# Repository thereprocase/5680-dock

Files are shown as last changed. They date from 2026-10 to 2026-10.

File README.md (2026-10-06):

# Precision 5680 desk dock

A compact, hinge-down stand built around its cooling plenum. Two recessed fans draw from the laptop's hinge exhaust, and a captured USB-C plug makes the final sideways docking connection.

> **Current prototype:** D9 P5 is the active print build. It uses an 8° lean,
> modular contact cassettes, split plenums and printed connections. The plug
> positioner now rides a large-shaft face clamp: a hollow Ø50 shaft offset 25 mm
> from the accessory socket so the arm actually reaches the USB-C ports, a
> knurled Ø72 nut on a printed 47 × 3 thread, a leaf-lobe cam spatula that takes
> the docking push, and a carrier that clamps the plug on its overmold flats
> (`desk-dock/D9-P5/CLAMP-PIVOT-VALIDATION.md`). Physical fit, clamp torque,
> loading, cooling and acoustics are still being qualified. See the
> [project page](https://thereprocase.github.io/5680-dock/),
> [P5 notes](docs/printables/d9-p5/README.md) and
> [print log](https://thereprocase.github.io/5680-dock/prints/).

**17 September checkpoint:** the V4 full-height A/B/C fit kit (filed locally) is toolpath-verified and ready for a supported contact test. The reported seating failure remains unresolved. **D9 is unfinished**: its diagnostic duct failed enclosure/print geometry, and the next panel construction exists only as a plan. No D9 airflow or acoustic improvement has been demonstrated.

**[Handoff, evidence and ordered next steps](https://thereprocase.github.io/5680-dock/handoff-2026-09-17.html)** · [Detailed next-step list](docs/handoff/2026-09-17/NEXT-STEPS.md)

D8 remains the last complete CAD reference with the connector mechanism. The earlier nominal CAD/manufacturing checks below do not establish physical seating, strength or cooling.

**[Explore D8](https://thereprocase.github.io/5680-dock/)** · **[Download D8 STEP](docs/downloads/Precision_5680_D8_STEP.zip)** · **[Print + source package](docs/downloads/Precision_5680_D8_Review.zip)** · **[Assembly and adjustment](desk-dock/D8/README.md)** · **[P1S print guide](desk-dock/D8/PRINT_DESIGN.md)**

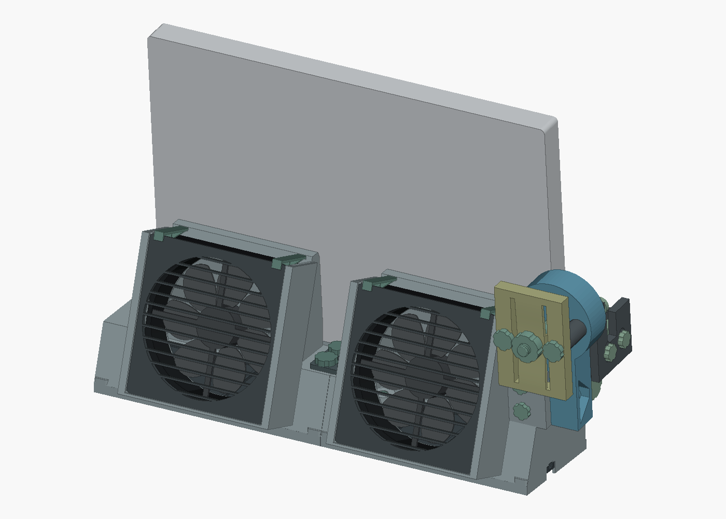
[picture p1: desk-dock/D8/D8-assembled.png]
D8 assembled dock with laptop envelope, recessed fans and removable connector module


## Form follows the load and the print

- **Removable connector module.** A keyed shoe and two accessible hand screws secure the complete mechanism. The cable cradle slides ±3 mm in Y, the saddle slides −4/+5 mm in Z, and an independent stop sets the laptop's X position. Adjust the existing parts directly.
- **Gravity through the shell feet.** Perimeter walls and dedicated feet carry the laptop. Bottom covers provide service access and clear the structural feet.
- **Lighter covers.** A 2 mm skin, perimeter ribs and compact fastening bosses reduce the two covers from about 180 g to 94 g of PETG—approximately 48% less plastic.
- **Serviceable fans.** Two nominal 120 × 120 × 25 mm fans sit behind flat slide-in grilles and replaceable clips. Documented clearances accommodate the researched frame sizes; a perimeter gasket is optional.
- **Deliberate print orientations.** All 43 manufacturing meshes specify a bed face and explain the layer-strength tradeoffs. Flat grilles and in-plane flexures print separately; shell ribs and underside ramps provide bridge landings and reduce overhangs.

The laptop retains its 5° lean, and the fans discharge 18° above the desk. The resettable face-cam hinge and printed preload spring remain. Their measured release force and warm creep still need testing.

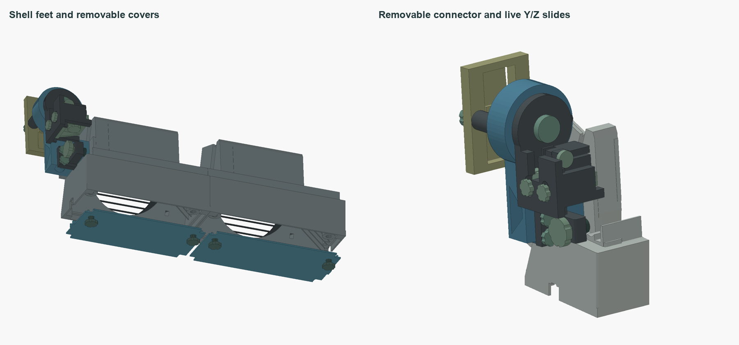
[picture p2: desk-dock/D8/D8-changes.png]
D8 shell feet and removable covers beside the connector module and live Y/Z slides


## Plastic and print preparation

The starting process is **P1S, PETG, 0.4 mm nozzle, 0.20 mm layers, five walls and six top/bottom layers**, with dense loaded mechanism parts. Use OrcaSlicer for the actual printer setup.

| Material estimate | PETG |
|---|---:|
| Finished CAD solid volume | 1.243 kg |
| Generic slice, including normal supports and individual brims | **1.659 kg** |
| First-build allowance, including some samples and reprints | **1.8–2.0 kg** |

The generic offline Cura screen estimates about 380 g of support and 25 g of brims at 1.27 g/cm³ PETG. Flexible contacts and startup waste are additional. These are planning figures; the final P1S profile controls actual use. Shell supports remain the largest print optimization opportunity. A reduced-support trial produced long roads in the wrong bridge direction, so its smaller material estimate was rejected.

## What the checks establish

All **83 assembly solids** pass CAD validity checks, with no unintended nominal rigid collisions. All **43 print meshes** are watertight and fit the recorded P1S envelope with an 8 mm brim. The 12 sampled laptop docking/withdrawal positions and listed module/cover service positions pass their clearance checks.

These checks do not establish physical strength or an approved P1S print job. Print fit samples first, inspect bridge direction and support removal, then test the complete holder. The ≤0.20 mm deflection at 20 N and nominal 50 N release remain test targets. See the [current results and remaining work](desk-dock/D8/CURRENT_STATUS.md).

## Build, inspect, continue

| Start here | What it contains |
|---|---|
| [D8 source and assembly](desk-dock/D8/README.md) | Editable CAD, adjustment and service instructions, regeneration commands |
| [Print design](desk-dock/D8/PRINT_DESIGN.md) | P1S process assumptions, every orientation and remaining support checks |
| [Print manifest](desk-dock/D8/print-manifest.json) | Per-part geometry, material, pose and mesh records |
| [Fan fit](desk-dock/D8/FAN_FIT.md) | Manufacturer dimensions, tolerances and clip allowance |
| [Generation provenance](desk-dock/D8/generation-provenance.json) | Source and export hashes tying the files to the checks |
| [Project context](PROJECT_CONTEXT.md) | Design decisions, coordinates, history and continuing work |

The STEP download is a lossless ZIP containing the complete CAD file. Individual STLs already use their manufacturing orientations. The source remains editable in CadQuery.

## Earlier revisions

The [archived D7 viewer](https://thereprocase.github.io/5680-dock/desk-dock-d7.html) and its [review archive](docs/downloads/Precision_5680_D7_Review.zip), earlier desk-dock studies and [original 5560 wall-mount overview](docs/history/5560-README.md) remain available as history. Use the D8 files above for current work. See [LICENSE](LICENSE).

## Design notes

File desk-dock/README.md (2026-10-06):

# Precision 5680 desk dock

Current local design: [D7 - recessed fans and hand assembly](D7/README.md).

5 degree laptop lean, 18 degree fan discharge, source-handed Thunderbolt ports, direct plenum support, recessed fan pockets, removable duct floors and hand controls. PETG on the P1S; print-oriented parts and fit samples are supplied. Slicing remains unverified after application startup failures.

[Port study](D6/PORT_STUDY.md) · [Compact-depth airflow screen](D6/AIRFLOW_STUDY.md) · [Viewer](../docs/desk-dock.html)

D1-D6 are retained as history. D5 has a known mirrored port layout. Use the repository root Open-Desk-Dock.ps1 launcher for the local viewer.

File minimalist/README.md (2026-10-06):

# Minimalist M1.1 native fork

M1 is an independent open-frame prototype derived through a FreeCAD Save As of
the preserved Rev H document. Its arms, fan cradles, caps, dam and hardware are
new. No prototype arm freeze applies to this fork or to future ducted designs.

[Illustrated print and assembly guide](https://thereprocase.github.io/dell-5560-wall-mount/minimalist-guide.html) ·
[Interactive dimensioned examples](https://thereprocase.github.io/dell-5560-wall-mount/#m1-model) ·
[Nominal package](../docs/downloads/Minimalist_M1_5560.zip) ·
[Fit coupon package](../docs/downloads/Minimalist_M1_Fit_Coupons.zip)

## Reinforced wall transition (M1.1)

Each wall pad is now 32 mm tall with two 6 mm webs tapering 16 mm forward.
The webs reach the flat print face through the arm’s full thickness, filling
the adjacent window roots. Existing arm material, bolt centers, bores and
print orientation are preserved. The dam has a matching tapered clearance
notch; all six sizes pass all nine indexed positions.

When upgrading, replace arms 01/02 and optional dams 07/08 together. The other
sixteen parts are geometrically unchanged. The nominal full set is 400.55 g /
15 h 42 m 30 s in Orca, adding 12.50 g / 17 m 36 s compared with M1.0.
See the [illustrated comparison](../README.md#m11-carry-the-wall-pad-into-the-arm)
and `reports/wall-transition-review.json` for native layer sections and limits.
The 192 to 416 mm² section increase is not a tested strength multiplier.
To reproduce that comparison, extract `minimalist/presets/` from commit
`64fc1aa` to a separate directory, then run `wall_transition_review.py` with
`--baseline-dir` pointing to its six original preset directories. The current
native files stay untouched. `plot_wall_transition.py` renders the report.

## Open and edit

Open `Laptop_Wall_Mount_Minimalist.FCStd` in FreeCAD 1.1. The model contains
55 fully constrained sketches, stock Part construction features, a shared
Spreadsheet and 20 installed App::Links. It has no custom feature proxy that
must be installed to reopen or recompute it. Construction history is grouped by
part family; the installed assembly is separate from the hidden source features.

Open **M1 / Design parameters**, edit the blue measured case inputs, recompute,
and Save As a new file. Gray cells are derived. The parameter sheet documents
the 0.30 mm printed fit clearance and intentional split-crown interference.
The reference uses a 344.4 × 230.3 × 20 mm closed case, a 40 mm wall gap and
separate 2 mm compliant pads. The two cradles accept the modeled 120 × 120 ×
27 mm fan envelope and point it 45° up the rear gap.

The six checked examples in `presets/` span 304–400 mm case width, 210–275 mm
depth and 16–28 mm thickness. They are specific dimensioned examples, not a
continuous certified compatibility range. Screen diagonals are labels only.
Each preset has nine checked dam positions, indexed 0–8 on a 12 mm ladder.
All six delivered files also passed a live GUI open check with the installed
assembly visible and the source construction hidden.
The key engages two rungs 24 mm apart; both sides must use the same index.

## Files and plates

- `presets/<name>/M1.FCStd`: saved/reopened native preset.
- `presets/<name>/print/01–20`: individual oriented STEP, STL and standard 3MF.
- `21_all_hardware`: one plate containing all twelve parts numbered 09–20.
- `22_hardware_without_dam`: eight hardware parts; use with 01–06 for seven
  plates when omitting the optional dam.
- `M1_assembled.step`: installed assembly for inspection, not a print plate.
- `coupons/00_fit_coupon_plate`: compact samples of the actual key, keeper,
  arm/carriage, fan-hanger and cap-pin interfaces in their full-part build directions.
- `reports/release.json`: settings, slice estimates, source hashes and checks.
- `reports/toolpaths/`: deposited-path measurements and source G-code hashes.
- `section-review.json`: explicit load assumptions and nominal stress demand.

Print one each of 01–08 plus 21, for nine plates. Files 09–20 are replacement
alternatives; do not also print them. STEP, STL and geometry-only 3MF represent
the same part. The standard 3MFs have no slicer settings or G-code.

Each delivery ZIP includes an offline illustrated guide, native model, print
files, separately labeled Orca previews, settings and verified SHA256SUMS.
Nothing has been sent to a printer. Start with the coupon and your actual
ASA spool profile in OrcaSlicer; see the guide for orientation and assembly.

## Reproduce the checks

FreeCAD-side scripts use the application's bundled Python/modules. On Windows,
for example, use `"C:\Program Files\FreeCAD 1.1\bin\python.exe"` in place of
`FREECAD_PYTHON` below. Run from the repository root. Python paths are examples;
use the installation path on your machine.

```text
FREECAD_PYTHON minimalist/validate.py
FREECAD_PYTHON minimalist/presets.py
FREECAD_PYTHON minimalist/coupons.py
FREECAD_PYTHON minimalist/section_review.py
FREECAD_PYTHON minimalist/export_scene.py
```

Headless preset saves preserve the original GUI payload order through
`preserve_gui.py`, leaving geometry and parameter streams intact. Run
`gui_presets.py` from FreeCAD’s GUI Python environment to repeat the display
check before packaging regenerated files.

The construction builder is incremental and preserves existing part families.
For a clean reconstruction that leaves the delivered model untouched:

```text
FREECAD_PYTHON minimalist/build.py all --target minimalist/scratch/Rebuilt_M1.FCStd
FREECAD_PYTHON minimalist/validate.py --source minimalist/scratch/Rebuilt_M1.FCStd --output minimalist/rebuild-validation.json
FREECAD_PYTHON minimalist/compare_rebuild.py
```

`slice_models.py` uses the official Orca CLI and flattens its bundled P1S,
0.20 mm and ASA profiles. It preserves orientation/placement and never sends
a print. Example for the nominal set, with paths to your Orca installation:

```sh
python3 minimalist/slice_models.py --orca /path/to/OrcaSlicer \
  --profiles /path/to/resources/profiles/BBL \
  --output minimalist/slices/5560 \
  minimalist/presets/5560/print/0[1-8]*.stl \
  minimalist/presets/5560/print/21_all_hardware.stl
```

Repeat for each preset and the coupon. `audit_plates.py` requires Shapely and
Matplotlib. It analyzes all deposited path types, and reuses a result only when
the parsed path geometry, feature types, layer heights and widths are identical.
The package builder requires all six sets and the Rev H comparison slices:

```text
python3 minimalist/audit_plates.py
python3 minimalist/package_release.py --revh-slices /path/to/revh/comparison/slices
```

`browser_review.cjs` uses Playwright from `freecad/showcase/tooling` and Windows
Edge to check both interactive models, all presets, dam movement, mobile layout
and downloads. Install that folder's lockfile dependencies if needed, serve
`docs/` locally, then run it with the preview URL and `--full`.

## Evidence limits

Native validation checks valid one-solid parts, constrained sketches, unintended
part overlap, minimum intended interface gaps, rectangular case/fan envelopes,
wall intrusion and sampled removal motions. All nine dam indices are checked;
case and fan removal samples are run at the two end indices. A clean CAD result
does not prove a continuous insertion path with cables or real protrusions.

Orca's Bridge label excludes some slot roofs generated as Overhang wall. The
expanded toolpath report therefore includes every deposited feature type and
retains bridge-tagged and all-feature maxima separately. Prior-layer support is
estimated from reported line width with at least 0.05 mm overlap. Same-layer
anchoring order, adhesion and physical sag are not proven. Use the fit coupon
to check the key-slot roofs and the fan hanger before the full print.

The section review assumes a 3 kg case, twice gravity and equal arm loading.
It calculates net upright areas and section moments from native solid slices.
The peak nominal axial-plus-bending demand is about 1.11–1.24 MPa across the
examples. This excludes local stress concentration, shelf/fastener FEA, ASA
allowables, creep, temperature and layer adhesion; it is not a load rating.

Physical fit, printed retention, wall anchors, long-term deformation and cooling
performance remain unqualified. M1 has no CFD or cooling benchmark. Rev F's
exploratory CFD must not be presented as a result for M1 or Rev H.

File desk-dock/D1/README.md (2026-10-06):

# Precision 5680 / hinge-down extraction dock

**Superseded orientation:** [D3](../D3/README.md) corrects the reversed port end. Use [D4](../D4/README.md) for the current CAD and docking animation.
[STEP review package](Precision_5680_D1_Review.zip) · [Connector adjustment](adjustment.png) · [Air-path section](air-path.png) · [Source geometry](reference-evidence.png)

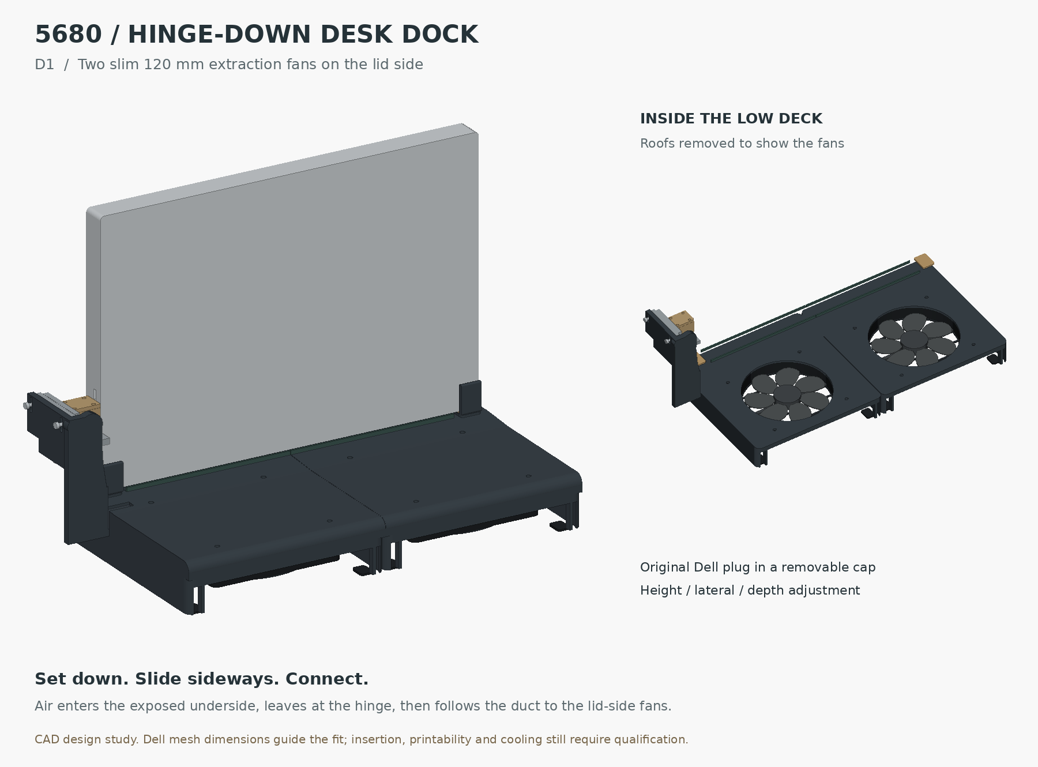
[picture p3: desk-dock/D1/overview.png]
D1 installed and with fan-chamber roofs removed


Set the closed laptop into the corner bearings, **hinge down**, then slide it
sideways into the captured SD25TB5 plug. Two slim 120 mm fans lie flat on the
**lid side**, pulling from a duct that curves underneath the hinge. The broad
underside intake remains exposed. A skirt directs the fan discharge toward the
lid side along the desk.

The main deck reaches **50 mm above the desk**. The rear-case bearing datum
sits at 54 mm; the selected port center sits at about 120 mm. The small plug
support tops out at 135 mm, only 81 mm above the rear-case datum. The modeled
overall footprint is approximately 406 × 188 mm, including the plug support.
The fan housings add useful desk bearing width on the lid side.

**D1 is a developed CAD study, not a print release.** The actual duct passage,
mounting bores, adjustment clearances and separate load stop are modeled.
Fastener/nut retention, all attachment details, strain relief, liner compression,
automatic lift protection and physical thermal/fit qualification remain open.

## Fine adjustment after assembly

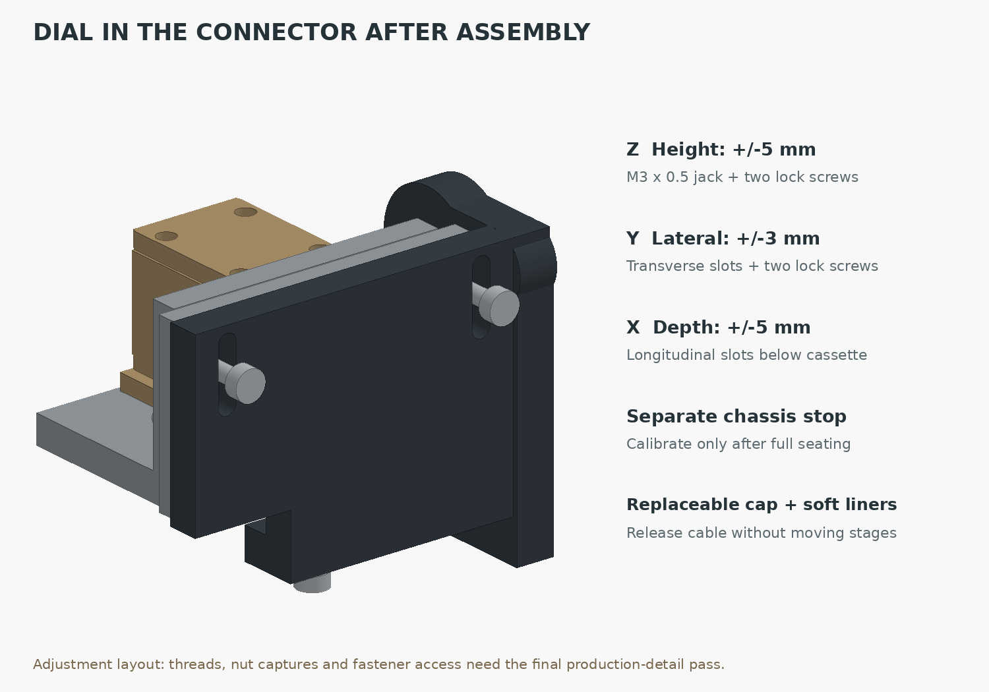
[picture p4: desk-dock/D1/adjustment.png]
Connector cassette and its adjustment stages


| Axis | Adjustment | How it stays put |
|---|---|---|
| Z: port height | M3 × 0.5 jack, ±5 mm; 1 turn = 0.5 mm | Two independent face clamp screws |
| Y: position across laptop thickness | Transverse slots, ±3 mm | Two independent clamp screws |
| X: engagement depth | Longitudinal cassette slots, ±5 mm | Two screws through the bottom shelf |
| Laptop travel limit | Independent M4 chassis stop | Locknut; soft contact tip |
| Plug replacement | Removable cap | Carrier settings remain fixed |

The adjustment range is for setup; the stages lock before everyday docking.
The cap holds replaceable compliant liners around the overmold. The modeled
rear shoulder bears on the transition to the strain-relief neck. A proposed
0.8 mm metal face clip captures the front shoulder without requiring a thick
printed wall between the plug and laptop. Its fabrication and attachment need
detailing; its thickness must be included when setting full engagement.

An initial setup uses the actual laptop as the alignment jig: retract the
chassis stop, seat the laptop on its bearings, leave the stages just loose
enough to move, and engage the plug by hand. Set Z and Y without side load,
set X for normal full engagement, lock the stages, then bring the independent
stop to the chassis. Slide out and repeat before normal use. The USB-C shell
must never function as the bearing, alignment funnel or end stop.

The ±5 mm Z range targets the **nearer** Thunderbolt port. Using the second
port requires changing the nominal height by about 16.2 mm in the CAD; the
fine-adjustment range does not span both ports. Angular setup error is handled
by the compliant cassette liners and guide fit, not by claiming a rotary stage.

## What the online geometry established

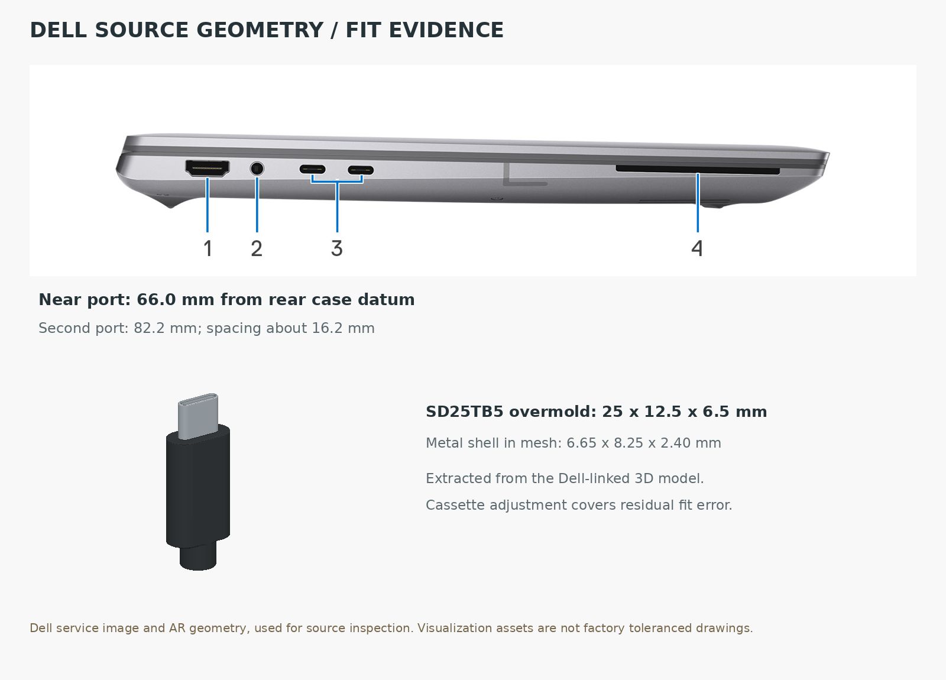
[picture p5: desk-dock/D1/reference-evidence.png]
Dell service side image and extracted plug mesh


Dell's product pages link actual glTF assets for their 3D/AR viewers. We
downloaded those, applied the laptop scene transforms, and extracted the
connector meshes. The laptop body width in the model is 353.680 mm, matching
the published width. These are visualization assets, not toleranced factory
drawings; the mechanical adjustments deliberately cover residual error.

| Feature | Extracted result | Basis |
|---|---:|---|
| Near left Thunderbolt center | 65.98 mm from rear **base-cover** datum | `Dell4768` transformed bounds |
| Other left Thunderbolt center | 82.19 mm from same datum | `Dell4694` transformed bounds |
| Port spacing | 16.21 mm | Difference between centers |
| SD25TB5 main overmold | Approximately 20 × 12.5 × 6.5 mm | `Cube_8`; excludes 5 mm neck |
| Overmold plus neck length | 25 mm | Full `Cube_8` bounds |
| Exposed metal shell | 6.65 × 8.25 × 2.40 mm | `Cube_9` bounds |

Scaling Dell's service side image against 240.33 mm depth independently gives
approximately 66.03 and 82.18 mm. That agreement supports the layout, but does
not turn the images into a production tolerance. The outer hinge lip projects
past the rear base-cover datum; bearing pads support the case corners and
leave the hinge/exhaust region relieved. The reference laptop remains a
simplified closed envelope rather than an exact manufacturer solid.

[Raw extraction record, source URLs and SHA-256 hashes](reference-extraction.json).
The extraction script records the vertex bounds and source image pixel picks.

## Suction below the hinge

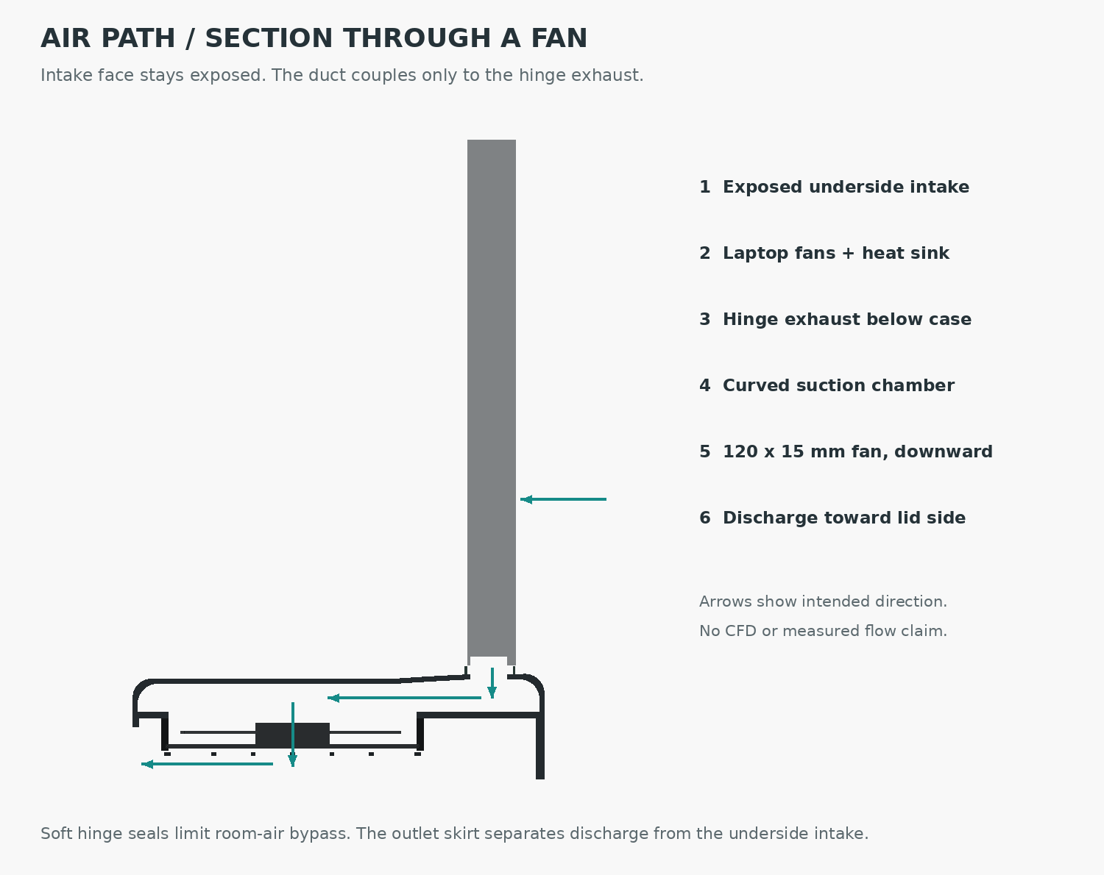
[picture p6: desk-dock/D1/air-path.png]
Section through the first fan


The intended flow follows the laptop's existing forced ventilation direction:
room air enters the exposed underside grille, the internal blowers drive it
through the heat sink, and the external fans lower the pressure in the chamber
at the hinge exhaust. Hinge-down operation does not create a passive chimney;
this concept relies on the laptop's blowers and the powered extraction fans.
The service illustrations support this flow-path interpretation, but they do
not supply internal fan curves or quantify the chassis resistance.

The curved chamber covers the exhaust region only. Thin replaceable sealing
lips limit room-air bypass around the hinge. They carry no laptop bearing
load. The two chambers use one fan each, with the fan faces entirely on the
lid side. Their outlet skirts block direct discharge toward the intake face.

The dimensional baseline is two **Noctua NF-A12x15 PWM** fans: 120 × 120 × 15 mm,
105 mm hole spacing, 12 V. Noctua lists 55.44 CFM free-air flow and 1.53 mm H₂O
(about **15 Pa**) maximum static pressure per fan. Those are opposite endpoints,
not simultaneous performance. Two fans in parallel add available flow; they do
not double maximum pressure. The model uses generic rotor geometry and colors.
If retaining the manufacturer's vibration pads, allow the additional pad
thickness and set the fan-deck gasket accordingly.

At an **assumed** total 20 CFM, the roughly 5,000 mm² under-hinge opening would
carry about 1.9 m/s, with about 2.1 Pa velocity pressure. Losses through the
turn, grille, desk outlet and seal leakage consume part of the fan's small
pressure budget. This is a dimensional estimate, not a solved operating point.
For scale, a 0.5 mm equivalent gap around a 634 mm seal perimeter would bypass
about 1.8 CFM at an assumed 10 Pa suction (Cd 0.65; air density 1.2 kg/m³).
A 3 mm gap would bypass about 10.7 CFM under the same assumptions. A good hinge
interface matters more than adding unrestricted fan capacity.

Use a regulated 12 V supply and a PWM controller/splitter for the fan pair;
final harness routing and retention remain to be designed. Test one and both
fans off as well as normal operation: the duct must not worsen the baseline
when the external fans stop. No new CFD or measured cooling result is claimed.

## Checks completed and remaining work

- Each exported component is a valid solid, and the STEP reimports successfully.
- The rigid custom parts have no unintended intersections in the nominal CAD.
- The five principal adjustment parts clear one another at 27 sampled
  combinations of the specified X/Y/Z limits. The screen excludes the laptop,
  fastener head access and nut engagement; it does not prove precise insertion.
- The source images, plug mesh and rendered CAD views were inspected.

[Machine-readable validation](validation.json) · [Part geometry](geometry.json).
The two fan modules suit a segmented P1S build, but the left deck with its
integrated connector support still needs a build-orientation and bed review.
Use OrcaSlicer, the repository default, for the production detailing pass.

Next physical checks: align and lock the connector; verify engagement and
withdrawal without shell loads; test retention and accidental lift; qualify
the desk restraint and warm printed structure; measure chamber pressure and
laptop CPU/GPU temperatures/power at the same workload with the external fans
off, low and high. Until an interlock is detailed, disconnect sideways before
lifting. A fit coupon should precede the complete print.

## Sources

- [Dell Precision 5680 product page](https://www.dell.com/en-us/shop/dell-laptops/precision-5680-workstation/spd/precision-16-5680-laptop): published envelope and discovery of the [Dell-linked laptop mesh](https://content.hmxmedia.com/precision-16-5680-laptop-AR/gltf/precision-16-5680-laptop-AR.glb).
- [Dell 5680 left view](https://www.dell.com/support/manuals/de-ch/precision-16-5680-laptop/precision-5680-owners-manual/left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): identifies the two Thunderbolt ports and supplies the side image.
- [Dell 5680 Owner's Manual](https://dl.dell.com/content/manual19946365-dell-precision-5680-owner-s-manual.pdf?language=en-us), pages 55 and 59: internal fan and heat-sink geometry; base-cover illustrations show the exposed intake grille and hinge region.
- [Dell SD25TB5 product page](https://www.dell.com/en-us/shop/dell-pro-thunderbolt-5-smart-dock-sd25tb5/apd/210-brqs/docks): discovery of the [Dell-linked dock/plug mesh](https://content.hmxmedia.com/dell-pro-sd25tb5-dock-AR/gltf/dell-pro-sd25tb5-dock-AR.glb).
- [Noctua NF-A12x15 PWM specifications](https://www.noctua.at/en/products/nf-a12x15-pwm/specifications): fan envelope, voltage and pressure/flow endpoints.

## Rebuild

Python 3.12, CadQuery 2.8, NumPy, Pillow and trimesh:

```bash
python desk-dock/D1/extract_references.py /tmp/dell5680-references
python desk-dock/D1/build.py
python desk-dock/D1/validate.py
```

`parameters.json` holds the design values. The source downloads stay outside
the deliverable; the repository retains the attributed inspection image and
dimension/hash record. D0 remains available through Git history.

## Revision brief

The user rejected D0's appearance and specified hinge down, a low profile,
two 120 mm fans that create suction below the hinge, and online reconstruction
of the required hardware geometry. They then placed the fans on the lid side
with a duct that curves below the machine and requested port fine adjustment
after fabrication. D1 implements that architecture and replaces D0 as the
current design study.

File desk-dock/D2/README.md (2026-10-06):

# Precision 5680 desk dock — D2

**Superseded orientation:** [D3](../D3/README.md) corrects the reversed port end. Use [D4](../D4/README.md) for the current CAD and docking animation.
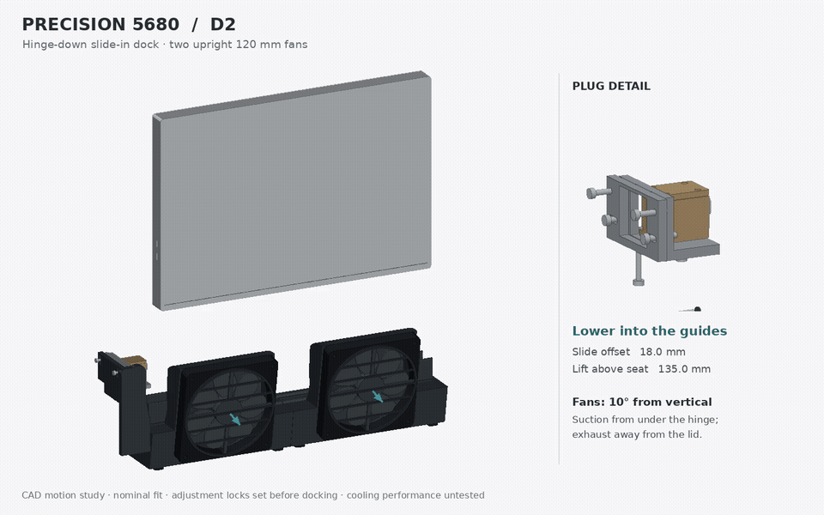
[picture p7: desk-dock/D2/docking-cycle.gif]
Docking cycle


[Full-resolution MP4](docking-cycle.mp4) · [STEP and editable source package](Precision_5680_D2_Review.zip) · [Poster](overview.png)

Two 120 × 120 × 15 mm fans now stand **10° from vertical** on the lid side. Their suction faces connect to two curved pods fed by the low manifold beneath the hinge. Their discharge points away from the laptop, 10° down. The broad underside intake face stays exposed. The fan tops reach approximately 131 mm; the connector support reaches 135 mm. The laptop's rear-case bearing datum remains 54 mm above the desk, with the selected port center approximately 120 mm above the desk.

The animation uses the actual D2 CAD solids and fixed cameras. It shows lowering at an 18 mm lateral offset, sliding toward the original SD25TB5 plug, pausing docked, withdrawing 18 mm, then lifting. A synchronized close-up shows the connector approach. The 135 mm lift is a presentation distance, not a required docking stroke. Arrows indicate intended discharge direction, not measured airflow.

The hinge corner bearings are longer so both ends stay supported throughout the 18 mm slide. The inherited connector shelf was shortened to remove an interference found during the docking-path check. The original cable overmold remains captured by a removable cap and front clip. Independent depth, transverse and height adjustments retain the D1 nominal ranges: ±5, ±3 and ±5 mm. Set and lock these before docking; the separate chassis stop controls final travel. Only the nominal adjustment setting is animated.

## Evidence and limits

Dimensions and selected port location retain the [D1 Dell reference extraction](../D1/README.md) and [reference evidence](../D1/reference-evidence.png). These come from Dell-linked visualization assets and service images, not toleranced manufacturing CAD. Laptop and cable bodies are simplified envelopes. The dock electronics remain external; this design captures its host cable plug.

`validation.json` records a changed-geometry screen: individual solid validity, STEP round-trip validity, stationary custom-part and fan-envelope intersections, and 12 laptop positions through the nominal lower/slide path. Intentional internal overlaps among the schematic fan components are excluded. This is sampled envelope screening, not a continuous swept-volume or physical mating qualification.

**CAD motion study, not a print release.** Fan mounting fasteners, guard attachment, split-manifold joinery, seals, cable strain relief, anti-tip behavior, printed fits and load testing still need production detailing. Actual full USB-C engagement must be calibrated on the hardware without using the connector as a structural stop. Air leakage, fan/system operating point and temperature benefit have not been tested. D1 adjustment-range screening is historical evidence; the complete D2 adjustment sweep has not been requalified.

## Reproduce

With Python, CadQuery 2.8, NumPy, Pillow and ffmpeg installed:

```sh
python build.py
python validate.py
python animate.py
```

`animate.py` writes 114 frames at 12 fps (9.5 seconds), a full-resolution 1440 × 900 MP4 and a looping 960 × 600 GIF. The review archive contains the STEP, parameters, CAD and rendering sources, validation results and poster. Animation files are linked separately. Use OrcaSlicer for subsequent print preparation, per repository guidance.

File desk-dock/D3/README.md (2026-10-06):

# Precision 5680 desk dock — D3

**Superseded by [D4](../D4/README.md):** retains this orientation, reverses the fan lean to 15° upward exhaust, and enlarges the rounded air passages.

D3 corrects the laptop handedness to match the supplied desk photograph. The laptop sits to the user's left, hinge down, with its lid facing the user. Its **keyboard-left ports sit at the far end: the right edge in the lid-facing photograph.** D1 and D2 placed that edge on the wrong end.

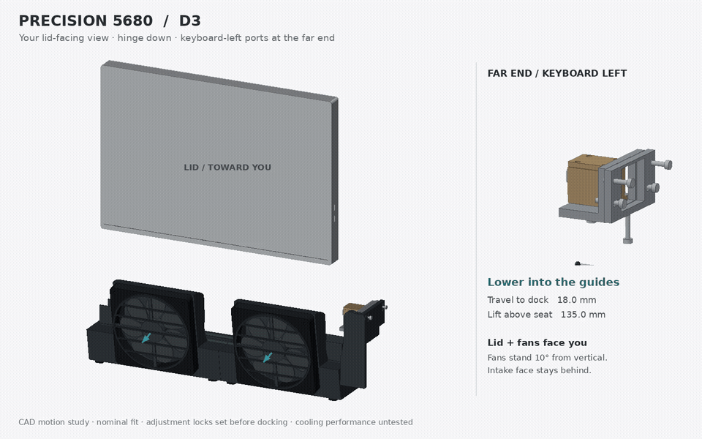
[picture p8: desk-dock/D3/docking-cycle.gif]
Corrected docking cycle, viewed from the lid side


[Full-resolution MP4](docking-cycle.mp4) · [STEP and editable source package](Precision_5680_D3_Review.zip) · [Poster](overview.png)

## Orientation and movement

| Feature | Correct placement |
|---|---|
| Hinge | Down, in the trough |
| Lid | Toward the seated user |
| Underside intake grille | Behind the laptop, opposite the user and fans |
| Two 120 mm fans | Lid/user side, 10° from vertical |
| Keyboard-left Thunderbolt ports | Far end; photo right |
| SD25TB5 host cable clamp | Beyond that far edge, pointing back into the laptop |
| Dock | Lower into the guides, then slide toward the far plug |
| Undock | Withdraw toward the near end, then lift |

The exported CAD uses +X toward the far/plug end, +Y toward the lid/user/fans, and +Z upward. The near laptop edge is x=0; the far edge is x=353.68 mm. Docking moves the laptop from x-offset −18 mm to 0; removal reverses this. The 135 mm lift in the animation illustrates removal and is not a required docking stroke.

D3 reflects the actual CAD solids across the laptop's mid-width plane, including the port openings, plug, adjustment stages, chassis stop, extended bearings and ducts. It does not merely reverse the animation camera. `build.py` explicitly separates the inherited D2 construction coordinates from the corrected exported frame. The two fan centers remain symmetric; the cable support moves to the far end.

## Retained design

The rear-case bearing datum stays 54 mm above the desk. The selected port center stays approximately 120 mm above the desk. Two curved suction pods connect the under-hinge manifold to the near-vertical fans, which discharge toward the lid/user side, 10° down. The underside intake remains exposed. The plug retains independent depth, transverse and height adjustments, with nominal ranges ±5, ±3 and ±5 mm, and an independent chassis stop. Lock the adjustments before docking.

The supplied photograph establishes orientation, not scale. Laptop and plug dimensions retain the [Dell-linked D1 reference extraction](../D1/README.md) and [geometry evidence](../D1/reference-evidence.png). The laptop and cable remain simplified reference envelopes; the dock electronics remain external.

## Verification and limits

The geometry check verifies both far-edge port voids, corresponding solid near-edge locations, the far-side plug shell, and fan positions on the lid side. This checks the handedness separately from collision screening: a mirrored model can pass ordinary clearance checks.

The corrected assembly contains 53 valid solids and survives STEP export/import. Custom rigid parts and fan envelopes have no detected nominal intersections. Twelve sampled laptop positions along the corrected lower/slide path have no detected collisions. `validation.json` records these results. Intentional overlaps within schematic fan references are excluded.

**CAD motion study, not a print release.** Physical USB-C engagement, complete adjustment travel, fan and guard attachment, manifold joinery, seals, cable strain relief, stability, printed fits and loads still need qualification. Intended airflow arrows do not establish cooling benefit. The supplied desk photograph is not included in the repository.

## Reproduce

Use Python with CadQuery 2.8, NumPy, Pillow and ffmpeg:

```sh
python build.py
python validate.py
python animate.py
```

The animation runs 9.5 seconds at 12 fps. The MP4 is 1440 × 900; the looping GIF is 960 × 600. The review archive includes the STEP, source, parameters, validation, report and poster; animations are separate. Use OrcaSlicer for subsequent print preparation.

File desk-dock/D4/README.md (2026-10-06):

# Precision 5680 desk dock — D4

**Superseded by [D5](../D5/README.md):** retains the upward-exhaust concept and adds profiled fixed guides, open ribs and rubber-foot sweep clearance.

The fans now exhaust **15° above the desk**, with their tops leaning toward the laptop. D4 also enlarges the plenum, widens and rounds the hinge openings, and replaces the close flat guard with a spaced rounded-wire guard. The corrected orientation remains: hinge down, lid and fans toward the user, keyboard-left ports at the far end (photo right).

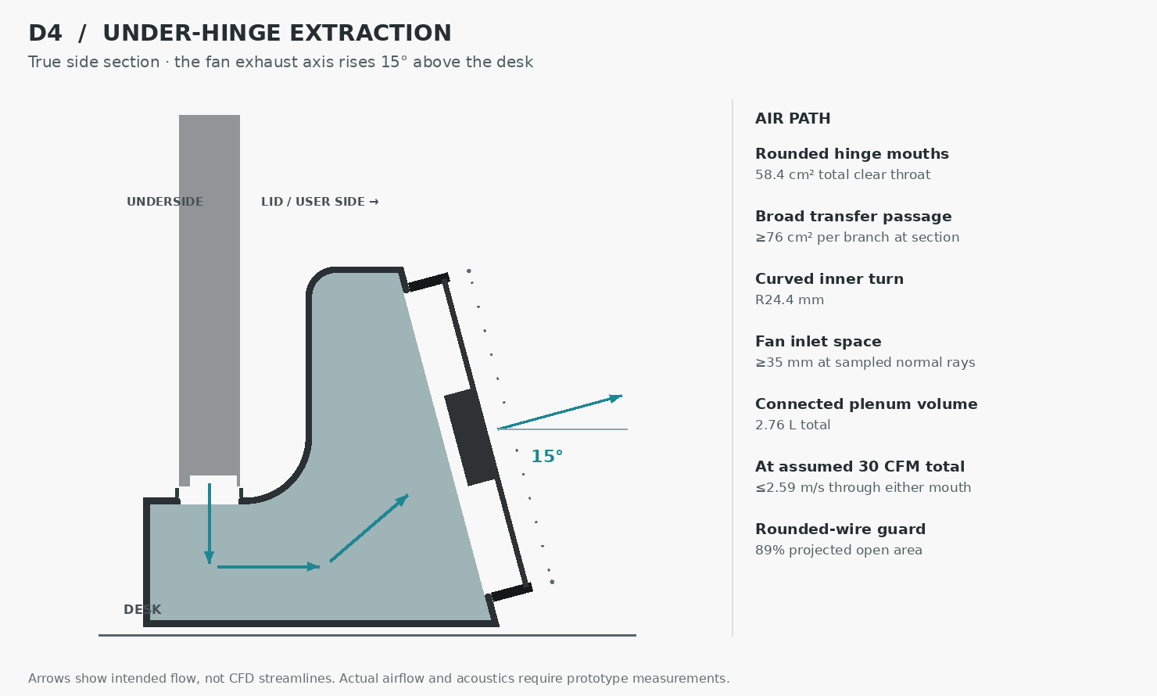
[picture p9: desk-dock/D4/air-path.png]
Side section through the hinge and one fan


[Docking animation](docking-cycle.gif) · [Full-resolution MP4](docking-cycle.mp4) · [STEP and source package](Precision_5680_D4_Review.zip) · [Installed view](overview.png)

## Air passage sizing

**Design basis: 30 CFM total**, assuming 15 CFM per fan. This is a sizing target, not a measured or predicted operating point. The table reports dimensions from the CAD and the smaller branch where branches differ.

| Feature | D4 geometry / screen |
|---|---:|
| Total connected cavity volume, both independent branches | 2.76 L |
| Hinge throat clear area | 5,840 mm² total |
| Individual mouths | 130.84 × 21 and 148.54 × 21 mm |
| Mouth corner / edge radii | R4 / R1 mm |
| Transfer section at y=15 mm | 7,566 / 8,312 mm² |
| Inner curved turn | R24.4 mm |
| Fan inlet axial clear space | 57 mm |
| Minimum inlet clear space across 81 sampled normal rays per fan | 35 mm |
| Fan aperture | Ø113 mm, rounded R1 at wall edges |
| Guard wire / pitch | Ø1 / 9 mm, 8 mm gaps |
| Guard plane beyond discharge face | 7.5 mm |
| Guard projected open area within fan aperture | 88.8% |
| Hinge bearing datum above desk | 54 mm, retained |
| Fan-pod height | 134 mm |

The wider plenum adds depth on the desk rather than lifting the laptop. The two cavities remain separate and each connects its hinge mouth to one fan. The 21 mm opening fits beneath the closed laptop envelope; replaceable soft lips flank it. The broad intake grille stays exposed behind the laptop. Gaskets and seam sealing must prevent narrow bypass jets and leakage that would divert suction from the hinge.

## Flow and pressure screen

We use continuity, `v = Q/A`, and local velocity pressure, `q = ρv²/2`, with air density 1.2 kg/m³. Each branch receives half the assumed total flow. The smaller branch governs.

| Assumed total flow | Maximum mouth velocity | Estimated external duct loss, smaller branch |
|---|---:|---:|
| 20 CFM | 1.73 m/s | 1.4–3.4 Pa |
| 30 CFM | 2.59 m/s | 3.2–7.6 Pa |
| 40 CFM | 3.45 m/s | 5.7–13.5 Pa |

Loss estimates combine assumed entrance, slot-jet mixing, turn, roughness, guard and discharge terms. `airflow.py` records their reference areas and sensitivity coefficients; `airflow-sizing.json` records the geometry and results. These bounds are engineering assumptions, not coefficients calibrated to this enclosure. They exclude the laptop grille, heat sinks, internal blowers and seal leakage.

The [Noctua NF-A12x15 PWM](https://www.noctua.at/en/products/nf-a12x15-pwm/specifications) lists 55.44 CFM maximum free-air flow and approximately 15 Pa maximum static pressure. Those are separate endpoints. Two parallel fans do not double the available pressure, and the 15 Pa endpoint does not establish pressure available at our target flow. Without a fan/system curve intersection or prototype measurements, the model cannot confirm 30 CFM. The 40 CFM case shows why simply running harder can consume most of the available pressure and increase noise.

## Noise provisions

The design uses broad openings with rounded corners and rolled edge radii, a curved return passage, inlet clearance across the fan face, an open discharge, and round guard wires spaced from the rotor. These choices follow the mechanisms described in [Fantech's installation guidance](https://www.fantech.com.au/Content.aspx?ContentID=L5&category=dos-and-donts): inlet restrictions and uneven flow can reduce performance and increase noise; ample inlet boxes and shaped entrances help. [Greenheck's system-effect guidance](https://www.greenheck.com/resources/blog/understanding-fan-system-effects) likewise emphasizes uniform entry and exit flow. This compact plenum does not provide the full straight-run or one-diameter clearance used by ideal installations.

Rounded entrance losses depend on geometry. [Purdue's minor-loss notes](https://engineering.purdue.edu/~wassgren/teaching/ME30800/NotesAndReading/PipeFlows_Losses_LectureNotes.pdf) supply the generic framework; the R1 lip here does not justify adopting the ideal well-rounded entrance coefficient. The pressure screen deliberately retains a wider assumed coefficient range.

**These provisions reduce likely noise sources; they do not prove whistle-free operation.** Print ridges, seal gaps, the laptop's actual exhaust openings, rotor tones and cavity resonance can still matter. Finish the inlet radii smoothly, keep seams flush and sealed, isolate fan mounts, and sweep PWM through the intended range on the prototype. Measure actual branch flow and suction pressure alongside sound and laptop temperatures. Check fans-off behavior too. If a tone appears, locate its source before changing speed or geometry.

## CAD and motion verification

D4 exports and reimports 53 valid solids. Nominal custom-part and fan-envelope intersections are clear; 12 sampled laptop positions pass the lower/slide/withdraw/lift screen. Separate checks verify the two far-edge ports and plug location. The animation still lowers at an 18 mm offset, slides toward the far plug, withdraws toward the near end, then lifts. Height, transverse and depth adjustment remain independent, with a separate chassis stop.

Laptop and plug dimensions retain the [Dell reference evidence](../D1/reference-evidence.png); the supplied photograph corrected handedness and was not used as a scale reference. The simplified laptop envelope does not establish the actual free area of its exhaust grille.

**CAD development study, not a print release.** Guard attachment, fan fasteners, manifold joinery, seals, cable strain relief, printed fit, stability and structural loads still need production detailing and physical qualification. The wire guard represents fabricated or bought metal hardware; it is not an instruction to print 1 mm guard rods.

## Reproduce

Python, CadQuery 2.8, NumPy, Pillow and ffmpeg:

```sh
python build.py
python validate.py
python airflow.py
python section.py
python animate.py
```

Use OrcaSlicer for subsequent print preparation. The STEP/source archive includes the calculations, section, poster and validation; animation files are linked separately. D1–D3 remain as revision history. D4 is the current design.

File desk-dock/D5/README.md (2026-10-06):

# Precision 5680 desk dock — D5

D5 uses **profiled fixed cheeks and an open rib frame**. The laptop leans 2° toward its lid-side guides, lowers into flared entries, then slides toward the far-end SD25TB5 plug. Rounded fan bezels, softened rear base corners and a removable adjustment cover clean up the enclosure.

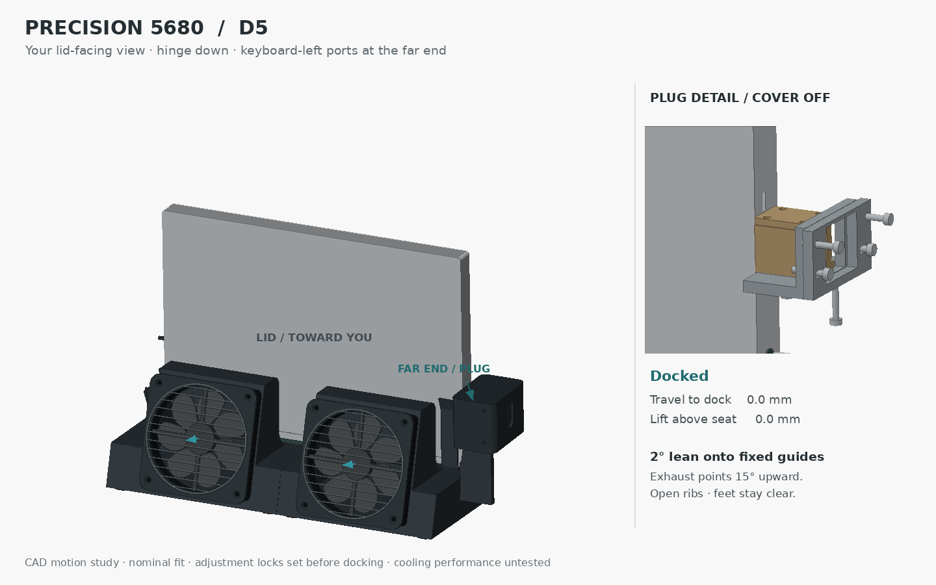
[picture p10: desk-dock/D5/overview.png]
Lid-side view


[Docking animation](docking-cycle.gif) · [Full-resolution MP4](docking-cycle.mp4) · [STEP and source package](Precision_5680_D5_Review.zip) · [Contact and rib study](contact-study.png)

## Contact geometry and alignment

The user accepted sliding directly against fixed cheeks and required clearance from the rubber feet. D5 therefore uses fixed case-margin guides; the sliding-carriage concept was dropped before publication.

Five cross-sections through Dell's base-cover mesh establish the hinge-end seat profile. The printed seat follows the lower envelope of those curves, with a separate 0.3 mm liner for fit and wear adjustment. The reference CAD replaces its generic rounded heel at those contact margins with the extracted envelope. The closed lid remains a simplified envelope based on the published thickness; the source is a visualization mesh, not factory toleranced CAD.

The two end guides establish separated bearing locations. The far guide extends to the port region and widens by 5 mm per face over its final 12 mm to catch the descending case. A near-end flared stop marks the loading bay. Once seated, the laptop slides 18 mm along the fixed seats and guide faces. The USB-C plug does not carry the intended guide or bearing loads. The separate chassis stop controls final travel; the plug cassette retains independent height, transverse and insertion-depth adjustment.

The whole laptop/contact/plug arrangement leans 2° toward the lid side. Gravity is intended to settle it against the lid-side guides while the hinge-end seats carry its weight. The fans retain their independent 15° upward discharge. Initial physical setup must establish the liner fit and plug calibration. The user controls the lower-then-slide sequence; this revision has no automatic sequencing lock.

## Rubber feet and open ribs

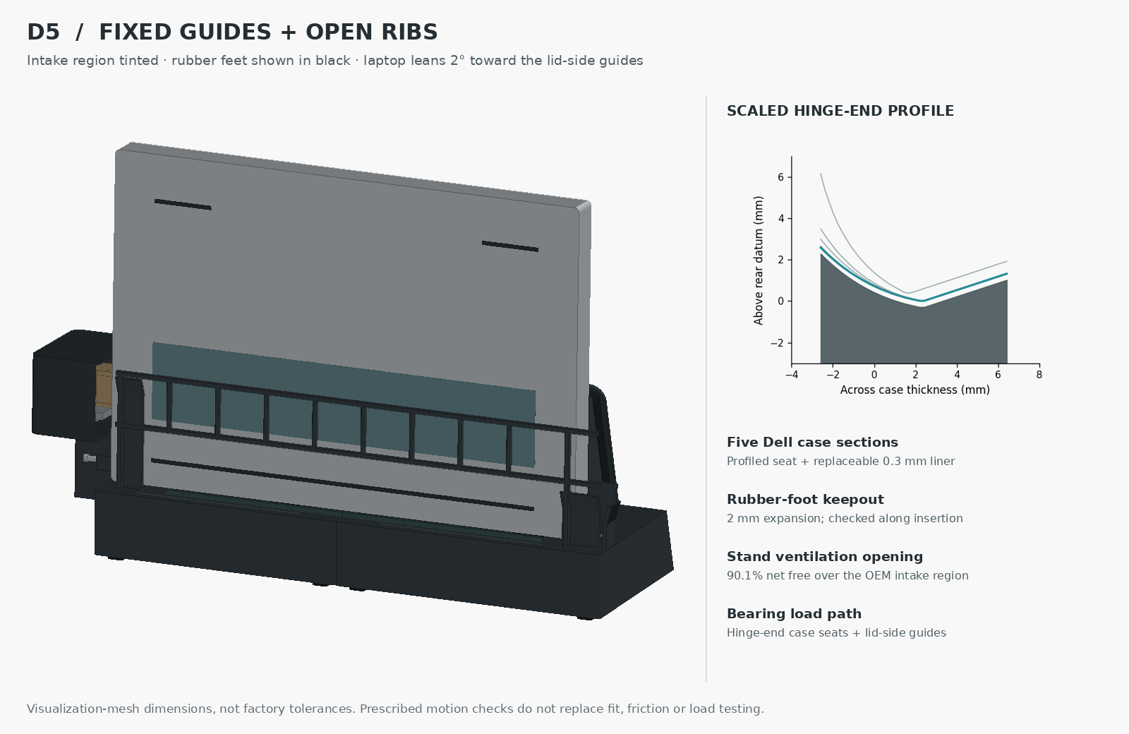
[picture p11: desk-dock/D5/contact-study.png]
Underside ribs and scaled hinge profile


Dell's mesh includes a long rear rubber strip roughly 17–20 mm from the rear-case datum, plus two front strips roughly 205–208 mm from it. The rear strip sweeps across much of the underside as the laptop lowers. Closely fitted ribs in that central sweep would catch it.

The bearing faces therefore land on the bare end margins. The central ribs brace those supports and sit behind the rubber-foot sweep. D5 includes all three foot envelopes and checks keepouts expanded **2 mm in every direction**, through lowering and sideways movement. These are reconstruction allowances, not statistical tolerances or measured hardware clearances.

The rib structure leaves **90.1% net free area** over the intake window extracted from Dell's grille mesh, exceeding the requested 80%. This percentage describes the added stand structure projected over the OEM intake region; it does not include the laptop grille's own solidity. The ribs stay above the hinge exhaust and do not cross the under-hinge extraction mouths.

## Aesthetic changes

- Rounded, countersunk fan bezels cover the frame edges while preserving the full fan aperture.
- A rounded removable shell conceals the plug stages and provides cable and tool-access openings.
- Flared guide lips and profiled seats replace the short square cheeks.
- A thin open back braces the end supports with limited blockage of the intake region.

The two fan cavities retain the D4 air-passage geometry and 15° upward exhaust. The [D4 sizing report](../D4/README.md) remains a conditional duct-sizing reference; the new laptop lean and sealing interface still require airflow and acoustic checks on hardware.

## Verification and limits

`validation.json` records 59 valid exported/reimported solids, nominal rigid-part clearance, far-edge port checks, 12 docking-path samples and expanded foot keepout checks. `alignment-validation.json` records the projected free area and 24 prescribed entry poses starting at −3, 0 and +3 mm cross-slot offset, centering before final seating. These selected paths clear the geometry and foot keepouts. They are not a gravity/friction simulation and do not demonstrate automatic correction from every placement or angular error.

The intended load path is case → profiled end seats / lid-side guides → fixed supports → desk. Strength, sliding friction, liner wear, tip stability, exact USB-C mating, cover retention, split-joint attachment and printed fits remain unqualified. **This is a CAD development revision, not a print release.** Use a contact/connector coupon before a complete print, and use OrcaSlicer for print preparation.

## Source and reproduction

`contact-profiles.json` records source SHA-256, five section curves, foot bounds and intake-window bounds. The [Dell-linked laptop visualization asset](https://content.hmxmedia.com/precision-16-5680-laptop-AR/gltf/precision-16-5680-laptop-AR.glb) supplies those measurements; the [Dell base-cover illustration](https://dl.dell.com/content/guides/public/Html/precision-5680-owners-manual/images/GUID-69967AFA-A9EC-45D7-9EA1-D2536DE17041-low.jpg) confirms the strip/vent arrangement. [D1's evidence](../D1/reference-evidence.png) retains port and cable dimensions. The user's photograph establishes handedness and stays outside the repository.

With Python, CadQuery 2.8, NumPy, Pillow, matplotlib, trimesh and ffmpeg:

```sh
# Optional: regenerate the included contact data from a decompressed source mesh.
python extract_contacts.py /path/to/laptop.glb
python build.py
python validate.py
python alignment_check.py
python contact_study.py
python animate.py
```

The archive contains STEP, editable code, parameters, extracted contact data, validation, the report and still images. The 9.5-second animation is linked separately. D5 is current; previous revisions remain as history.

## Interactive assembly

[Open the D5 exploded viewer](https://thereprocase.github.io/dell-5560-wall-mount/desk-dock.html). Orbit, select parts, remove the adjustment cover, or play the lowering and 18 mm docking slide. Viewer meshes are exported directly from this CAD build with `export_viewer.py`. Exploded offsets are illustrative.

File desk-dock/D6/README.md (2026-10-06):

# D6 — the plenum is the stand

D6 makes the plenum wall the laptop backrest. The laptop's hinge-end case seats carry its weight; its lid leans 5° onto two thin replaceable liners attached directly to the plenum. The tall guide cheeks and underside rib frame are removed. The body remains split into two fan/plenum halves, with a profiled end seat integrated into each half.

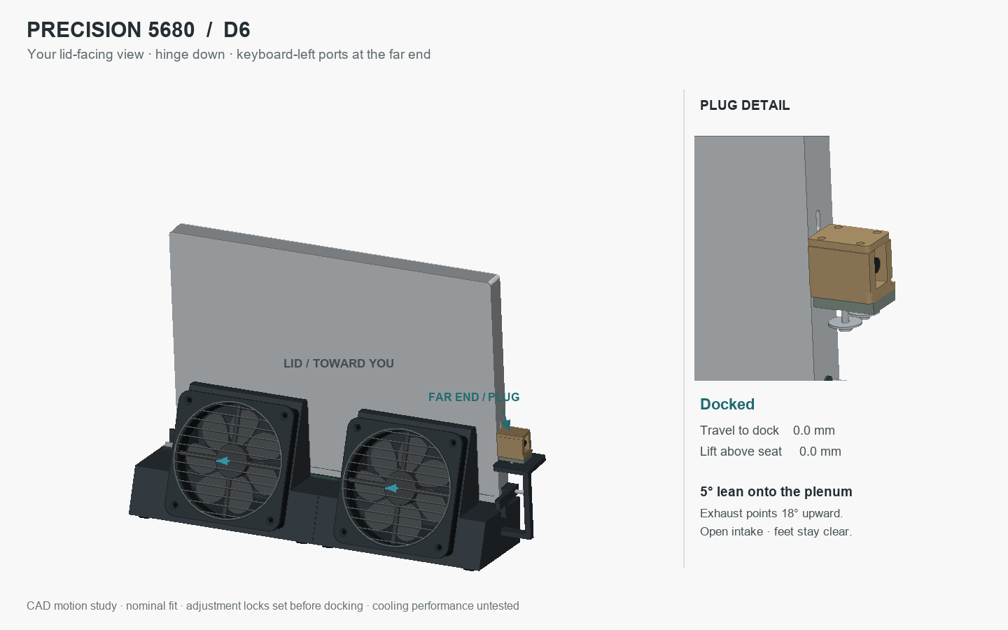
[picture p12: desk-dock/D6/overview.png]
D6 local review


[Interactive viewer](../../docs/desk-dock.html) · [CAD and source package](Precision_5680_D6_Review.zip) · [Port study](PORT_STUDY.md) · [Docking animation](docking-cycle.gif)

## Fewer mechanisms

The stacked height and lateral carriers, screw jack and separate adjustment hood are replaced by one exposed two-piece plug cassette on an integrated shelf. A 5 mm nominal shim stack sets height; a 1–10 mm stack provides −4/+5 mm height calibration. Two broad shelf slots allow nominal ±3 mm lateral and ±5 mm insertion adjustment. Two M3 locks with broad washers clamp the set position. Hardware is schematic and the required screw engagement must be detailed before printing.

The original Dell plug remains captured between the cassette and removable cap, with an axial clip. The separate chassis stop remains because it limits travel independently of the connector. Low lips at the bare case end margins assist placement without surrounding the laptop with upright rails. The raised near-end loading fence is removed so the loading end is open. Users lower onto the seats, then slide 18 mm to dock; passive correction from arbitrary angles is not claimed.

The two 120 × 15 mm fans discharge 18° above the desk. Their centers move 37 mm closer to the laptop than the first local D6, with a 58 mm fan-center datum. The [compact-depth study](AIRFLOW_STUDY.md) records the candidate sweep and CAD clearances. The revised duct rear wall also carries the lid contact. The underside has no rib frame over the intake window, and the rubber-foot keepout envelopes remain clear on the sampled docking path. D4's numerical duct-sizing claims are historical: this revised cavity has not been flow-tested or acoustically qualified.

## Ports corrected

The model preserves the Dell mesh's handedness. Both Thunderbolt ports are on the keyboard-left end, which appears on the right in the lid-facing view. The opposite USB-C / DisplayPort port is now represented separately. See [the focused study](PORT_STUDY.md) for the double-reflection cause, source hashes, measured coordinates and checks.

## Checks and remaining work

- `validation.json`: STEP round-trip validity, rigid-part intersections, 12 docking poses, expanded rubber-foot keepouts, three independent port probes and camera orientation.
- `alignment-validation.json`: direct lid-to-liner and liner-to-plenum contact, and an unobstructed intake screening slab.
- `geometry.json` and `flow-geometry.json`: component bounds and cavity volumes from this build.

The reference laptop is a simplified closed envelope with source-derived heel contacts and USB-C openings. Physical lid pressure, sliding friction, liner attachment, wall strength, tip stability, exact connector engagement, fan and split-body fastenings, print orientation, seal compression, airflow and noise still need qualification. The two shelf adjustments are nominal design ranges; only the nominal cassette position is included in the assembly collision screen. This remains a CAD development study, not a production print release. Use OrcaSlicer for subsequent print preparation.

## Local reproduction

Python 3.13 and the already-installed CadQuery 2.7.0, NumPy, trimesh, Pillow and matplotlib were used. No npm installation is needed. From the repository root:

```text
python desk-dock/D6/validate.py
python desk-dock/D6/alignment_check.py
python desk-dock/D6/export_viewer.py
python desk-dock/D6/airflow.py
python desk-dock/D6/contact_study.py
python desk-dock/D6/animate.py
```

The build reads the included source-derived JSON; it does not require downloading the Dell mesh. The fresh original asset and conversation/photo are retained separately under `D:\Code\Modeling\local-transfer`. Open the local viewer using `Open-Desk-Dock.ps1` at the repository root. D1–D5 remain intact as design history; the D5 viewer is archived as `docs/desk-dock-d5.html` and has a known mirrored port layout.

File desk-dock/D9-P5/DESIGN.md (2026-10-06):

# D9 P2 — no added metal hardware

Preserve the R2 contact profile and D9 P1 mouth geometry/fan pose. Replace every
added screw, nut and washer with printable mechanical connections. Purchased
fans still contain their normal motor and frame components; the plug mechanism
remains outside this revision.

The ten major parts now use 20 large printed pins and 20 flat locking keys:
eight fan pins, six internal plenum pins, four frame-end pins and two tie pins.
Sixteen keys have a 16-mm grip; four short keys have an 8-mm grip. The short
keys serve the two T-joint pins and two outboard lower fan sockets. Those two
fan sockets use side access through the cradle face; their neighboring inboard
lower fan keys insert from above, clear of the rear tie.
Floor-backed T joints transfer tie loads through shoulders; their pins prevent
uplift. The front tie/foot moved 20 mm forward from P1 to clear its accessible
printed retainers. Rear tie height remains 16 mm to clear the fans.

Pin sections: P2/P3 octagonal 8.2 mm across corners in 8.8 mm holes; P4 8.4 mm holes; from 19 September every pin is a round 7.9 mm shaft with a chord flat on the bed (0.5 mm diametral), after the octagons rattled and a round 8.2 mm trial would not enter the printed bores; the 7.9 mm pins were printed and confirmed to fit on 19 September.
Pin axes print parallel to the bed, on a longitudinal flat. Head notches identify
fan (1), frame (2), seam (3) and T-joint (4) pins. The keys print flat and bend in
their layer plane. Long keys use 1.2 mm leaves; short keys use 1 mm leaves and a
longer rounded root. Barbs must compress inward by approximately 0.4 mm each
to pass a nominal 5.4 mm slot. These are design dimensions, not calibrated fits
or measured insertion force/fatigue limits.

Fan sockets are external and blind. No fan fastener enters the air wall, so the
nominal enclosure audit needs no idealized bolt seals. (P5, 18 September: optional
M4 screw path added as bonus holes: 4.5-mm guard clearance, 3.5-mm blind pilots 6 mm
deep in the flange on the 105-mm pattern. Still blind, so the audit is unchanged.) Thin seam sealant remains
optional for physical airtightness, not structural attachment.

Manufacturing: broad shell exterior X faces down, cavities up; guard faces down;
male T ties broad top down, female ties broad base down. Hidden accessible support
is acceptable. No slicer search for orientations; Orca verifies the selected poses.
The fastener and fit-test plates use 100% infill; the six main plates retain five
walls, six top/bottom layers and 40% gyroid PETG.

The small fit-test plate includes both blind socket arrangements and guard spacing,
exact cropped T-joint ends, three production pins and their keys. Test insertion, positive
retention and deliberate removal before committing to the full shell print.
Physical laptop fit, loaded stability, clip durability, creep, airflow and noise
remain separate qualification steps.

# D9 P3 delta (17 September 2026)

Cradle contact from the R4-C bracket profile: R2 seat plus the 1-mm local
relief that seated on the printed V5 C coupon, lid rail moved 3.5 mm outward,
rail 6 mm thick, fence outer face +2 mm, base kept at 4 mm so all feet stay
coplanar. Cosmetic edge treatment on shells, guards and ties (3-mm concave and
1.5-mm convex fillets on print-Z profile corners, 0.8-mm chamfer on tie top
edges, bed edges untouched) with every mating zone protected; air volume of
each module unchanged to the mm3. Pins, keys and fit fixtures identical to P2.

# D9 P4 delta (18 September 2026)

Cradle source R5-C: R4-C plus the 64-mm underside rail (6 mm, 2.25-mm running
clearance, 4 x 2 mm lead-in) at the cradle ends. Fit corrections from the
printed P2 fit plate: pin bores 8.4 mm (BORE_R 4.2), key barbs 7.2 mm wide
(KEY_BARB 3.6, 1.8 mm total interference), T tongue 12.7 mm (TONGUE_H; P4's 12.1 withdrawn). Plate 00
regenerated. Edge treatment and everything else as P3.

Revised the same day: the underside rail is on the plug-end cradle (module 1) only. The far-end cradle keeps the R4-C profile because the rear rubber-foot strip (x 30..323, starting 18 mm further out when undocked) slides through that cradle's x range during docking and would catch on a wall there.

# D9 P5 delta (18 September 2026)

Lean 8 degrees. R7 frame on both cradle ends with the socket void subtracted from the fused cradle; drop-in seat peg and fence peg per end locked by one horizontal fan pin (0.15-mm cam offset, push-out holes); plenum front wall 24 -> 26.5 for the 8-degree lid; plate 08 pegs, plate 09 cradle-end trial. P4 fit corrections kept.

Support-reducing gussets (18 September): ribs or 34-degree wedges under every external socket boss (clipped 0.5 mm clear of the tie envelopes) and a 34-degree wedge on the pin-tip end of each seam tab (bore extended through it). Proven additive-only against the previous geometry; air volume follows the material, audits unchanged.

Splice ring (20 September): two fused arc pairs close the plenum splice. The assembled ring fills 99.9 % of the joint; the only voids are four intentional key clearances. Flanges alternate: back and fan lap M1; front and floor lap M2. The fan-seat plate receives an exact 1.2-mm-deep, 3.85-mm-long pocket and the fan arc replaces that material flush, providing 297.6 mm3 of positive M1 engagement without changing the fan face or airway. The builder now rejects any arc without a positive shell lap and records each engagement volume in the manifest. The upper ring carries the centre foot and cassette fork and needs localized support beneath its opposing flange and fork.

# Codex cleanup: bonded plenum-half joints (20 September 2026)

The three internal pin tabs, pin bores, key slots and support wedges in each
plenum are replaced by a continuous bonded shiplap around the existing shell
wall. The overlap is 20 mm long. Its complementary inner and outer tongues are
1.25 and 1.4 mm thick, with 0.20 mm between their mating faces for epoxy and
print variation. A 0.15 mm recessed land at the air surface receives the final
epoxy wipe without projecting into the nominal airway.

Three broad scallops register each joint: 8 mm radius and 1.5 mm axial depth,
alternating between the two lap ends so the dry joint cannot rock. The scallops
are clipped to the existing wall and never form posts inside the plenum.

This removes six pins, six keys and all six internal boss assemblies. The CAD
build at that revision contained 52 printed parts (46 after the large-shaft clamp
pivot), preserves both nominal air volumes, reports no
part or fan interference, and exports watertight single-component meshes. The
published P5 print kit has not yet been regenerated or superseded.

## Fan-guard cleanup

The two 154 x 132 x 4 mm printed grilles, their eight 7.5-mm standoffs, eight
40-mm printed pins, eight locking keys and eight external socket/gusset
assemblies are deleted. Each fan instead uses a standard 120-mm steel wire
finger guard and four M4 x 35 screws on the normal 105-mm pattern. The screws
pass through the guard and 25-mm fan frame into 3.5-mm diameter, 6-mm-deep
blind pilots in the existing 8-mm flange; they do not penetrate the air wall.

Together with the bonded plenum joints, this reduces the CAD assembly to 34
printed parts. The fan guards and eight screws are now ordinary purchased
hardware. The printed mass and flow obstruction of the old grille system are
removed, while each fan remains independently serviceable.

## Two-piece centre splice

The four functional ring arcs remain because their alternating M1/M2 flanges
capture both plenum halves, but they are no longer four loose puzzle pieces.
The back and front arcs are fused into one upper ring; the fan and floor arcs
are fused into one lower closure. Full-thickness tongue bridges replace the two
internal clip junctions. The remaining two opposite junctions retain the
existing half-lap and peg/socket registration.

The required centre support foot and fork are integral with the upper ring. A
removable narrow contact cassette fits that fork; the three temporary alignment
aids are deleted. Nominal centre-ring fill, plenum air volumes and laptop
clearance remain verified; the revised ring has not yet been physically printed
or Orca-verified.

## One-piece contact cassettes

At each cradle end, the seat peg and fence peg are now one H-shaped cassette.
The two deep channel legs retain the established R2/V5-C seat and the plug- or
far-end fence geometry; a 4-mm deck bridge joins them above the frame web. The
seat and fence are built 2 mm farther in the leaned-up direction, so the laptop
sits 2 mm higher against the tall lid rail. Width remains 16 mm and the existing
single transverse cam pin still locks the complete cassette.

The centre fork takes a third, narrow H cassette built with the same 2-mm lift,
4-mm bridge and short fence profile as the exit side. It is dressed to the M1
shell and upper splice ring so the ring-integral foot and fork remain intact.

The cleanup assembly before the accessory socket is 27 printed parts. The CAD build reports no rigid
interference with the frame, laptop or fans. Physical contact and sliding still
require a printed trial.

### Cassette bore correction and print poses

The first H-cassette implementation raised the contact by fusing each complete
finished peg with a copy translated 2 mm up the lean. That also duplicated each
peg's negative pin bore, producing two overlapping holes in both forks. The
bore cutter was additionally transformed at +8 degrees while the actual pin is
transformed at -8 degrees.

The corrected construction keeps each original contact body, adds translated
material only above the deck split, and explicitly rebuilds the two channel
feet as solid nominal foot volumes. Each end cassette then receives one 8.4 mm
self-supporting teardrop bore using exactly the same -8-degree transform as its
lock pin. The centre cassette has solid feet and no bore because its ring fork
does not use a lock pin.

## Universal plug-end accessory socket

A separate external receiver bonds to a shallow registered recess on the
plug-end cradle. Separating it preserves the cradle's proven broad-face print
orientation: the receiver prints on its closed mounting flange with its cavity
open upward. The joint uses a 1.2-mm perimeter tongue with 0.2-mm clearance for
epoxy and registration; no part of the receiver enters the plenum.

The receiver has a 30 x 40 mm internal section, 39 mm nominal engagement,
4-mm walls and 0.3-mm clearance per side around the cartridge. A broad blind
stop carries axial load. A custom printed 12-mm trapezoidal clamp bolt and
replaceable nut remove play but do not serve as the primary bearing surface.
The installed cartridge carries a polar plug-positioning linkage instead of a
Cartesian mounting frame. A large base pivot sets direction in the Y-Z plane,
a telescoping arm sets radius, and a smaller tip pivot independently aligns the
plug axis with the laptop port. Setup is self-jigging: loosen all three clamp
stages, dock the laptop and insert the plug, let the linkage settle without side
load, then tighten the base pivot, the paired arm-length screws and the tip
pivot. No coordinate measurement is required.

The tip pivot uses a hollow coarse-thread printed screw with a captive annular
head, a replaceable captive nut and two printable thrust washers. The radius
clamp uses two separated printable screws with captive heads to prevent yaw. A
short blind insert remains the fan-stand-only alternative.

Large-shaft face-clamp base pivot (20-21 September, PR #15 concept, PR #16 at
O75, then compacted): the 48-mm base clevis and its annular screw are replaced by
a stationary shoulder carrying a hollow 50-mm shaft. Outward from the dock: an
80-mm backing ring on the cradle plug-end face, a 3-mm skirt narrowing to a 70-mm,
10-mm-thick shoulder plate with twelve 50-degree internal ribs, the smooth journal,
the arm's 70-mm base disc with a 50.5-mm bore, the 10-mm cam spatula, a keyed
2.5-mm pressure washer riding in two journal keyways, and a knurled 72-mm nut on a
47 x 3 mm flat-crested trapezoidal thread (depth 1.15, crest 0.45, 0.35 radial /
0.15 axial clearance, 3 turns engaged, 4 mm spare thread outboard). The nut face
is 71.5 mm outboard of the shoulder-side cradle face. The size floor was set by
face-friction torque (20 N at about 80 mm needs 1.6 N.m; a hand-tight printed nut on
this annulus gives roughly 2.5-4.5 N.m), three turns of 3-mm thread, and finger room
on the nut. The nut lands 0.5 mm inboard of the thread start and the
journal is 3 mm longer than the disc, so the arm never rides thread crests and
the nut clamps before any runout. The angle is held by face friction over the
50-70-mm annulus; the thread only sets preload, and the large diameter does not
by itself remove backlash. The shoulder is bridged from the socket stem and its
skirt and ring are cut clear of the bonded receiver and of the rear-frame-L pin's
extraction path.

The shaft is offset 25 mm lidward of the socket centre. The port datum used by
D1-D7 (`rear_case_seat_z + port_from_rear_case`, `port_y`) puts port 1 only 59 mm
from the socket centre, inside the radius any 75-100-mm shoulder occupies, and the
previous polar arm (tip 108-148 mm from a pivot 59 mm from the port) could not
reach either port at all. From (y 70, z 70) port 1 is 76.4 mm and port 2 86.1 mm
away. The telescoping tip runs 103.5-125.5 mm; the plug carrier is cranked so its
14 x 13 mm window sits 34 mm lateral and 41 mm inboard of the tip. The carrier
block is built in the plug's own frame, rolled to the mean working arm angle plus
the lean (-41.1 degrees) so its faces are square to the plug's major and minor
axes and the rotor only trims roll; it reaches from the cam plate's face (x -49.9) to x -5
and carries an M8 x 3 printed pinch screw (16-mm shank, flat tip) through its 10-mm
wall into a captured scalloped nut. Its other walls are 12 mm on the thin (pivot-side)
face, 5 mm above the window and 18 mm below it: the 18-mm land under the window is
what the cam lobe's face bears on. With 5-mm walls the lobe only caught a 46-75 mm2
sliver of the back face; the land raises that to 375-404 mm2
(the exact figure per pose is `lobe_bearing_area_mm2` in `generated/port-reach.json`).
The block's four long edges (parallel to the plug, i.e. print Z) are rounded r 3.5, its
front face is chamfered 1.5 and the window mouth on that face is flared 1.5 mm at 45
degrees so the plug tip finds the tunnel; the back face is the bed face and the bearing
land, so it is left square. The plug is clamped on the FLATS of its overmold
(USB-IF caps it at 12.35 x 6.5 mm, the 12.5 x 6.5 envelope parameters.json already
carries) between the thin wall and a loose flat 7-mm bearing shim, over the 12.5 mm
of overmold behind the port face, so it cannot roll in the carrier; the screw tip
seats in a round recess on the shim's back. Behind the clamp zone the window is
relieved to r 4.7 so boots up to 9 mm pass. Clamped, the overmold sits 0.25 mm off
the thin wall, so that clamped axis, not the window centre, is the reach target; and
because the rotor trim that squares the window to the port rotates the window about
the tip, the trim is part of the reach solve rather than a free adjustment. The builder solves the arm angle and reach for both
ports, swings the arm there, passes a plug-and-boot envelope through the port and
fails the build on any contact with the dock, laptop or desk.

Stiffness target: no more than 0.5 degrees of plug-axis tilt under 20 N along the
plug axis. The docking push is taken off the arm entirely by a separate cam-lobe
"spatula" plate (10 mm) that rides the same journal outboard of the arm disc and is
pinched by the same nut. Its lobe is a leaf covering about 50 degrees of arc: a
radial near edge 3 degrees along the spiral, a log spiral r = 58 e^(1.2 theta) to
24 degrees (r 96) and a spline tip and back edge. It is rotated until the spiral
runs up to the plug boot; the carrier's back face then bears face to face on the
lobe, so the laptop pushing the plug loads a clamped plate rather than a
cantilever, the edge stops at the boot so the plug and cable still pass, and the
lobe running past the carrier is what keeps higher arm positions viable. The builder solves the cam rotation for each port
and reach, checks the lobe against the sleeve, rotor and a plug-boot-cable
envelope, and records a first-order beam estimate for both directions (docking push
through the lobe and shoulder; withdrawal pull through the 20-mm tongue, 25.6-mm
sleeve and shoulder). Those
numbers are estimates only and exclude the socket cartridge's 0.3-mm-per-side
clearance, clamp-face slip and layer anisotropy; the acceptance test is a dial
indicator on the plug boot at 20 N.

Fan-seat continuity correction: the wall-derived 20-mm plenum shiplap does not
describe the wider fan flange. Applying it to the complete housing had left two
slots across each fan seat at the top and bottom of the 120-mm footprint. Those
missing flange volumes are now restored and divided at the nominal module split
between the two halves. A dedicated thin-face audit requires zero missing seat
volume while preserving the circular opening and four blind screw pilots.

Laptop insertion depth remains independent of connector alignment. The fixed
receiver carries the restored printed M10 chassis-stop screw with +/-4 mm
travel and a replaceable flexible tip. Set it so the laptop closes against the
soft stop immediately before the USB-C plug reaches full insertion; docking
thrust must not bottom out through the plug or either polar-link pivot.

The broad-side poses remain preferred for the two shells and three cassettes.
The laptop-side splice ring is flipped to put its larger flange area on the bed:
the mesh audit reduces non-bed downward-facing area from 2,523 to 1,870 mm2 and
increases bed contact from 65 to 718 mm2. Its alternating M1/M2 flanges lie on
opposite faces, so no flat orientation can place both on the bed; support remains
required below the smaller opposite-side flange. A vertical pose reduces that
support but leaves only about 89 mm2 of bed contact and puts the foot/fork load
across weaker layers, so it is rejected. The fan-side ring remains flat in its
existing pose. Recheck these poses and support interfaces in OrcaSlicer before
printing.

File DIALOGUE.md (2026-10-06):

# Project dialogue: user prompts and design responses

These are the project prompts available in the working conversation, in order. Quoted text preserves the user's wording. Response notes summarize work and decisions; they are not verbatim assistant messages or a complete chat export. The README groups related decisions by engineering topic rather than pretending that each final feature appeared in the first iteration.

## 1. Initial brief

> Make a wall mount laptop holder to hold a Dell Precision 5560 in the closed position. I use it as a web server. The wall mount holder should have four fastener holes. I'll use plastic toggle bolts so they don't need to be at any particular spacing, but four for strength to hold it to the wall. It should have vent space between the laptop and the wall, and it should have room to mount a couple of 120 millimeter fans below the laptop to direct airflow up and past the laptop's cooling vents, and it should be easy to pull the laptop up and out. The hinge will go down— no, wait. The hinge will go up so that the hot air escapes up and the fans can go on the bottom, and it should be easy to pick the laptop out to use it temporarily if I need direct keyboard access to the server, but otherwise it should just stay out of the way and be nice and cool. And I need this as a ParaSolid or a STEP file.

**Response:** establish a hinge-up, lift-out cradle, wall gap, two lower fans and four wall fasteners. Deliver exact solid geometry as STEP.

## 2. Retention, finish and installation

> That looks amazing! Can you give it some aesthetic polish and make the tines on the front a little bit taller so the laptop is held more securely. Also give it a quick strength check and make sure that all of the fasteners are easy to install and oriented perpendicular to the wall

**Response:** retain taller front tines and polished edge treatment; check load paths and room-side tool access. The final wall fasteners remain perpendicular to the wall.

## 3. Pressure rather than incidental crossflow

> from a fluid mechanics perspective, should we tilt the laptop towards the wall to create a restriction (or make an additional part - a back rail) for the purpose of ensuring high pressure at the laptop's intake vent, and a high velocity exit above, so hot air is carried far away? This ensures that the 120mm fans create airflow THROUGH the laptop instead of accidentally creating a high velocity low pressure region outboard of the laptop's intake.

**Response:** treat the rear gap as a pressure-fed plenum and the upper rail as a downstream restriction. Actual through-laptop flow and hot-plume distance require models or measurements beyond the later 2D screen.

## 4. Sketch and vent alignment

> something like this. doesn't have to seal, just has to be high pressure at vent high velocity beyond. check vent layout dims to align the restriction / outlet properly

**Response:** interpret the attached annotated sketch as a separate rail above the intake band. The final dimensions use scaled Dell imagery, with uncertainty recorded rather than hidden.

## 5. FDM direction

> Lovely. now optimize each part for FDM 3d printing while maintaining the overall fit-up. Consider overhang angles, bridges, etc. Make this easy breezy for a P1S with ASA. I would like to print the brackets on their side for strength, and not on their back. Not that I could print these on their back anyway. Maintain the aesthetic polish as you go.

**Response:** build print orientations into the part geometry. Keep the cradles side-down and revise roofs, duct transitions and part splits around that constraint.

## 6. Choose useful analysis

> Let's talk through a few things real quick. Fluid dynamics? Airflow sim? Topological optimization? Generative structures? What would help and what can you do well, quickly?

**Response:** prioritize interpretable load paths, geometric print checks and flow comparisons. Later work includes actual OpenFOAM runs; no topology or generative solver is claimed.

## 7. Recover the checkpoint and retain bridges

> Also, grab the tail end of yesterday's transcript and the scratch workspace and wrap up this checkpoint?
>
> "Lovely. now optimize each part for FDM 3d printing while maintaining the overall fit-up. Consider overhang angles, bridges, etc. Make this easy breezy for a P1S with ASA. I would like to print the brackets on their side for strength, and not on their back. Not that I could print these on their back anyway. Maintain the aesthetic polish as you go."
>
> Also bridges are just fine, they're usually printable. Unsupported overhangs are bad. I guess in a duct the surface might be rough. Roll in the good ideas from the above and get me the efficient and printable package?

**Response:** preserve short bridges, distinguish them from unsupported ledges, and package oriented models with print and verification notes.

## 8. Reduce material

> I feel like we could get really creative and save a ton of plastic here.

**Response:** explore hollow sections, skins, framed trays and pocketed caps while keeping the original interfaces and side-print direction.

## 9. Proceed

> yes, do it.

**Response:** produce the lightweight Revision E. Its solid CAD volume is 35.7% below D; the later Revision F retains a 35.0% reduction after adding containment and revised assembly features.

## 10. Integrated Revision F

> Can we also make it tool free / ca glue assembly, except for the four wall bolts? And shroud the cheeks to keep air contained? And have the fans angle down so they're blowing at a 45 to the gap instead of straight in? And do some cfd to design the plenum and slot? And download and scale images and cross sections of the machine to estimate its profile geometry?

**Response:** implement keyed CA joints, removable split pins, cheek shrouds and 45° fan modules. Download and scale manufacturer images; reconstruct an explicitly estimated profile. Run eight representative 2D OpenFOAM cases and retain their raw evidence and limitations.

## 11. Public report

> write up a report and push this as public to thereprocase github with good imgaes and a process readme?

**Response:** curate the current files, write an illustrated engineering report and process narrative, and prepare the public repository. Keep previous checkpoints out of the main download and preserve the numerical evidence.

## 12. Fit allowances

> what tolerances did you assume for slide to fit parts?

**Response:** inspect the source geometry. Record 0.30 mm horizontal dovetail allowance per side, 0.30 mm crown and 0.20 mm root clearance; distinguish these from normal flank clearance. Document fixed-key and printed-pin fits separately. No global ASA shrink correction is assumed.

## 13. Repository destination

> https://github.com/thereprocase/dell-5560-wall-mount

**Response:** use the supplied public repository and retain its existing MIT license.

## 14. Explain the engineering process

> Enumerate your workflow and thinking, list my prompts as part of the dialogue, what you did at each stage, and what software and packages you used and how you approached the problem solving. Make the readme a thrilling read for an experienced mechanical engineer (not with thrilling adjectives and fluffy puffy bullshit, just by being well written and concise).

**Response:** structure the README around the decisions, tools and evidence. Include the pressure/flow tradeoff, the intake-window discovery, the small effect of the curved turn, the distinction between CAD clearance and printer capability, and the physical tests that remain.

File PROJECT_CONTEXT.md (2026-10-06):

# Project context and maintainer handoff

This is the durable engineering context for the Precision 5680 desk dock as
of 2026-09-08. **D8 is the current design on main.** Read
[the D8 change record](desk-dock/D8/README.md) and
[current checks](desk-dock/D8/CURRENT_STATUS.md) first. The historical sections below
preserve the D7 baseline and should not override D8's live Y/Z slides, keyed
removable module, independent X stop, shell feet, light covers or fan clips.
The public showcase and viewer now use D8; the archived D7 viewer and old download retain D7. Its home is
[`thereprocase/5680-dock`](https://github.com/thereprocase/5680-dock), with the
[project site](https://thereprocase.github.io/5680-dock/) and
[interactive model](https://thereprocase.github.io/5680-dock/desk-dock.html).
Earlier repository history and studies are retained so decisions and source
geometry can be traced. This handoff records project decisions and evidence;
it is not a transcript or a substitute for current CAD and manifests.

## Intent and everyday use

Make an elegant, compact stand for a closed Precision 5680 at the edge of a
desk. The hinge points down, the lid faces the user and fans, and the underside
intake remains exposed. The plenum serves as the laptop support, avoiding
separate tall guides that duplicate its function. Two shaped end seats carry
the laptop's weight; soft plenum contacts take its lean. Seals guide airflow
and are not structural bearings.

Lower the laptop onto the seats at the withdrawal offset, then slide it
sideways into the captured original host-cable plug. Withdraw sideways before
lifting. The modeled withdrawal is 18 mm. The viewer's 135 mm lift is a
presentation distance, not a required stroke or an automatic sequencing
mechanism. This is a mechanical cable holder and extraction stand; the dock
electronics remain external.

The accepted direction is fewer useful parts, open access, smooth loading
and compact desk depth. A troublesome loading-end tab was removed. Two small
thrust tabs became one **continuous low lip**, split only at the plenum seam;
the requested change was continuity, not taller retention walls. The 12 mm
lip stays below the modeled rubber-foot keepout. Do not restore separate lid
guides or a tall loading-end obstacle without addressing why they were removed.

## Revision history and superseded assumptions

| Stage | Main contribution | How to use it now |
|---|---|---|
| Earlier 5560 wall mount | Wall-mount geometry, materials, print packages and CFD studies | Historical project branch; not a 5680 desk-dock qualification |
| D1 | Dell source extraction, hinge-down concept, adjustable original-plug cassette and separate stop; flat slim fans | Source provenance and initial concept; wrong-end orientation and incomplete assembly details were superseded |
| D2 | Nearly upright fans and lower/slide/withdraw/lift animation | Historical motion study; orientation and fan discharge changed later |
| D3 | Attempt to match the photographed far docking end | Its stated correction did not resolve the later-discovered CAD/raster reflection problem |
| D4 | Upward 15° discharge, rounded mouths, curved passages and conditional airflow sizing | Useful airflow reasoning; larger, older geometry and fabricated guard concept |
| D5 | Profiled guides, 2° laptop lean, open ribs and expanded rubber-foot keepouts | Contact-source evidence; guides, lean, fan geometry and mirrored CAD were superseded |
| D6 | Independent port study; removal of reflection; 5° lean, direct plenum bearing, 18° discharge and compact plenum | Orientation/contact and airflow baseline inherited by D7 |
| D7 | Recessed fan pockets, slide-in printed grilles, service covers, printed hardware, continuous low lip, reinforced/resettable cassette and cable passages; final 25 mm fans | Preserved baseline; its exports/status do not qualify D8 |
| D8 | Removable live Y/Z module and independent X stop; direct shell feet, thin ribbed covers, separate fan clips and explicit print poses | Current design on main; use D8 manifests and status |

Older reports may call their revision “current,” use ASA, specify 15 mm fans,
or claim an orientation correction that predates D6's independent audit.
Keep those statements attached to their original revisions. The original
root overview is at [docs/history/5560-README.md](docs/history/5560-README.md).
Root-level wall-mount scripts and reports are retained history; start current
work in [desk-dock/D8](desk-dock/D8/).

## Handedness and coordinate contract

**Both Thunderbolt 4 ports are on the keyboard-left edge.** With the closed
laptop hinge-down and viewed from the lid side, this is image-right, at the
far plug station. The opposite keyboard-right USB-C port supports USB 3.2
Gen 2 / DisplayPort. Do not label it Thunderbolt.

D5 reflected the CAD about the laptop midpoint. A reversed camera basis in
its still-image renderer concealed the reflection; a browser camera exposed
it. D6 removed the mirror and checked port voids, solid opposite edges, plug
side and projection separately. A screenshot that looks right is insufficient
evidence of a correctly handed solid.

In the unleaned construction frame:

- X=0 is keyboard-left and the plug station; X increases toward keyboard-right.
- +Y is toward the lid, user and fans; -Y is toward the underside intake.
- +Z is upward. The rear-case seat datum is Z=54 mm.
- The plug enters along +X. The laptop docks along -X and withdraws +18 mm.
- Apply the 5° rigid lean about X after construction. Use proper rigid
  transforms; no reflection is permitted.

The selected rear Thunderbolt center is 65.979 mm from the rear-case datum,
at thickness coordinate +2.231 mm; the second is 82.192 mm from that datum,
with its own +1.915 mm thickness coordinate. Nominal laptop dimensions are
353.68 × 240.33 × 22.17 mm. These come from Dell-linked visualization geometry,
not toleranced factory connector drawings. Physical calibration is necessary.
Read [D6 PORT_STUDY](desk-dock/D6/PORT_STUDY.md) and its extraction record
before changing reference transforms.

## D7 baseline: geometry and service decisions

The laptop leans **5°**. Fans discharge **18° upward in the desk/world frame**;
their planes are 18° from vertical. The fan angle is independently posed,
not 18° added to the laptop lean. The compactness request suggested a few
extra degrees of fan kick; the existing 15° baseline plus the selected
additional 3° produced the retained 18° world angle.

The compact plenum keeps a fan pose anchor at Y=58, Z=72 mm. Final fans are
**120 × 120 × 25 mm**. Their thicker frames grow outward while keeping the
suction face at the prior location, preserving the inlet passage. Historical
`fan_center_y/z` fields are pose anchors; with 25 mm fans they are not the
actual frame centers. Read `fan_depth_datum` in the parameters. Do not simply
center a thicker fan on the old 15 mm frame center.

D6 selected this depth using an assumed 30 CFM total flow, a chosen inlet
allowance and sampled cavity rays. It did not find a measured airflow optimum.
Its slim-fan example does not specify the final 25 mm fan model. Check the
actual fan, vibration pads, connector and lead exit. See
[AIRFLOW_STUDY](desk-dock/D6/AIRFLOW_STUDY.md) and regenerated D7 airflow
records for the geometry and calculation scope.

Fans lower into open-top pockets. Printed grilles slide in rails and close
the top; small friction lands replace loose fan-retaining screws. Remove
the laptop before service and allow the documented inclined removal travel.
Bottom panels expose the ducts and close around fan wires laid into open
edge saddles. Shell tie lugs retain fan wiring when covers are off. Use
accessible loops or disconnects; do not attach the moving USB lead to fixed
fan-wire tie points. Cable ties are service accessories, not precision
locators or substitutes for the printed body fasteners.

## D7 baseline: printed hardware and plug calibration

The user selected **Bambu Lab P1S, PETG and a 0.4 mm nozzle**, with hand
assembly and printable screws, nuts and pins. Small metal fasteners and the
earlier metal front-clip approach were superseded. Examples include 8 mm
coarse clamp threads, 10 mm stop/preload threads, a 10 mm hinge axle and a
6.5 mm cap pin. These follow the direction to avoid tiny printed hardware:
pins at least 6 mm and threads at least 8 mm.

The thread pairs have actual matched custom helical profiles; their nominal
diameters are not claims of ISO metric interchangeability. Check coupons
and actual horizontal bores with the chosen process. Fans, the original
cable, electronics and compliant contacts remain external components;
this is not an all-PETG electronic dock.

The cassette uses a broad keyed replaceable shim, one printed lock and a
lower keeper. Height, lateral position and insertion depth are encoded in
the fitted parts, rather than left sliding on friction-locked slots. Ranges
are Z=-4..+5, Y=-3..+3 and X=-5..+5 mm. Regenerate affected parts for the chosen
calibration; these ranges do not reach the other Thunderbolt port. A lift-off
cap and transverse pin retain the overmold. Nominal squeeze is a fit assumption;
extraction retention requires a pull test. The USB shell must not act as a
guide, bearing or chassis stop. See
[CASSETTE_ASSEMBLY](desk-dock/D7/CASSETTE_ASSEMBLY.md).

## D7 baseline: alignment and resettable breakaway

Targets are **no more than 0.20 mm complete-holder axial movement at 20 N**
and a **50 N-class resettable release for a misaligned, unmated docking
strike**. These are acceptance targets. The independent fixed chassis stop
already limits seated travel; the breakaway is not a 50 N protection rating
for a mated USB-C port.

A printed face-cam hinge turns about Y, with its pivot 27.15 mm above and
27.15 mm behind the nominal metal tip. Three cam teeth and a shallow conical
pilot locate the ready position. The clearance-fit axle guides motion; it
is not the sole precision seat. Two replaceable PETG leaves preload the cam
through a hand nut. A shoulder limits nominal preload while allowing extra
cam travel. The spring moved rearward to clear the final 25 mm fan rails;
read its current offset from parameters, not old images.

Each nominal leaf is 30 × 24 × 3 mm, initial deflection is 1.2 mm and extra
cam lift is 0.8 mm. The ideal combined rate is 57.6 N/mm at assumed E=1.2 GPa.
The energy-shaped ramp aims for 1.3575 N m, reaches full lift near 3.112°,
then permits manual folding to the 45° stop. The tip retreats outward and
down. Return it by hand to seat and reset. Print the spring's **unloaded
export**, not its deflected assembly appearance.

Friction, conical contact, finite cam geometry, spring-frame compliance,
anisotropy, temperature, creep and cable reaction affect release. The nominal
50 N interpretation applies separately to axial or downward force at the tip.
An equal diagonal load gives the same moment at roughly 35 N resultant;
lateral Y loading does not trigger this hinge. Adjustment changes lever arms.
Static release is not an impact-force ceiling, and partially engaged contact
needs separate assessment.

The member calculation and local carrier screen are distinct. At assumed
E=0.8 GPa and 20 N, the brace's worst calculated axial contribution is about
0.07945 mm. The cable notch raises the local carrier torsion proxy to about
0.049-0.055 mm nominal and 0.082-0.090 mm at the adverse low/lateral setting.
These do not solve every joint or prove the complete 0.20 mm target. Do not
reuse the smaller pre-notch estimate or treat removed volume fraction as a
stiffness result. The [holder study](desk-dock/D7/arm-study/HOLDER_AND_BREAKAWAY.md)
and independent calculations retain the derivations and boundaries.

## D7 baseline: rear USB cable and animation

The rear lead exits along -X through an **8.5 mm open-top rounded trough**.
Its mouth flares to 12.5 mm over the outer 2 mm of the carrier wall. Removing
the cap and pin permits lay-in without passing either connector through a
closed hole. The source stub is 6.5 mm diameter; this does not establish the
actual cable diameter farther along the lead.

Reserve loose cable outside the carrier. The illustrative clearance path has
30 mm of straight lead beyond the wall, an **assumed R30** downward bend and
a short tail. Actual minimum bend radius and needed slack are unmeasured.
The rear outlet rises about 25.63 mm during a 45° fold even while the tip
drops, so a tight downward elbow or immediate fixed clamp would oppose the
release. The actual far cable endpoint stays fixed and the loop must deform.
A transported rigid keepout is a geometric screen, not a flexible-cable or
tension model. See the
[independent route audit](desk-dock/D7/arm-study/independent_cable_route.md).

The viewer moves carrier parts with a rigid pivot rotation plus axial cam
lift. The axle/nut translate; spring leaves deform while their frame stays
fixed. Reset reverses the path. Exploded offsets are explanatory, and the
slow fold is kinematic; neither simulates force nor establishes a physical
assembly/removal sequence. Describe endpoint and intermediate checks according
to the current validation report, not as physical qualification.

## Current evidence, reproduction and publication

Start with the [D8 assembly guide](desk-dock/D8/README.md),
[print design](desk-dock/D8/PRINT_DESIGN.md) and
[completed review status](desk-dock/D8/CURRENT_STATUS.md).
D8's `parameters.json`, `geometry.json`, `print-manifest.json`,
`generation-provenance.json` and `validation.json` describe the current files.
The generation record ties unchanged source inputs to exact exported outputs;
individual development experiments retain their own hashes and stated scope.

Regenerate with `desk-dock/D8/regenerate.py` and an explicit scratch cache,
then run `print_check.py`, `validate.py` and `render_review.py` as documented
in the D8 guide. Use the declared CadQuery environment. Regeneration writes
an uncompressed STEP locally; refresh its tracked ZIP and archive hashes when
republishing. Keep CAD, meshes, manifests, checks and images from the same build.

The current downloads are the complete
[D8 STEP archive](desk-dock/D8/Precision_5680_D8_STEP.zip) and
[individual manufacturing STLs](desk-dock/D8/print/).
All 43 meshes pass preflight. The generic offline material/path screen covers
42 PETG parts and estimates 1.659 kg including normal supports and brims;
the flexible stop is separate. This is not approved P1S G-code or physical
qualification. Actual printing still requires the selected P1S profile and
inspection of supports, bridges and fit surfaces.

Keep GitHub checkpoints current and make the latest design, downloads and
remaining engineering work prominent in the root README. Preserve earlier
revisions as history. The public showcase and interactive viewer now use D8.
The [archived D7 viewer](docs/desk-dock-d7.html) and
[D7 archive](docs/downloads/Precision_5680_D7_Review.zip) retain their original geometry and evidence.
Run `desk-dock/D8/package.py` after updating review files to refresh the separate
Pages print/source and STEP downloads.

## Research worth retaining

The [material/load audit](desk-dock/D7/arm-study/material-load-sources.md)
was checked on 2026-09-08. It distinguishes standards, measurements and
assumptions; preserve those distinctions when updating it.

- [Dell 5680 left view](https://www.dell.com/support/manuals/en-us/precision-16-5680-laptop/precision-5680-owners-manual/left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)
  and [right view](https://www.dell.com/support/manuals/en-us/precision-16-5680-laptop/precision-5680-owners-manual/right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)
  establish port types. The [Dell-linked visualization asset](https://content.hmxmedia.com/precision-16-5680-laptop-AR/gltf/precision-16-5680-laptop-AR.glb)
  supplies geometric evidence, with extraction provenance retained in D1/D6.
- [USB-IF Type-C Release 2.5](https://www.usb.org/document-library/usb-type-cr-cable-and-connector-specification-release-25)
  informs ordinary mating-force scenarios. Its cited force clauses exclude
  docking; cable pull-out and connector extraction are different tests.
- [Molex 218847 measured test report](https://www.molex.com/content/dam/molex/molex-dot-com/products/automated/en-us/productspecificationpdf/218/218847/2188470001TS-000.pdf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)
  gives specimen results for one connector family, not Dell force data. No
  public Dell 5680 force-displacement curve was located in the recorded search.
- [Dell connector handling guidance](https://www.dell.com/support/kbdoc/en-us/000198334/how-to-correctly-plug-and-unplug-the-usb-type-c-connector-on-a-dell-dock)
  supports straight aligned insertion/removal and avoiding twist or taut leads.
- [Prusament printed PETG data](https://prusament.com/wp-content/uploads/2022/10/PETG_Prusament_TDS_2021_10_EN.pdf),
  [Polymaker printed PETG data](https://polymaker.com/wp-content/uploads/lana-downloads/TDS_Polymaker_PETG_V2.0_2025-11-17.pdf)
  and [Redutko et al.'s original experiment](https://doi.org/10.24425/amm.2022.137763)
  show material variability. Static tensile, flexural and dynamic storage
  moduli differ. E=0.8/1.2/1.8 GPa are sensitivity inputs, not a measured
  temperature curve for this spool; HDT/Tg are not service ratings.
- [Fantech installation guidance](https://www.fantech.com.au/Content.aspx?ContentID=L5&category=dos-and-donts)
  explains inlet system effects. It does not establish a safe minimum gap,
  operating flow or acoustic result for this compact enclosure.

## Next physical work for D8

1. **Measure and fit.** Confirm the real laptop, chosen port, cable overmold,
   fan thickness/pads, lead exit and cable diameter. Print thread, pin,
   cam/pilot, grille and panel samples before large bodies.
2. **Complete slicing.** Use OrcaSlicer, the project default, with the selected
   P1S/PETG/0.4 mm setup. Review deposited paths, support access, bearing faces,
   thread roots, spring orientation and brim/excluded-bed clearance. The
   generic Cura review is not an approved P1S job; inspect the actual paths.
3. **Test the detached holder.** Use a dummy plug and measured load to assess
   complete movement relative to the laptop-bearing datum at 20 N, directional
   release, peak force, repeatable reseating, overmold retention and warm dwell.
   Calibrate within the nut's shoulder limit; do not overtighten a relaxed
   spring to recover force. Keep the laptop out of these load tests.
4. **Calibrate docking.** With the laptop supported, set the fitted cassette
   using the live Y/Z slides and independent X stop. Check straight engagement/withdrawal, feet/intake
   clearance, cable slack and manual removal without a slam.
5. **Check the stand in use.** Measure sliding and tip stability under actual
   laptop/cable loads, service access, fastener/grille retention, seals and
   PETG creep. Repeat with the actual cable through the full fold.
6. **Measure cooling and sound.** At fixed workload and fan settings, compare
   temperatures, power, branch flow/pressure and sound with external fans off
   and running. Test leakage and fans-off restriction. Establish the fan/system
   operating point before claiming benefit.

No successful slice, printer job, physical force/impact test or measured
thermal/acoustic qualification is recorded for D7. Keep that status explicit
until corresponding evidence is added.

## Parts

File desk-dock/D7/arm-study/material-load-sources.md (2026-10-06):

# Plug-arm load and printed PETG inputs

Research checked 2026-09-08. Sources below are USB-IF, connector/filament
manufacturers, and an original experimental paper. The actual PETG brand,
printing quality, arm temperature and Dell connector forces remain unmeasured.

## Calculation inputs to use now

- Treat **20 N** as a provisional axial design scenario informed by ordinary
  USB-C mating tests. It is not a guaranteed force limit for this mechanical
  dock. Friction, misalignment, cable reaction and a user's off-axis push can add
  loads absent from a bare connector test.
- Add **40 N** as a chosen overload sensitivity, not a measured Dell force or
  a standard mating requirement. In a linear model it doubles the 20 N stress
  and deflection. Check the printed arm separately from the laptop: do not
  apply a 40 N proof load through the laptop port.
- Use **E = 0.8, 1.2, 1.5 and 1.8 GPa** as explicitly assumed stiffness cases.
  The 1.5 GPa case is consistent with one manufacturer's printed PETG tensile
  data. The lower cases are engineering sensitivity values, not measured warm
  moduli for the user's spool. Some printed PETG formulations exceed 2 GPa.
- The sweep is not a validated temperature model or confidence interval. Do not
  label 0.8 GPa as the modulus at a particular temperature. The linear-elastic
  calculation also does not predict creep, joint slip, rail clearance or local
  indentation. At otherwise identical conditions its predicted deflection
  changes by 2.25 times between E = 1.8 and 0.8 GPa.
- Identify whether the analyzed section is a solid wall, explicitly hollow CAD
  section, or partially filled printed volume. A solid-coupon material modulus
  does not make a 20%-infill gross section solid. Use actual walls/voids for the
  bending section and avoid counting sparse infill as fully dense PETG.

## USB-C force evidence

### Current literal standard: USB-IF Release 2.5

[USB-IF official Release 2.5 page](https://www.usb.org/document-library/usb-type-cr-cable-and-connector-specification-release-25)
links the [March 2026 release archive](https://www.usb.org/sites/default/files/USB%20Type-C%202.5%20Release%20202603.zip),
posted 2026-04-08. The clean 442-page PDF was downloaded directly and read;
page 136, sections 3.8.1.1-3.8.1.3, states these **requirements, not measurements**:

| Quantity | Value and conditions |
|---|---|
| Initial insertion | 5-20 N; EIA 364-13; maximum 12.5 mm/min |
| Initial extraction | 8-20 N after five conditioning cycles, measured on sixth extraction |
| Later early extraction | On extraction 32, within 33% of initial result and still 8-20 N |
| Extraction after durability | 6-20 N after 10,000 cycles; maximum 12.5 mm/min |
| Durability cycling | At least 10,000 cycles; 500 +/- 50 cycles/hour |

Both force clauses exclude docking applications. They inform this prototype's
load cases without guaranteeing its total operating force. Section 3.8.1.5's
40 N for one minute concerns **cable pull-out/strain relief with the plug
clamped**, not connector extraction or permissible load on a Dell port.

Archive retrieval initially returned 403, then succeeded with a normal browser
User-Agent and public USB-IF referer. No authentication was needed. Local
reference PDF: `D:/codex-work/scratch/usb-c-load-research/USB Type-C Spec R2.5 - March 2026.pdf`.
SHA-256: `6636cd61387a2f78b0fa96c8ea86ccc0f39ec59f98821cdb57b206d31445a328`.

The independently accessible [USB-IF Compliance Document Rev. 2.1b, June 2021](https://www.usb.org/sites/default/files/USB%20Type-C_Compliance%20Document_Rev_2_1b_June_2021.pdf),
page 14 Table 3-2 and pages 34-35 Table 4-7, gives the same force ranges and
measurement speed. It describes the docking exception as direct docking
without a cable. This is the compliance document currently linked in the USB-IF
library; its 2025 listing date does not change its printed June 2021 revision.

### Actual measured USB-C plug test: Molex 2188470001

[Molex test summary revision A, 2022-12-28](https://www.molex.com/content/dam/molex/molex-dot-com/products/automated/en-us/productspecificationpdf/218/218847/2188470001TS-000.pdf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),
sheet 9, Group E, reports **measured results for five specimens**. The methods
on sheet 4 specify 12.5 mm/min. Sheet 13 identifies a HongHaiKeJi MC-1220S force
tester; numerical room temperature/humidity are not supplied.

| Measured force, N | Minimum | Average | Maximum |
|---|---:|---:|---:|
| Insertion after preconditioning | 11.39 | 11.95 | 12.64 |
| Early extraction | 14.93 | 15.69 | 16.32 |
| Extraction after 25 additional cycles | 14.57 | 15.31 | 16.02 |
| Extraction after durability to 10,000 cycles | 11.05 | 11.46 | 12.42 |

This is a 24-pin vertical SMT **plug**, not an identified Dell cable. It supplies
summary statistics, not individual sample traces or force-displacement curves.
Those measured columns must not be confused with the adjacent specification
column (5-20 N / 8-20 N / 6-20 N).

### Actual measured USB-C receptacle test: Molex 204711 family

[Molex 2047110001-TS revision B, 2024-12-24](https://www.molex.com/content/dam/molex/molex-dot-com/products/automated/en-us/testsummarypdf/204/204711/2047110001-TS-000.pdf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),
sheet 7 Group E, supplies another five-specimen result set:

| Measured extraction force, N | Minimum | Average | Maximum |
|---|---:|---:|---:|
| Following initial conditioning | 12.20 | 13.78 | 15.70 |
| Following 25-cycle stage | 13.00 | 14.32 | 16.10 |
| Following stage labeled 2,500 cycles | 7.90 | 8.58 | 10.20 |
| Following stage labeled 5,000 cycles | 6.30 | 7.34 | 8.80 |
| Following stage labeled 7,500 cycles | 6.70 | 7.44 | 8.80 |

This is a receptacle report, with EIA-364 qualification and a Japan Instrument
Max-1KN-H load tester listed. Its summary does not give a numerical force-test
speed/ambient or a mating-plug identity. The final stage is printed as 1,000
cycles after 7,500; the inconsistent label is not silently corrected or used
here. Its insertion test appears in the sequence but no insertion results are
shown in the performance table. These are min/mean/max results, not raw curves.

### Dell evidence and limits of the search

[Dell's connector handling guidance](https://www.dell.com/support/kbdoc/en-us/000198334/how-to-correctly-plug-and-unplug-the-usb-type-c-connector-on-a-dell-dock)
requires straight, aligned insertion/removal and avoiding twist, side pressure
and a taut cable. It provides no force measurements. No public Dell 5680 or
Dell cable force-displacement report was located in this bounded search.

Searches also found standard-range-only cable datasheets, a Micro-B test report
with raw curves (wrong connector family), and mirrored third-party USB-C
receptacle reports whose full curve pages could not be retrieved reliably.
None is being presented as measured Dell or ordinary retail cable data. The
two Molex reports establish real connector-family test results; measuring the
chosen cable in the actual laptop remains the way to establish this dock's
force and alignment needs.

## Printed PETG at ordinary test conditions

### Prusament PETG

[Prusa Polymers technical datasheet v1.1, updated 2022-02-16](https://prusament.com/wp-content/uploads/2022/10/PETG_Prusament_TDS_2021_10_EN.pdf),
pages 2–3, explicitly separates printed-specimen results from filament results:

| Printed specimen property | Horizontal | Vertical XZ, using manufacturer's label |
|---|---:|---:|
| Tensile modulus, ISO 527-1 | 1.5 ± 0.1 GPa | 1.6 ± 0.1 GPa |
| Flexural modulus, ISO 178 | 1.7 ± 0.1 GPa | 1.6 ± 0.1 GPa |

Specimens were made on an Original Prusa i3 MK3 with Slic3r Prusa Edition
1.40.0, 0.20 mm layers, two perimeters, 100% rectilinear infill, no top/bottom
solid layers, 200 mm/s stated speed, 250 °C nozzle and 80 °C bed. The sheet does
not state a numerical mechanical-test ambient temperature. Its 24 °C/22% RH
footnote belongs to moisture absorption, not the tensile table. Keep the
orientation labels; do not silently equate “Vertical XZ” with a pure Z tensile
test. The sheet supplies 68 °C HDT at both 0.45 and 1.8 MPa, not an E(T) curve.

### Polymaker PETG

[Polymaker PETG TDS v2.0, file dated 2025-11-17](https://polymaker.com/wp-content/uploads/lana-downloads/TDS_Polymaker_PETG_V2.0_2025-11-17.pdf)
provides explicit printed XY and Z specimens:

| Printed specimen property | XY | Z |
|---|---:|---:|
| Young's modulus, ISO 527 / GB/T 1040 | 2311.11 ± 92.41 MPa | 2202.91 ± 52.34 MPa |
| Bending modulus, ISO 178 / GB/T 9341 | 2277.34 ± 198.09 MPa | 1958.74 ± 126.39 MPa |

The specimen-making block specifies 240 °C printing temperature, 80 °C bed,
three top/bottom layers, two shells, 100% infill, cooling off and ambient
environment. A numerical ambient temperature is not assigned to that block;
23 °C is separately associated with density/moisture data. The recommended
printing settings are not identical to this specimen protocol. Thermal values
are Tg 71.24 °C by DSC at 10 °C/min; HDT 69 °C at 0.45 MPa and 65 °C at 1.8 MPa.
Neither HDT nor Tg is a guaranteed service temperature or static modulus curve.

## Temperature dependence: original printed-specimen experiment

[Redutko, Kalwik and Szarek, Archives of Metallurgy and Materials 67 (2022), 333–339](https://www.journals.pan.pl/Content/122552/PDF/AMM-2022-1-45-Redutko.pdf?handler=pdf),
DOI [10.24425/amm.2022.137763](https://doi.org/10.24425/amm.2022.137763),
studied PETG and, separately, copper-filled PLA. The unaged PETG control had a
reported storage modulus of **1192 MPa at 67.9 °C**, followed by a sharp drop.
This is dynamic storage modulus E′, not static Young's modulus.

The PETG specimens were printed flat with full infill on a Zortrax M200 Plus:
0.4 mm nozzle, 0.14 mm layers, 245 °C extrusion, 30 °C bed and 40 mm/s. DMA used
three-point bending, 10 Hz, 80 µm amplitude and 2 °C/min heating under ISO 6721.
The paper has inconsistencies in its stated cold endpoint and some E′/E″ prose;
use its warm control result only as evidence that stiffness can decline before
nominal Tg. Do not transfer aged-in-body-fluid data or this specialist PETG
directly to the dock. It does not establish the user's static E at 40 or 50 °C.

## Material-model boundary

The modulus numbers above come from **printed FDM/FFF specimens**, not
injection-molded bulk resin. No injection-molded resin modulus has been used as
the dock's material property. Tensile modulus, flexural modulus and dynamic
storage modulus are distinct measurements; the simple beam calculation's
isotropic E remains an approximation. For final qualification, measure actual
plug insertion/extraction force, arm displacement and arm temperature on a
printed prototype, including a warm held-load check for permanent movement.

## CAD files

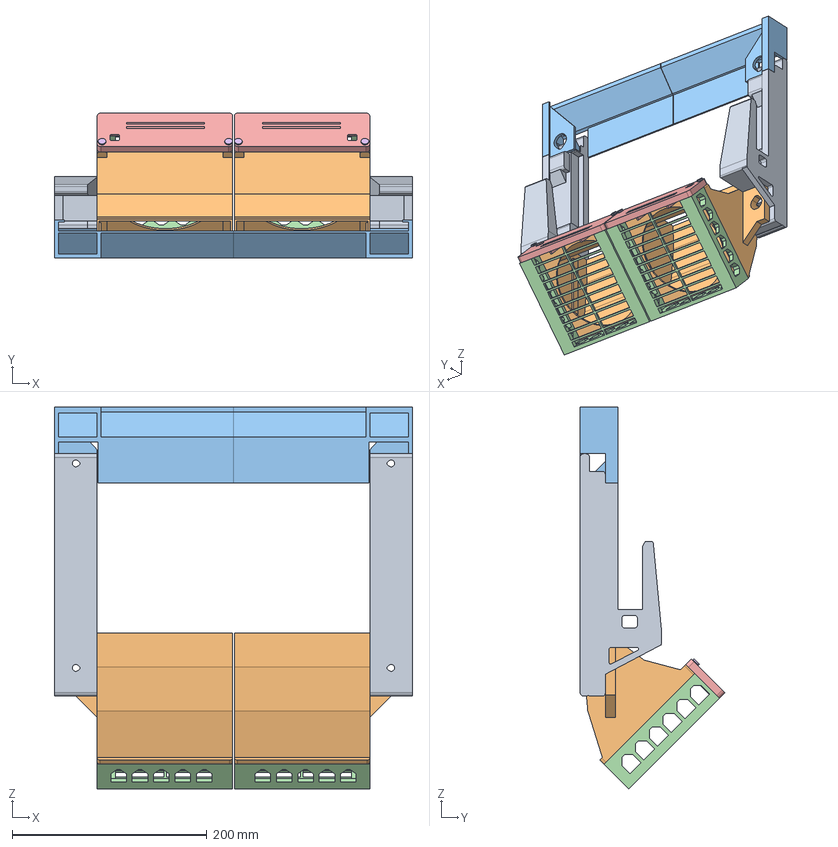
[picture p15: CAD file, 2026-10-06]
fusion/output/native/assembly.step
368.0 x 149.0 x 392.4 mm
5560-F-CRADLE-R
5560-F-DUCT-R
5560-F-RAIL-R
5560-F-TRAY-R
5560-F-CAP-R
5560-F-PIN-R x 4
5560-F-CRADLE-L
5560-F-DUCT-L
5560-F-RAIL-L
5560-F-TRAY-L
5560-F-CAP-L

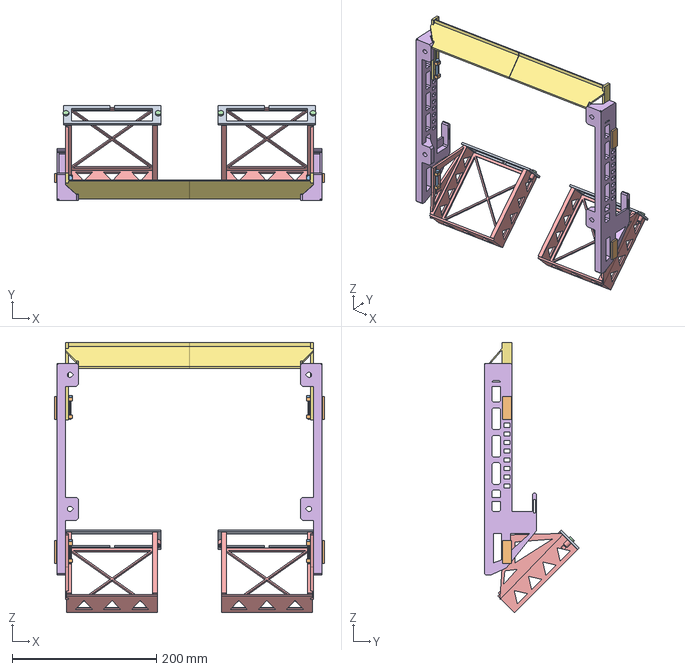
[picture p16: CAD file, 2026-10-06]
minimalist/presets/15-6-inch-example/print/M1_assembled.step
374.6 x 131.2 x 375.0 mm

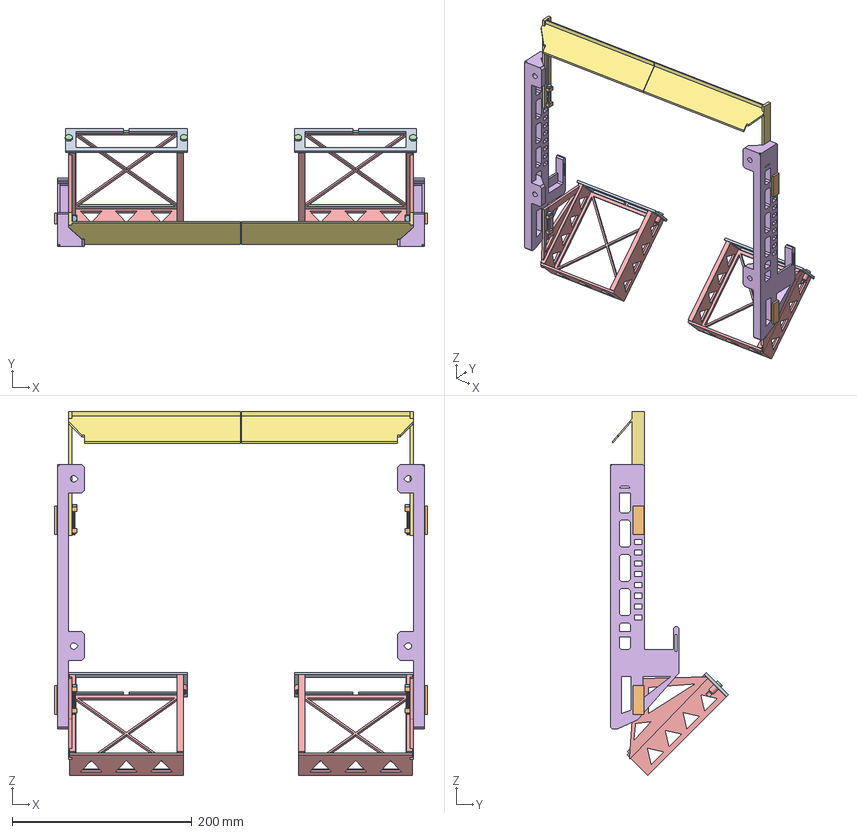
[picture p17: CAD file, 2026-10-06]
minimalist/presets/17-inch-example/print/M1_assembled.step
414.6 x 131.2 x 405.0 mm

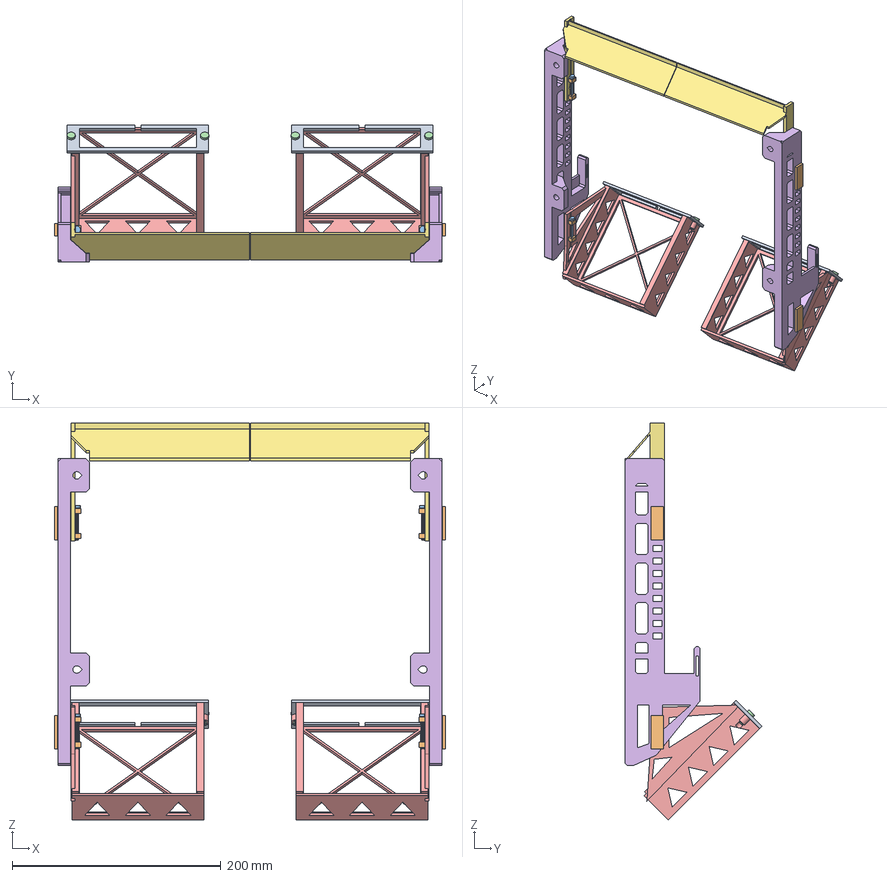
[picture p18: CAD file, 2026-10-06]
minimalist/presets/16-inch-example/print/M1_assembled.step
374.6 x 131.2 x 380.0 mm

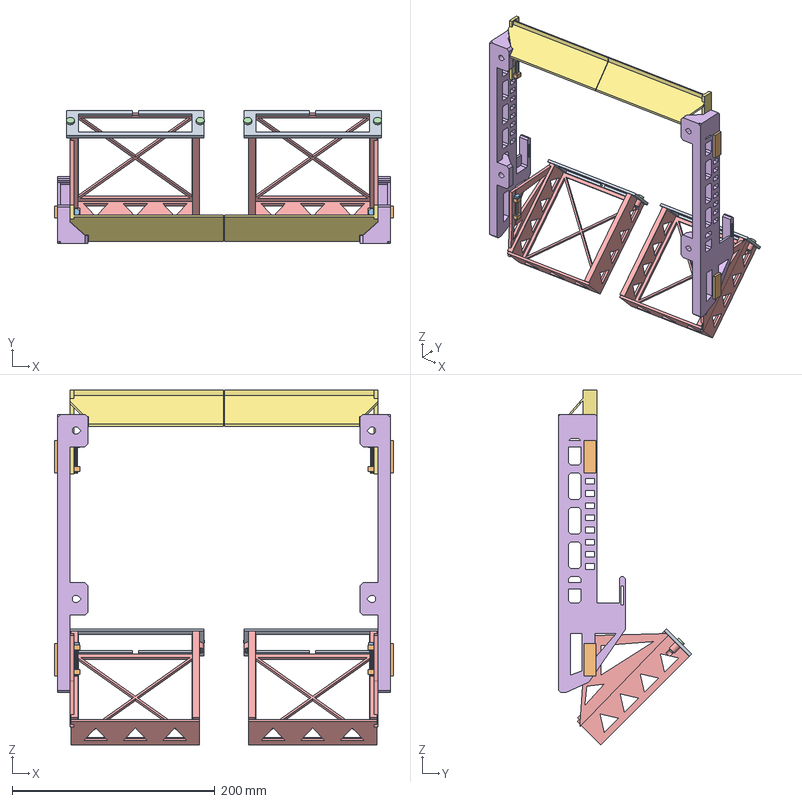
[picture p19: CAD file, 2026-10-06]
minimalist/presets/14-inch-example/print/M1_assembled.step
334.6 x 131.2 x 350.0 mm

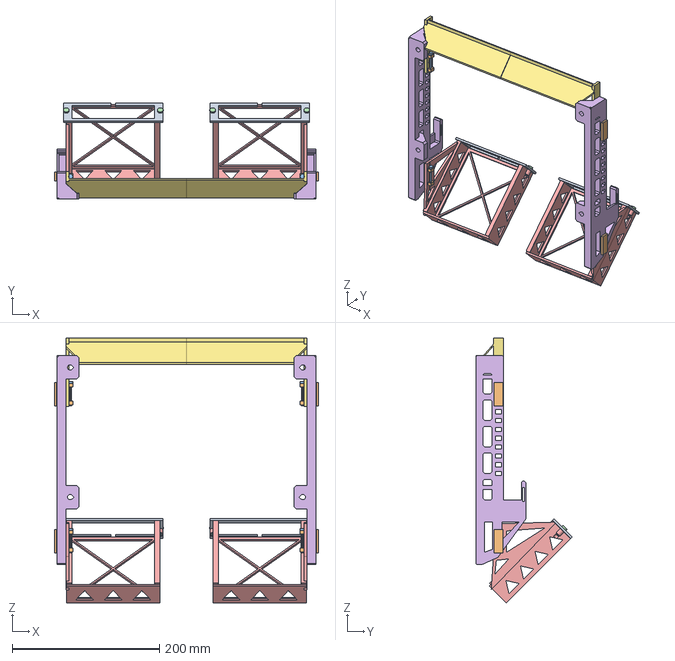
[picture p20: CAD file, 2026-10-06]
minimalist/presets/5560/print/M1_assembled.step
359.0 x 131.2 x 360.3 mm

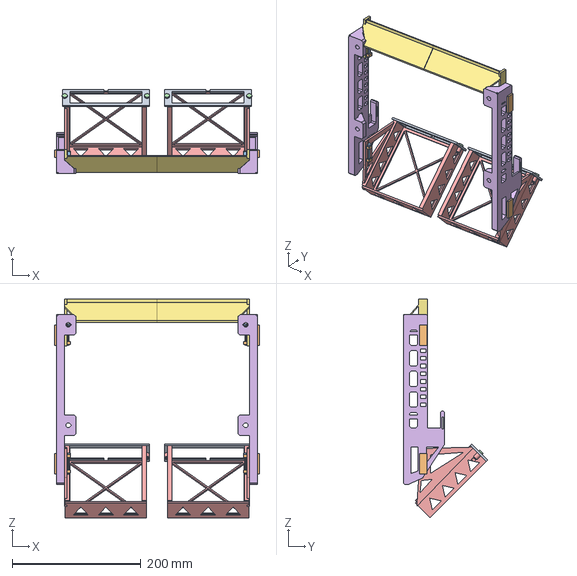
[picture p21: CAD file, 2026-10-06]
minimalist/presets/13-inch-example/print/M1_assembled.step
318.6 x 131.2 x 340.0 mm

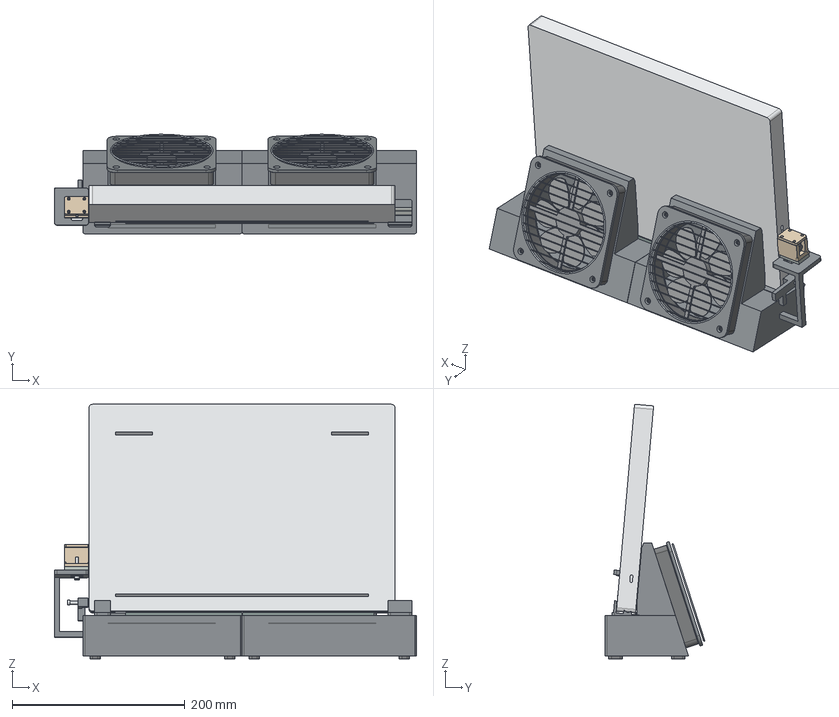
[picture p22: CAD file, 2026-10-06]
desk-dock/D6/Precision_5680_D6.step
418.7 x 115.1 x 294.4 mm
01_foot_1.0_-20
01_foot_1.0_52.43349235828353
01_foot_156.8_-20
01_foot_156.8_52.43349235828353
01_120x15_fan_frame
01_fan_hub_struts
01_blade_0
01_blade_1
01_blade_2
01_blade_3
01_blade_4
01_blade_5
01_blade_6
01_outlet_guard
01_rounded_fan_bezel
02_foot_185.1_-20
02_foot_185.1_52.43349235828353
02_foot_358.7_-20
02_foot_358.7_52.43349235828353
02_120x15_fan_frame
02_fan_hub_struts
02_blade_0
02_blade_1
02_blade_2
02_blade_3
02_blade_4
02_blade_5
02_blade_6
02_outlet_guard
02_rounded_fan_bezel
corner_pad_far
corner_pad_near
lid_bearing_liner_1
lid_bearing_liner_2
hinge_seal_42.0_-12.3
hinge_seal_177.3_-12.3
hinge_seal_42.0_11.0
hinge_seal_177.3_11.0
height_shim_pack
X_depth_overmold_clamp
front_capture_clip_0p8mm_metal
removable_plug_cap
Dell_plug_overmold_REFERENCE
USB_C_shell_REFERENCE
cassette_lock_-8.0
cassette_washer_-8.0
cassette_lock_8.0
cassette_washer_8.0
independent_M4_stop
stop_soft_tip
Precision_5680_REFERENCE
RUBBER_FOOT_rear_strip
RUBBER_FOOT_front_left
RUBBER_FOOT_front_right
01_manifold_with_cradle
02_manifold_with_cradle

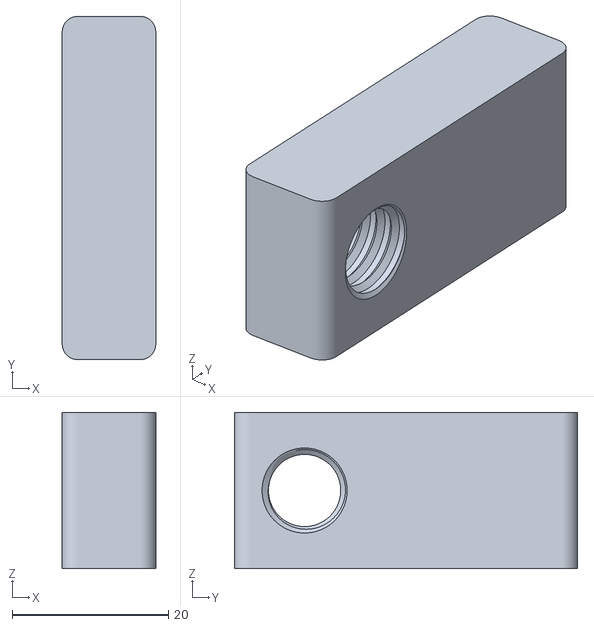
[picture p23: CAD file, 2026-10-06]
desk-dock/D7/cassette-review/chassis_stop_block.stl
12.0 x 44.0 x 20.0

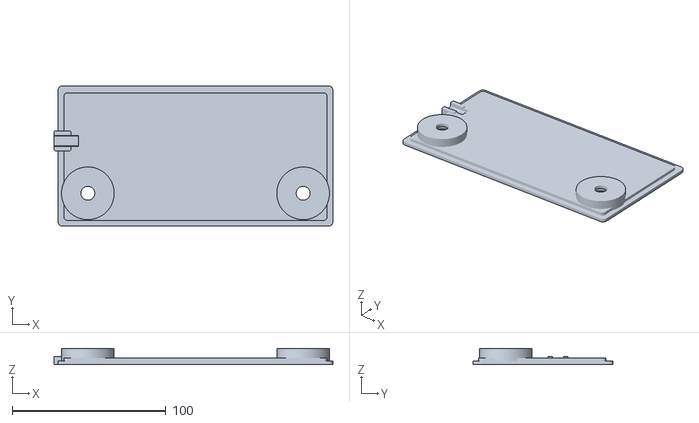
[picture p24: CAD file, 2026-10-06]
desk-dock/D7/print-review/01_bottom_panel/plate.stl
181.2 x 91.2 x 10.7

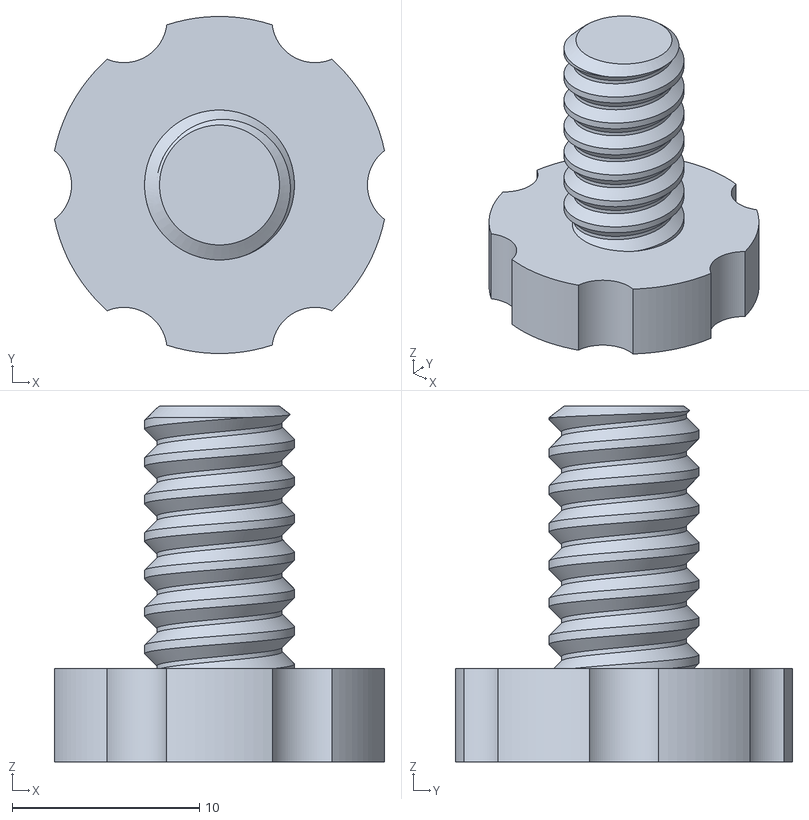
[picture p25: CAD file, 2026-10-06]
desk-dock/D7/print-review/01_bottom_thumb_lock_1/plate.stl
17.6 x 18.0 x 19.0

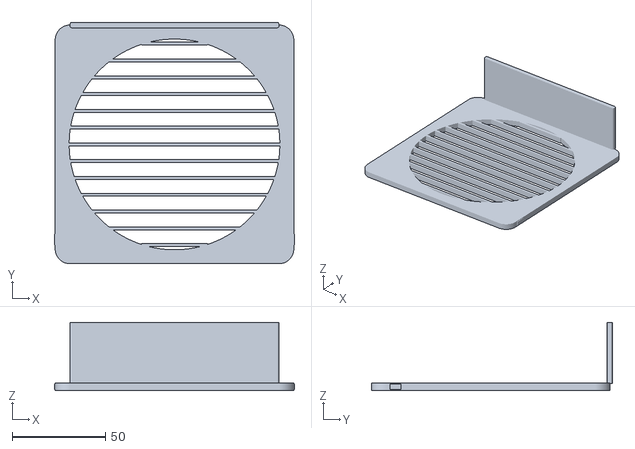
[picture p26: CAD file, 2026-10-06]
desk-dock/D7/print-review/01_fan_guard_retainer/plate.stl
128.7 x 129.5 x 36.6

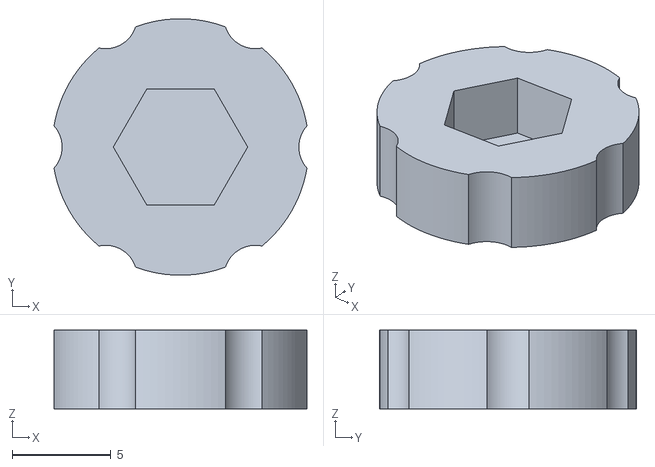
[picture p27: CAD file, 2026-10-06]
desk-dock/D7/print-review/01_fan_thumb_lock_A/plate.stl
12.8 x 13.0 x 4.00

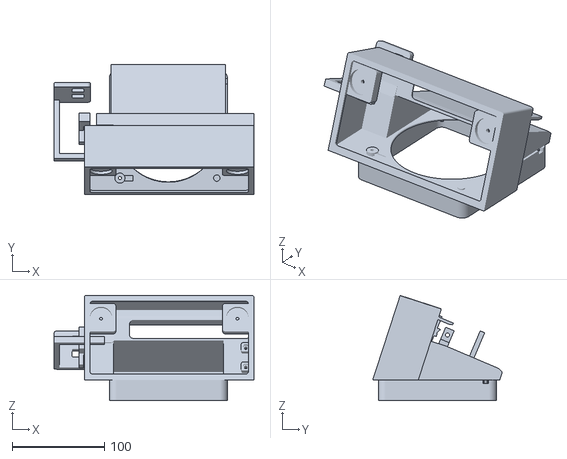
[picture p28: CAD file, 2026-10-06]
desk-dock/D7/print-review/01_manifold_with_cradle/plate.stl
216.8 x 140.6 x 114.0

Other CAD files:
desk-dock/D7/print-review/01_bottom_thumb_lock_2/plate.stl
desk-dock/D7/print-review/01_bridge_thumb_lock_1/plate.stl
desk-dock/D7/print-review/01_bridge_thumb_lock_2/plate.stl
desk-dock/D7/print-review/01_fan_thumb_lock_B/plate.stl
Precision_5560_Wall_Mount.step
REFERENCE_Estimated_Laptop_Profile.step
REFERENCE_Installed_Layout.step
desk-dock/D7/cassette-review/X_depth_overmold_clamp.stl
desk-dock/D7/cassette-review/cap_pin_receiver_bore_6.8.stl
desk-dock/D7/cassette-review/cap_pin_receiver_bore_6.9.stl
desk-dock/D7/cassette-review/cap_pin_receiver_bore_7.0.stl
desk-dock/D7/cassette-review/cassette_calibration_hand_screw.stl
desk-dock/D7/cassette-review/cassette_calibration_keeper_plate.stl
desk-dock/D7/cassette-review/cassette_cap_push_pin_6p5.stl
desk-dock/D7/cassette-review/height_shim_pack.stl
desk-dock/D7/cassette-review/independent_printed_chassis_stop_screw.stl
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

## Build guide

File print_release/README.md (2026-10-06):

# Revision H - preserved ducted prototype print set

Print one each of 01-14. STL and 3MF are alternatives for the same part; do not
print both formats. Standard 3MF models contain millimeter geometry and baked
orientation, not slicer settings or G-code.

This is the preserved Rev H prototype print set. Original root print_ready/ and Fusion/Onshape
ports remain Revision F baseline/history. Six parts are revised: ducts, trays,
and outlet rails. Both cradle/arm files are byte-identical to the already-printed
Revision F files. Caps and four pins are also unchanged.

P1S / ASA: 0.4 mm nozzle, 0.20 mm layers, 6 walls, 6 top/bottom layers, 100% fill
of the explicitly hollow CAD, 8 mm outer brim, supports off. Cradles outer-side
down with the supplied diagonal rotation; ducts inlet down; trays grille down;
caps front down; rails lip down; pins button down. Keep the baked orientations.

Fan-interface and rail-to-arm clearances measure 0.30 mm. Pin retention keeps
its intentional interference; fixed load shoulders retain seating contact.
Separate native loft-skin patches close the unintended duct-wall notches.
Revision H adds three R12 tangent airway blends per duct with two R14 exterior
support blends. Inlet and outlet profiles remain fixed. Sampled new bend walls
are at least 1.60 mm; sampled new curved overhangs stay below 40 degrees in the
inlet-down orientation. Cooling performance is not yet physically validated.

Final checks: valid native solids, constrained sketches, unchanged printed arms,
wall continuity, assembly/service clearances, closed meshes, and bed/brim/cutter
fit. Physical fit, ASA bridge quality, retention and slicer paths remain to be
checked. Use the root P1S_ASA_Print_Guide.md for material and assembly guidance.
Original fit coupons remain under print_ready/; full-length tray fit needs its
own check because the revised flank clearance is normal to the dovetail slope.

See manifest.json for hashes tying this print set to the native FCStd document.

## Orca bridge review, September 8, 2026

Both ducts need Bridge direction and Internal bridge direction set to 180°,
with Relative bridge angle and Align infill direction to model off. Keep the
baked inlet-down orientation. The corrected cross-slot paths have a maximum
unsupported span of 5.19 mm and no disconnected floating components. See
[the detailed instructions and reviewed previews](../print_release_step/ORCA_BRIDGE_REVIEW.txt).
Physical ASA bridge quality and retention still require a print check.

Rev H is a preserved prototype, not a permanent freeze on future ducted arms.
The independent [Minimalist M1 fork](../minimalist/) has new parametric arms.

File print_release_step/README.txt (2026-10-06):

REVISION H PROTOTYPE - PRINT-ORIENTED STEP FILES

14 parts, one of each numbered file. Parts 11-14 are four identical pins.
The arms (01-02) are included for completeness; yours are already printed.
This is the same geometry as the Revision H STL print release, not the
experimental 0.8 mm wall trial or the forthcoming minimalist design.

Open one STEP at a time in OrcaSlicer. Keep the baked orientation, use mm,
and do not auto-orient or scale. Each part sits at Z=0 centered on a 256 mm
P1S plate. Inspect the preview after importing because slicers can arrange
parts automatically. Do not print the whole folder together on one plate.

P1S / ASA starting setup: 0.4 mm nozzle, 0.20 mm layers, 6 walls,
6 top/bottom layers, 100% infill of the intentionally hollow CAD,
8 mm outer brim, supports off. Use the actual spool's ASA temperature and
drying instructions. Review bridges and the first layer before printing.
Both ducts need the corrected bridge direction described in
ORCA_BRIDGE_REVIEW.txt. Automatic bridge direction is unsuitable at the
long slots. The corrected paths pass the geometric screen; physical ASA
bridge quality still requires a print check.

Orientations: arms outer-side-down and diagonal; ducts inlet-down;
trays grille-down; caps broad front face down; rails lip-down; pins button-down.
Fit clearance is nominally 0.30 mm at the revised joints. Pin retention has
intentional interference. The existing fit coupons remain useful.

All 14 STEP files were reimported and checked for one valid solid, source
shape agreement, print-bed/brim clearance and matching Rev H STL bounds.
See manifest.json for per-file checks and hashes. STEP files are editable
exchange solids; the full native feature history remains in the FCStd model.

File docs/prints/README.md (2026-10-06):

# Print log

Every job sent to the P1S, newest first, with the exact geometry (source-STL SHA-256 per part), profiles, estimate,
outcome and what we learned. Source of truth is `print-log.json`; append with `tools/print-log.py add`, close out with
`tools/print-log.py update`. Printer: Bambu P1S 01P00A3C1300643 via bambu-bridge on pve.

| Id | When | What | Status | Job | Slot | Estimate | Commit |
| --- | --- | --- | --- | --- | --- | ---: | --- |
| P-0015 | 2026-09-20 07:34 | D9 P5 plate 16: M2 fan guard (calibrated PolyLite ASA), last plate for a complete dock | printed | 0ce41b8d | 3 | 1h 54m 17s / 41.28 g | 830be64 |
| P-0014 | 2026-09-20 06:33 | D9 P5 plate 18: splice ring (four clips), centre fence and three glue-up alignment keys (calibrated PolyLite ASA) | printed | 01a7a8be | 3 |  | 4af3e3b |
| P-0013 | 2026-09-19 16:08 | D9 P5 plate 14: M2 outer cradle + all 16 seam/fan/lap pins and keys, round 7.9 mm (calibrated PolyLite ASA) | printed | 954998f5 | 3 | 12h 37m 47s / 212.6 g | 302606f |
| P-0012 | 2026-09-19 13:25 | D9 P5 plate 17 (second restart): splice plate, centre contact, gap trim, four 7.9 mm frame-end pins, three alignment keys | printed | 339d6f44 | 3 | 2h 40m 17s / 43.88 g | 302606f |
| P-0011 | 2026-09-19 13:20 | D9 P5 plate 17 (restart): splice plate, centre contact, gap trim, four 7.9 mm frame-end pins, three alignment keys | failed | 3b5c27d0 | 3 | 2h 40m 17s / 43.88 g | 302606f |
| P-0010 | 2026-09-19 13:12 | D9 P5 plate 17: splice plate, centre contact, gap trim, four 7.9 mm frame-end pins, three alignment keys (calibrated PolyLite ASA) | failed | 61d8ebc2 | 3 | 2h 40m 17s / 43.88 g | 302606f |
| P-0009 | 2026-09-19 06:41 | D9 P5 plate 15: M1 fan guard + front/rear ties L/R (calibrated PolyLite ASA) | printed | 1556c722 | 3 | 7h 52m 29s / 141.52 g | 9a8410f |
| P-0008 | 2026-09-18 16:58 | D9 P5 overnight plate: M1 + M2 inner plenums, 4 contact pegs, 2 insert pins, 4 round-shaft frame-end pins + keys (calibrated PolyLite ASA) | printed | 1cb99fd5 | 3 | 14h 33m 48s / 326.58 g | 6cc690c |
| P-0007 | 2026-09-18 08:08 | D9 P5 plate 01, M1 outer cradle (calibrated PolyLite ASA) | printed | 059ef858 | 3 | 9h 36m 19s / 170.35 g | 4834be6 |
| P-0006 | 2026-09-18 07:50 | D9 P5 plate 01, M1 outer cradle (calibrated PolyLite ASA), first attempt | failed | 405f9ec4 | 3 | 9h 36m 19s / 170.35 g | 4834be6 |
| P-0005 | 2026-09-18 07:22 | D9 P5 plate 02, M1 inner plenum (PETG grey) | not-started | ede6ad47 | 2 | 6h 35m 37s / 188.94 g | 4834be6 |
| P-0004 | 2026-09-17 22:11 | R4-C bracket pair + D9 P2 fastener fit parts (PETG grey, 8 h plate) | printed | 9c88a11e | 2 | 6h 59m 10s / 217.3 g | 30998a6 |
| P-0003 | 2026-09-17 20:06 | V5 rail +3.5 mm fit coupons A/B/C (PETG grey) | printed | 0eec266d | 2 | 1h 52m 33s / 48.18 g | f442cc2 |
| P-0002 | 2026-09-17 18:41 | V4 full-rail fit coupons A/B/C (PETG grey) | printed | 0d353e74 | 2 | 1h 50m 46s / 47.02 g | 3e8792b |
| P-0001 | 2026-09-16 18:44 | D8 quick-fit bracket pair, pre-R4 revision (PETG) | printed | b8c11d5e | None |  | 502a85e |

## P-0015 - D9 P5 plate 16: M2 fan guard (calibrated PolyLite ASA), last plate for a complete dock

- When: 2026-09-20 07:34; status: **printed**; job `0ce41b8d13914295bb573a572e7ca243`; file `n/a`; AMS physical slot 3; repo commit `830be64`.
- Profiles: Repro - ASA - Polymaker PolyLite - Calibrated; process Repro Normal - 0.4 nozzle; Polymaker PolyLite ASA, calibrated (flow 0.93, shrink 99.46 %, PA 0.034), AMS slot 3
- Process: layer_height 0.2, wall_loops 5, top_shell_layers 6, sparse_infill_density 40%, sparse_infill_pattern gyroid, support_type normal(auto), support_style snug, support_on_build_plate_only 0, support_object_xy_distance 0.35, brim_width 5
- Filament: filament_flow_ratio 0.93, filament_shrink 99.46%, pressure_advance 0.034, nozzle_temperature 260, hot_plate_temp 100
- Estimate: 1h 54m 17s; 41.28 g; 58 layers; 11.6 mm tall; toolpath audit passed.
- Parts: `M2-fan-guard` (4fcbd471da01)
- Slice folder: `/mnt/c/Users/user/Documents/Codex/2026-09-17/for-x20/work/d9-p5-print-pass/asa/16-M2-guard`
- Lessons: M2 fan guard, last plate of the D9 P5 dock. All 64 printed parts now exist in ASA.

## P-0014 - D9 P5 plate 18: splice ring (four clips), centre fence and three glue-up alignment keys (calibrated PolyLite ASA)

- When: 2026-09-20 06:33; status: **printed**; job `01a7a8be885c4102894b3cb979b4f579`; file `n/a`; AMS physical slot 3; repo commit `4af3e3b`.
- Profiles: Repro - ASA - Polymaker PolyLite - Calibrated; process Repro Normal - 0.4 nozzle; Polymaker PolyLite ASA, calibrated (flow 0.93, shrink 99.46 %, PA 0.034), AMS slot 3
- Process: layer_height 0.2, wall_loops 5, top_shell_layers 6, sparse_infill_density 40%, sparse_infill_pattern gyroid, support_type normal(auto), support_style snug, support_on_build_plate_only 0, support_object_xy_distance 0.35, brim_width 5
- Filament: filament_flow_ratio 0.93, filament_shrink 99.46%, pressure_advance 0.034, nozzle_temperature 260, hot_plate_temp 100
- Parts: `splice-clip-back` (000fe166a2c4), `splice-clip-fan` (f58c36cc50a4), `splice-clip-front` (7987baa8c60f), `splice-clip-floor` (da7f6fdbf4c7), `centre-fence` (7d44088b1e52), `align-aid-front` (63200440c7ea), `align-aid-top` (550617199a98), `align-aid-fan` (83ea687b0b0e)
- Slice folder: `/mnt/c/Users/user/Documents/Codex/2026-09-17/for-x20/work/d9-p5-print-pass/asa/18-splice-ring`
- Lessons: Splice ring, centre fence and three glue-up keys in ASA, zero support as sliced. 40 layers, ran clean.

## P-0013 - D9 P5 plate 14: M2 outer cradle + all 16 seam/fan/lap pins and keys, round 7.9 mm (calibrated PolyLite ASA)

- When: 2026-09-19 16:08; status: **printed**; job `954998f5e56547f0a389ad0a2a0a04a5`; file `D9-P5-14-M2-cradle-fasteners-ASA.gcode.3mf`; AMS physical slot 3; repo commit `302606f`.
- Profiles: Repro - ASA - Polymaker PolyLite - Calibrated; process Repro Normal - 0.4 nozzle; Polymaker PolyLite ASA, calibrated (flow 0.93, shrink 99.46 %, PA 0.034), AMS slot 3
- Process: layer_height 0.2, wall_loops 5, top_shell_layers 6, sparse_infill_density 40%, sparse_infill_pattern gyroid, support_type normal(auto), support_style snug, support_on_build_plate_only 0, support_object_xy_distance 0.35, brim_width 5
- Filament: filament_flow_ratio 0.93, filament_shrink 99.46%, pressure_advance 0.034, nozzle_temperature 260, hot_plate_temp 100
- Estimate: 12h 37m 47s; 212.6 g; 538 layers; 78.0 mm tall; toolpath audit passed.
- Parts: `M2-outer-cradle-shell` (16a1ed436d3a), `M1-fan-1-pin` (62b079d87560), `M1-fan-2-pin` (62b079d87560), `M1-fan-3-pin` (62b079d87560), `M1-fan-4-pin` (62b079d87560), `M2-fan-1-pin` (62b079d87560), `M2-fan-2-pin` (62b079d87560), `M2-fan-3-pin` (62b079d87560), `M2-fan-4-pin` (62b079d87560), `M1-seam-1-pin` (2d8b004b160d), `M1-seam-2-pin` (2d8b004b160d), `M1-seam-3-pin` (2d8b004b160d), `M2-seam-1-pin` (2d8b004b160d), `M2-seam-2-pin` (2d8b004b160d), `M2-seam-3-pin` (2d8b004b160d), `front-lap-pin` (5e2050446ce0), `rear-lap-pin` (5e2050446ce0), `M1-fan-1-key` (0b621d0e7579), `M1-fan-2-key` (3905db7246ec), `M1-fan-3-key` (3905db7246ec), `M1-fan-4-key` (3905db7246ec), `M2-fan-1-key` (3905db7246ec), `M2-fan-2-key` (3905db7246ec), `M2-fan-3-key` (0b621d0e7579), `M2-fan-4-key` (3905db7246ec), `M1-seam-1-key` (3905db7246ec), `M1-seam-2-key` (3905db7246ec), `M1-seam-3-key` (3905db7246ec), `M2-seam-1-key` (3905db7246ec), `M2-seam-2-key` (3905db7246ec), `M2-seam-3-key` (3905db7246ec), `front-lap-key` (0b621d0e7579), `rear-lap-key` (0b621d0e7579)
- Slice folder: `/mnt/c/Users/user/Documents/Codex/2026-09-17/for-x20/work/d9-p5-print-pass/asa/14-M2-cradle-fasteners`
- Notes: Overnight. Bed clear confirmed by the user. Carries the first production set of round 7.9 mm pins after the fit was confirmed on plate 17. Identical ASA in slots 3 and 4.
- Lessons: Ran clean overnight, 538 layers. Completes the M2 outer cradle and all 16 seam/fan/lap pins and keys in ASA.

## P-0012 - D9 P5 plate 17 (second restart): splice plate, centre contact, gap trim, four 7.9 mm frame-end pins, three alignment keys

- When: 2026-09-19 13:25; status: **printed**; job `339d6f44684c431a9be1e180f212cd72`; file `D9-P5-17-splice-plate-contact-ASA.gcode.3mf`; AMS physical slot 3; repo commit `302606f`.
- Profiles: Repro - ASA - Polymaker PolyLite - Calibrated; process Repro Normal - 0.4 nozzle; Polymaker PolyLite ASA, calibrated (flow 0.93, shrink 99.46 %, PA 0.034), AMS slot 3
- Process: layer_height 0.2, wall_loops 5, top_shell_layers 6, sparse_infill_density 40%, sparse_infill_pattern gyroid, support_type normal(auto), support_style snug, support_on_build_plate_only 0, support_object_xy_distance 0.35, brim_width 5
- Filament: filament_flow_ratio 0.93, filament_shrink 99.46%, pressure_advance 0.034, nozzle_temperature 260, hot_plate_temp 100
- Estimate: 2h 40m 17s; 43.88 g; 504 layers; 76.4 mm tall; toolpath audit passed.
- Parts: `splice-plate` (4b78d2bde9d6), `center-contact` (dab7afcac663), `gap-trim` (fa7e352fa99a), `front-frame-L-pin` (fc529f9df46d), `front-frame-R-pin` (fc529f9df46d), `rear-frame-L-pin` (fc529f9df46d), `rear-frame-R-pin` (fc529f9df46d), `align-aid-front` (f4d05babd297), `align-aid-top` (f99404108ae4), `align-aid-fan` (8cf8430e70b6)
- Slice folder: `/mnt/c/Users/user/Documents/Codex/2026-09-17/for-x20/work/d9-p5-print-pass/asa/17-splice-plate-contact`
- Notes: Restarted after a silicone sock change. Printer was IDLE with the bed still at 87 C, so the start was quick. Same file and slot.
- Lessons: CONFIRMED 19 Sept: the round 7.9 mm pins (0.5 mm diametral in the 8.4 mm bores) fit the printed plenum bores. The 8.2 mm round trial would not enter and the P2 octagons rattled, so 7.9 mm round is the production size; no further pin change needed. First articles of the splice plate, centre contact, gap trim and glue-up keys also came off this plate.
- Follow-up: The splice plate on this plate printed badly: it was oriented standing on its end, which the slicer filled with 16931 support segments. Reverted to flat (profile on the bed) on 19 September: 5332 segments, plate 08 down from 3 h 22 m to 2 h 36 m. Reprint the splice plate from the corrected plate 08 or ASA plate 17.
- Follow-up: Root cause of the bad splice plate: the part straddled the gap, so its 2 mm tongue floated mid-height and the slicer supported the tongue's mating face. Fixed by making the plate one-sided (wholly on the M2 side, 9 mm wide) so the tongue's mating face is the bed face. Support: 16931 standing, 5332 flat straddling, 1113 flat one-sided, and now only in the bottom 3.5 mm on outboard faces.

## P-0011 - D9 P5 plate 17 (restart): splice plate, centre contact, gap trim, four 7.9 mm frame-end pins, three alignment keys

- When: 2026-09-19 13:20; status: **failed**; job `3b5c27d0dd9c413a8bc929d68ea198fd`; file `D9-P5-17-splice-plate-contact-ASA.gcode.3mf`; AMS physical slot 3; repo commit `302606f`.
- Profiles: Repro - ASA - Polymaker PolyLite - Calibrated; process Repro Normal - 0.4 nozzle; Polymaker PolyLite ASA, calibrated (flow 0.93, shrink 99.46 %, PA 0.034), AMS slot 3
- Process: layer_height 0.2, wall_loops 5, top_shell_layers 6, sparse_infill_density 40%, sparse_infill_pattern gyroid, support_type normal(auto), support_style snug, support_on_build_plate_only 0, support_object_xy_distance 0.35, brim_width 5
- Filament: filament_flow_ratio 0.93, filament_shrink 99.46%, pressure_advance 0.034, nozzle_temperature 260, hot_plate_temp 100
- Estimate: 2h 40m 17s; 43.88 g; 504 layers; 76.4 mm tall; toolpath audit passed.
- Parts: `splice-plate` (4b78d2bde9d6), `center-contact` (dab7afcac663), `gap-trim` (fa7e352fa99a), `front-frame-L-pin` (fc529f9df46d), `front-frame-R-pin` (fc529f9df46d), `rear-frame-L-pin` (fc529f9df46d), `rear-frame-R-pin` (fc529f9df46d), `align-aid-front` (f4d05babd297), `align-aid-top` (f99404108ae4), `align-aid-fan` (8cf8430e70b6)
- Slice folder: `/mnt/c/Users/user/Documents/Codex/2026-09-17/for-x20/work/d9-p5-print-pass/asa/17-splice-plate-contact`
- Notes: Restart after the user cancelled the first attempt at layer 1. Same file and slot. Stopped by the user at the start to change a silicone sock. Resubmitted as P-0012.

## P-0010 - D9 P5 plate 17: splice plate, centre contact, gap trim, four 7.9 mm frame-end pins, three alignment keys (calibrated PolyLite ASA)

- When: 2026-09-19 13:12; status: **failed**; job `61d8ebc286b44a16a6eb10a40b109111`; file `D9-P5-17-splice-plate-contact-ASA.gcode.3mf`; AMS physical slot 3; repo commit `302606f`.
- Profiles: Repro - ASA - Polymaker PolyLite - Calibrated; process Repro Normal - 0.4 nozzle; Polymaker PolyLite ASA, calibrated (flow 0.93, shrink 99.46 %, PA 0.034), AMS slot 3
- Process: layer_height 0.2, wall_loops 5, top_shell_layers 6, sparse_infill_density 40%, sparse_infill_pattern gyroid, support_type normal(auto), support_style snug, support_on_build_plate_only 0, support_object_xy_distance 0.35, brim_width 5
- Filament: filament_flow_ratio 0.93, filament_shrink 99.46%, pressure_advance 0.034, nozzle_temperature 260, hot_plate_temp 100
- Estimate: 2h 40m 17s; 43.88 g; 504 layers; 76.4 mm tall; toolpath audit passed.
- Parts: `splice-plate` (4b78d2bde9d6), `center-contact` (dab7afcac663), `gap-trim` (fa7e352fa99a), `front-frame-L-pin` (fc529f9df46d), `front-frame-R-pin` (fc529f9df46d), `rear-frame-L-pin` (fc529f9df46d), `rear-frame-R-pin` (fc529f9df46d), `align-aid-front` (f4d05babd297), `align-aid-top` (f99404108ae4), `align-aid-fan` (8cf8430e70b6)
- Slice folder: `/mnt/c/Users/user/Documents/Codex/2026-09-17/for-x20/work/d9-p5-print-pass/asa/17-splice-plate-contact`
- Notes: Submitted into FINISH after plate 15. First articles of the splice plate (standing print, rear tongue), the merged seat-and-fence contact, the L trim and the glue-up keys; the four frame-end pins replace the too-tight 8.2 mm trial. Bed clear confirmed by the user. Cancelled by the user at layer 1; the bridge recorded printer_error. Resubmitted as P-0011.

## P-0009 - D9 P5 plate 15: M1 fan guard + front/rear ties L/R (calibrated PolyLite ASA)

- When: 2026-09-19 06:41; status: **printed**; job `1556c722df0b44de8289231317fcfa9a`; file `D9-P5-15-M1-guard-ties-ASA.gcode.3mf`; AMS physical slot 3; repo commit `9a8410f`.
- Profiles: Repro - ASA - Polymaker PolyLite - Calibrated; process Repro Normal - 0.4 nozzle; Polymaker PolyLite ASA, calibrated (flow 0.93, shrink 99.46 %, PA 0.034), AMS slot 3
- Process: layer_height 0.2, wall_loops 5, top_shell_layers 6, sparse_infill_density 40%, sparse_infill_pattern gyroid, support_type normal(auto), support_style snug, support_on_build_plate_only 0, support_object_xy_distance 0.35, brim_width 5
- Filament: filament_flow_ratio 0.93, filament_shrink 99.46%, pressure_advance 0.034, nozzle_temperature 260, hot_plate_temp 100
- Estimate: 7h 52m 29s; 141.52 g; 100 layers; 16.0 mm tall; toolpath audit passed.
- Parts: `M1-fan-guard` (6ac137d69478), `front-tie-L` (8ff49336782f), `front-tie-R` (460a16da9593), `rear-tie-L` (5f493fbd40b8), `rear-tie-R` (d3c141ca15fd)
- Slice folder: `/mnt/c/Users/user/Documents/Codex/2026-09-17/for-x20/work/d9-p5-print-pass/asa/15-M1-guard-ties`
- Notes: Submitted into FINISH after the overnight plate; identical ASA in slots 3 and 4 for auto-refill. Ties carry the 12.7 mm tongue; guard has the bonus M4 holes.
- Lessons: Finished about 13:10 on 19 September (7 h 52 m estimate). Guard has the M4 pilots; ties carry the 12.7 mm tongue. Inspect: tongue nests flush, key windows, guard standoffs.

## P-0008 - D9 P5 overnight plate: M1 + M2 inner plenums, 4 contact pegs, 2 insert pins, 4 round-shaft frame-end pins + keys (calibrated PolyLite ASA)

- When: 2026-09-18 16:58; status: **printed**; job `1cb99fd5`; file `D9-P5-10-inner-pair-pegs-ASA.gcode.3mf`; AMS physical slot 3; repo commit `6cc690c`.
- Profiles: Repro - ASA - Polymaker PolyLite - Calibrated; process Repro Normal - 0.4 nozzle; Polymaker PolyLite ASA, calibrated (flow 0.93, shrink 99.46 %, PA 0.034), AMS slot 3
- Process: layer_height 0.2, wall_loops 5, top_shell_layers 6, sparse_infill_density 40%, sparse_infill_pattern gyroid, support_type normal(auto), support_style snug, support_on_build_plate_only 0, support_object_xy_distance 0.35, brim_width 5
- Filament: filament_flow_ratio 0.93, filament_shrink 99.46%, pressure_advance 0.034, nozzle_temperature 260, hot_plate_temp 100
- Estimate: 14h 33m 48s; 326.58 g; 990 layers; 91.8 mm tall; toolpath audit passed.
- Parts: `M1-fence-peg` (bdc102d6c48c), `M2-fence-peg` (5cd84efe43b1), `M1-seat-peg` (0aed55942890), `M2-seat-peg` (8d2c053555c7), `M1-insert-pin` (fc300ddeb418), `M2-insert-pin` (fc300ddeb418), `front-frame-L-pin` (e515c5742f37), `front-frame-R-pin` (e515c5742f37), `rear-frame-L-pin` (e515c5742f37), `rear-frame-R-pin` (e515c5742f37), `front-frame-L-key` (3905db7246ec), `front-frame-R-key` (3905db7246ec), `rear-frame-L-key` (3905db7246ec), `rear-frame-R-key` (3905db7246ec), `M1-inner-shell` (34fdd0866440), `M2-inner-shell` (0583ada73437)
- Slice folder: `/mnt/c/Users/user/Documents/Codex/2026-09-17/for-x20/work/d9-p5-print-pass/asa/10-inner-pair-pegs`
- Notes: Submitted straight into FINISH; printer went IDLE then RUNNING within 30 s. Pegs, pins and keys at the plate's 40 % gyroid rather than 100 %. Round-shaft trial on the four frame-end pins. Predates the fan-screw pilots and the gussets.
- Lessons: Finished about 06:40 on 19 September, an hour under the estimate. Inspect: seat/fence peg fit in the M1 cradle, round-shaft frame pins in their 8.4 mm bores, key retention. Fit check 19 Sept: the round 8.2 mm frame-end pins (the trial) would not enter the printed 8.4 mm bores in the plenum; the octagonal pins were the loose ones on P2. Decision: one pin type, round 7.9 mm (0.5 mm diametral); reprint pins from plate 07.

## P-0007 - D9 P5 plate 01, M1 outer cradle (calibrated PolyLite ASA)

- When: 2026-09-18 08:08; status: **printed**; job `059ef858`; file `D9-P5-01-M1-outer-cradle-ASA.gcode.3mf`; AMS physical slot 3; repo commit `4834be6`.
- Profiles: Repro - ASA - Polymaker PolyLite - Calibrated; process Repro Normal - 0.4 nozzle; Polymaker PolyLite ASA, calibrated (flow 0.93, shrink 99.46 %, PA 0.034), AMS slot 3
- Process: layer_height 0.2, wall_loops 5, top_shell_layers 6, sparse_infill_density 40%, sparse_infill_pattern gyroid, support_type normal(auto), support_style snug, support_on_build_plate_only 0, support_object_xy_distance 0.35, brim_width 5
- Filament: filament_flow_ratio 0.93, filament_shrink 99.46%, pressure_advance 0.034, nozzle_temperature 260, hot_plate_temp 100
- Estimate: 9h 36m 19s; 170.35 g; 548 layers; 74.4 mm tall; toolpath audit passed.
- Parts: `M1-outer-cradle-shell` (1d11da52c6cd)
- Slice folder: `/mnt/c/Users/user/Documents/Codex/2026-09-17/for-x20/work/d9-p5-print-pass/asa/01`
- Notes: Resubmitted after the watchdog fix. Finished about 16:20. Snug normal supports, 5 walls, 40 % gyroid. The bridge job row still reads "preparing": its JobRun died in the watchdog-fix restart and was re-attached as started_at.recovered; the printer completed the part.
- Lessons: Part came out nice; supports were acceptable to remove. Predates the fan-screw pilots (drill by hand with the guard as jig) and the socket-boss gussets.

## P-0006 - D9 P5 plate 01, M1 outer cradle (calibrated PolyLite ASA), first attempt

- When: 2026-09-18 07:50; status: **failed**; job `405f9ec4`; file `D9-P5-01-M1-outer-cradle-ASA.gcode.3mf`; AMS physical slot 3; repo commit `4834be6`.
- Profiles: Repro - ASA - Polymaker PolyLite - Calibrated; process Repro Normal - 0.4 nozzle; Polymaker PolyLite ASA, calibrated (flow 0.93, shrink 99.46 %, PA 0.034), AMS slot 3
- Process: layer_height 0.2, wall_loops 5, top_shell_layers 6, sparse_infill_density 40%, sparse_infill_pattern gyroid, support_type normal(auto), support_style snug, support_on_build_plate_only 0, support_object_xy_distance 0.35, brim_width 5
- Filament: filament_flow_ratio 0.93, filament_shrink 99.46%, pressure_advance 0.034, nozzle_temperature 260, hot_plate_temp 100
- Estimate: 9h 36m 19s; 170.35 g; 548 layers; 74.4 mm tall; toolpath audit passed.
- Parts: `M1-outer-cradle-shell` (1d11da52c6cd)
- Slice folder: `/mnt/c/Users/user/Documents/Codex/2026-09-17/for-x20/work/d9-p5-print-pass/asa/01`
- Notes: Killed by the bridge watchdog (FED_NO_PROGRESS, 600 s) during the 100 C bed preheat before any layer printed.
- Lessons: Bridge feed deadline raised to 1800 s (BRIDGE_FEED_DEADLINE_S), PR #28, deployed on pve the same morning.

## P-0005 - D9 P5 plate 02, M1 inner plenum (PETG grey)

- When: 2026-09-18 07:22; status: **not-started**; job `ede6ad47`; file `D9-P5-02-M1-inner-plenum.gcode.3mf`; AMS physical slot 2; repo commit `4834be6`.
- Profiles: Repro Generic PETG - 0.4 nozzle - Starter; process Repro Normal - 0.4 nozzle
- Process: layer_height 0.2, wall_loops 5, top_shell_layers 6, sparse_infill_density 40%, sparse_infill_pattern gyroid, support_type normal(auto), support_style snug, support_on_build_plate_only 0, support_object_xy_distance 0.35, brim_width 5
- Filament: filament_flow_ratio 0.95, filament_shrink 100%, nozzle_temperature 255, hot_plate_temp 70
- Estimate: 6h 35m 37s; 188.94 g; 725 layers; 91.8 mm tall; toolpath audit passed.
- Parts: `M1-inner-shell` (34fdd0866440)
- Slice folder: `/mnt/c/Users/user/Documents/Codex/2026-09-17/for-x20/work/d9-p5-print-pass/plates-prev-tongue-12.1/02`
- Notes: Bridge accepted the job but the printer refused the start with BBSTART_NOT_IDLE while showing FINISH from the R4-C plate. Dismissed on screen; plate 02 was not printed in PETG.
- Lessons: Consecutive jobs normally submit straight into FINISH; this refusal was a one-off. If it recurs, dismiss on the screen and resubmit.

## P-0004 - R4-C bracket pair + D9 P2 fastener fit parts (PETG grey, 8 h plate)

- When: 2026-09-17 22:11; status: **printed**; job `9c88a11e`; file `OPEN-ME.gcode.3mf`; AMS physical slot 2; repo commit `30998a6`.
- Profiles: Repro Generic PETG - 0.4 nozzle - Starter; process Repro Normal 15 grid - 0.4 nozzle
- Process: layer_height 0.2, wall_loops 4, top_shell_layers 5, sparse_infill_density 15%, sparse_infill_pattern grid, support_type normal(auto), support_style tree_slim, support_on_build_plate_only 0, support_object_xy_distance 0.35, brim_width 5
- Filament: filament_flow_ratio 0.95, filament_shrink 100%, nozzle_temperature 255, hot_plate_temp 70
- Estimate: 6h 59m 10s; 217.3 g; 298 layers; 38.0 mm tall; toolpath audit passed.
- Parts: `D8-R4-C-quick-fit-bracket-print-TWO` (76cd2acca0a5), `D8-R4-C-quick-fit-bracket-print-TWO-2` (76cd2acca0a5), `fan-socket-fit-fixture` (8ff048783540), `side-socket-fit-fixture` (5bb130ef78d6), `T-joint-fit-L` (561c060bed9f), `T-joint-fit-R` (ac9eaaeb9872), `M1-fan-1-pin` (fc300ddeb418), `M1-fan-3-pin` (fc300ddeb418), `front-lap-pin` (42d48155efdb), `M1-fan-1-key` (82f5a4d12c23), `M1-fan-3-key` (7a9efd6c3943), `front-lap-key` (82f5a4d12c23)
- Slice folder: `/mnt/c/Users/user/Documents/Codex/2026-09-17/for-x20/work/quartet-team/architect/r4-C-8h-orca`
- Notes: Two beefed-up R4-C brackets plus the P2 fit fixtures, three pins and keys.
- Lessons: Brackets seat the laptop well (cradle is great). Octagonal pins rattle in the 8.8 mm bores (0.6 mm diametral at corners): bores to 8.4 mm. Key barbs need 1 mm more total interference (0.8 to 1.8 mm). T tongue looked 0.6 mm proud but it was stuck support debris; the cleaned pair nests flush.

## P-0003 - V5 rail +3.5 mm fit coupons A/B/C (PETG grey)

- When: 2026-09-17 20:06; status: **printed**; job `0eec266d`; file `Precision_5680_V5_Rail_Plus_3p5mm_Fit_Coupons.gcode.3mf`; AMS physical slot 2; repo commit `f442cc2`.
- Profiles: Repro Generic PETG - 0.4 nozzle - Starter; process Repro Normal - 0.4 nozzle
- Process: layer_height 0.2, wall_loops 4, top_shell_layers 5, sparse_infill_density 20%, sparse_infill_pattern gyroid, support_type normal(auto), support_style tree_slim, support_on_build_plate_only 0, support_object_xy_distance 0.35, brim_width 5
- Filament: filament_flow_ratio 0.95, filament_shrink 100%, nozzle_temperature 255, hot_plate_temp 70
- Estimate: 1h 52m 33s; 48.18 g; 120 layers; 24.0 mm tall; toolpath audit passed.
- Parts: `A_R1_full_rail_plus_3p5mm_X_to_print_Z` (c3fbe9c04abd), `B_R2_full_rail_plus_3p5mm_X_to_print_Z` (dad7d63de9b7), `C_R2_full_rail_plus_3p5mm_plus_1mm_seat_relief_X_to_print_Z` (0e5512bfb011)
- Slice folder: `/mnt/c/Users/user/Documents/Codex/2026-09-17/for-x20/work/quartet-team/architect/v5-orca`
- Notes: Lid rail moved 3.5 mm away from seat and fence after the V4 trio all bound.
- Lessons: C (R2 seat + 1 mm relief) seated best: 3 dots wins. Rail offset confirmed at 3.5 mm.

## P-0002 - V4 full-rail fit coupons A/B/C (PETG grey)

- When: 2026-09-17 18:41; status: **printed**; job `0d353e7416234f1498326c701b233e2a`; file `Precision_5680_V4_Full_Rail_Fit_Coupons_V4 FULL RAIL A B C FIT COUPONS - ONE EACH`; AMS physical slot 2; repo commit `3e8792b`.
- Profiles: Repro Generic PETG - 0.4 nozzle - Starter; process Repro Normal - 0.4 nozzle
- Process: layer_height 0.2, wall_loops 4, top_shell_layers 5, sparse_infill_density 20%, sparse_infill_pattern gyroid, support_type normal(auto), support_style tree_slim, support_on_build_plate_only 0, support_object_xy_distance 0.35, brim_width 5
- Filament: filament_flow_ratio 0.95, filament_shrink 100%, nozzle_temperature 255, hot_plate_temp 70
- Estimate: 1h 50m 46s; 47.02 g; 120 layers; 24.0 mm tall; toolpath audit passed.
- Parts: `A_R1_full_native_rail_X_to_print_Z` (11bb78ab79a1), `B_R2_full_native_rail_X_to_print_Z` (a2ec03ec6196), `C_R2_full_rail_plus_1mm_seat_relief_X_to_print_Z` (eb23e9dbe01a)
- Slice folder: `/mnt/c/Users/user/Documents/Codex/2026-09-17/for-x20/work/quartet-team/architect/v4-orca`
- Notes: Recovered from the bridge job list (57 min actual).
- Lessons: All three V4 sizers bound: the tall lid-stop wall sat too close to the seat and fence. Fixed by moving the rail 3.5 mm outward in V5 (P-0003, the V5 coupons).

## P-0001 - D8 quick-fit bracket pair, pre-R4 revision (PETG)

- When: 2026-09-16 18:44; status: **printed**; job `b8c11d5e2216487ba26385df0b79d6fa`; file `D8-quick-fit-bracket-print-TWO_plate_1`; AMS physical slot None; repo commit `502a85e`.
- Notes: Pre-session print recovered from the bridge job list (2 h 36 m actual). Exact bracket revision not recorded; the D8 quick-fit R1/R2 sources are in desk-dock/D8/quick-fit.
- Lessons: Seat and fence needed the V-series coupons to converge; superseded by the R4-C pair (P-0004, the R4-C plate).

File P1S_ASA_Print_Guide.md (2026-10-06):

> Current designs: [Minimalist M1 guide](https://thereprocase.github.io/dell-5560-wall-mount/minimalist-guide.html) and [preserved ducted Rev H](print_release/). For both Rev H ducts, use the [corrected Orca cross-slot bridge settings](print_release_step/ORCA_BRIDGE_REVIEW.txt). This older guide retains the original design and material context.

# P1S / ASA — Revision F

Print the supplied oriented 3MF files with your **P1S, 0.4 mm nozzle, ASA,
0.20 mm layers, 6 walls, 6 top/bottom layers, 100% infill, 8 mm outer brim and
supports off**. The explicit hollow CAD sections remain empty at 100% infill.
These are standard model files, not sliced G-code or a native Bambu project.

## Print the coupons first

00_FIT_COUPONS.3mf contains a male/female joint and a split-pin/socket pair.
Check the keyed fit with hand pressure. The mortise has 0.30 mm nominal side
clearance and an open-mouth 45° roof. Try the CA bond on a second coupon set.
The pin has a 4.0 mm shaft, a 4.2 mm split crown and a 4.1 mm socket. Its small
interference is intentional; printing variation can dominate that allowance.
Adjust the socket/clearance parameter if needed. Do not scale the complete mount.

## Part set and orientations

Print one each of 01–14. Parts 11–14 are four identical push-pins supplied in
their assembly positions in STEP and button-down in the print files. The 8 mm
and 16 mm outlet rails are alternatives to the default 12 mm pair.

- Cradles: **outer side down**, diagonal on the plate. Do not place them on the wall back.
- Ducts: inclined fan inlet becomes the horizontal bed face. The open duct
  grows toward its narrow end; the joint buttress supports the mounting saddle.
- Fan trays: grille down, fan pocket open upward.
- Fan caps: broad front face down. Pins: button down, split tip up.
- Outlet rails: lip down at Z=232. The contraction and key roofs stay within
  45° from vertical; the air skin has no broad suspended ceiling.

| Representative part | Oriented size, mm |
|---|---|
| 02_right_cradle | 196.3 × 180.6 × 44.0 |
| 04_right_fan_duct | 174.5 × 132.0 × 109.9 |
| 06_right_fan_retainer | 139.0 × 49.0 × 13.0 |
| 08_right_outlet_rail | 183.8 × 39.0 × 78.0 |
| 10_right_fan_tray | 139.0 × 132.0 × 38.0 |
| 12_right_push_pin | 8.0 × 8.0 × 14.0 |

All individual parts and their 8 mm brims fit the 256 mm bed and avoid its stock
front-left cutter exclusion. Keep the supplied bracket rotation. Inspect the
slice preview for machine-generated extras. Use ordinary/off timelapse for
these plates rather than adding a separate smooth-timelapse tower.

Intentional bridges: 18 mm inside the closed cradle spine, 10 mm lower cradle
pockets and 6.6 mm dovetail roofs. Have the slicer span their short widths.
The geometric 0.20 mm audit finds no detached starts; maximum sampled reach
beyond the prior layer's 45° envelope is 8.8 mm inside the 18 mm bridge.
This is a geometry audit, not validated Bambu extrusion paths or a print test.

## Starting process settings

Use the filament manufacturer's ASA profile. Start outer/inner walls around
80/120 mm/s, first layer and bridges around 25 mm/s, and volumetric flow around
12 mm³/s. Retain the filament profile's bridge cooling; keep auxiliary cooling
off to avoid a strong draft across large ASA parts. Start elephant-foot
compensation at 0.15 mm and brim separation at 0.10 mm, then judge the coupon.

The inspected Bambu ASA profile in Studio 2.8.2.61 uses 270 °C nozzle and
100 °C PEI bed for the P1S-compatible 0.4 mm setup. These are Bambu-brand
settings; another ASA spool may need its own values. Dry to the filament
maker's instructions. Keep the enclosure closed, avoid cold drafts, use the
plate maker's adhesive guidance, and let the plate cool before removal.

## Assemble with CA and printed pins

1. Dry-fit each duct's two keys into its cradle from the room side. Dry-fit
   its outlet rail the same way. Select the outlet gap before gluing.
2. Remove the laptop and fans from the work area. Clean the mating surfaces.
   Apply a suitable gap-filling CA to the key/mortise contact surfaces and
   saddle/arm seating faces. Press each part fully against its shoulder and
   keep it seated for the adhesive maker's complete cure schedule. The keys
   support vertical load; the CA bond locks withdrawal and must pass the coupon test.
3. Form two mirrored half assemblies. Each half uses one cradle, one duct and
   one outlet rail. Their center seams are nominal clearances; no center screw
   or glued butt seam is needed to carry the laptop.
4. Slide each fan tray into the duct's dovetails. Keep this joint dry so the
   tray remains removable. Fit a 120 × 120 × 25–27 mm fan and suitable thin
   pads. The airflow arrow points **upward and toward the wall at 45°**.
5. Route the fan wire through the cap notch, seat the cap and press in its two
   split pins by hand. Do not glue pins, caps, fan frames or sliding trays.
6. Install the two half assemblies with four wall bolts and broad washers.
   Wall-hole centers are X=±162 and Z=−36/+174 mm: 324 mm between the two
   vertical bolt lines and 210 mm between each line's holes. Keep the halves
   level and parallel. All four bolts face the room through clear tool paths.
7. Add approximately 2 mm rear contact pads. Fit front pads to the actual closed
   case so it rests securely without being squeezed. Keep pads off vents and
   ports. The reference underside sits 40 mm from the wall; the bare slot is
   26 mm. Verify the rear foot and noncontact cheek-lip clearance.
8. Leave about 110 mm above the hinge. Lift the laptop 105 mm, then pull it
   forward for keyboard access. Remove two pins and the cap to service a fan.

No M3/M4 screws, nuts or heat-set inserts remain. The four toggle bolts and
washers are the only metal mounting hardware. The wall/anchor capacity, CA bond
strength, pin pullout, warm creep and physical printing remain unqualified.

Sources: [Bambu ASA](https://bambulab.com/en-us/filament/asa),
[Bambu print-volume limitations](https://wiki.bambulab.com/en/knowledge-sharing/print-volume-limitations),
[Bambu official profiles](https://github.com/bambulab/BambuStudio/tree/v02.08.02.61/resources/profiles/BBL),
[Prusa's adhesive guidance](https://blog.prusa3d.com/the-great-guide-to-gluing-and-assembling-3d-prints_44908/).

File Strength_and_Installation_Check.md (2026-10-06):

# Revision F — limited structural screen

The printed sections meet the stated bending, bearing and shear screen.
Minimum ratio to an assumed stress limit: **1.19**.
The CA bonds and printed-pin pullout have not been qualified; this is not a
complete assembly load rating or FEA.

## Assumptions and method

2.5 kg laptop; 6 kg installed assembly; 1 kg per fan module; 3× gravity;
50 N outward hinge pull. Normal/bearing limit 5 MPa; shear limit 2 MPa;
effective modulus 1,000 MPa; local multiplier 1.5. These are chosen screening
values, not measured warm ASA strengths. Print on the supplied faces with
100% infill in the remaining solid sections. Designed cavities remain empty.

The exported cradle geometry supplies net section properties every 0.5 mm,
including hollow sections and unsymmetric bending. A 10% section allowance
remains. The rear-section extraction ignores added cheek stiffness. The check
does not resolve torsion, buckling, fatigue, impact or long-term creep.

The duct uses two 8 × 40 mm keys with 12.6 mm engagement, 21 mm apart. Their
lower shoulders carry vertical load and the moment from the sideways fan
offset. The saddle retains a 10 mm root with at least 40 mm net height. The
rail keys are 9 mm wide, 25 mm apart. Their sloped leading faces print without
unsupported ledges. The four split pins retain fan caps and carry no laptop load.

| Case | Stress MPa | Assumed limit MPa | Ratio |
|---|---:|---:|---:|
| shelf 3g | 3.12 | 5.0 | 1.60 |
| tines 50N hinge pull | 3.88 | 5.0 | 1.29 |
| rear rail combined | 4.19 | 5.0 | 1.19 |
| rear rail upper tail | 2.60 | 5.0 | 1.93 |
| duct key lower shoulder bearing | 1.41 | 5.0 | 3.54 |
| duct key root shear | 0.67 | 2.0 | 3.00 |
| duct saddle root bending | 1.51 | 5.0 | 3.32 |
| fan support ledge | 0.34 | 5.0 | 14.80 |
| rail key lower shoulder bearing | 0.47 | 5.0 | 10.70 |
| split pin shear | 1.17 | 2.0 | 1.71 |
| tray dovetail bearing | 0.25 | 5.0 | 20.39 |
| tray dovetail root shear | 0.12 | 2.0 | 16.31 |
| wall hole bearing | 1.27 | 5.0 | 3.92 |
| wall washer punching | 0.13 | 2.0 | 15.84 |

## Joint demands that still need physical qualification

- Each duct: 47.8 N outward couple demand for the stated 3g fan-module case.
  CA locks the keyed lap against withdrawal. The plastic shoulder calculation
  establishes neither adhesive peel resistance nor warm bond durability.
- Each printed pin: 7.4 N retention demand. The shear check passes;
  frictional pullout, repeated use and creep remain untested. Test the coupon.
- Each upper wall anchor: 63.5 N tension; conservative carrying-anchor shear
  89.2 N. Select toggle bolts for the actual wall and those loads.

Four Ø7 mm wall holes remain at X=±162, Z=−36/+174 mm. All four bolt axes remain
normal to the wall, with clear Ø16 mm room-side tool corridors. No other metal
fasteners or heat-set inserts are required.

Estimated installed mass, including conservative laptop/fan/hardware allowances:
4.41 kg. No service temperature or physical load rating is claimed.

Regenerate with build_mount.py, section_properties.py, then strength_check.py.

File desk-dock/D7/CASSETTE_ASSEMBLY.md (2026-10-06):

# D7 connector cassette: printed hardware and service

The connector position, 25 mm cable envelope, USB-C shell and nominal calibration
ranges preserve the D6 source. The cassette remains at the keyboard-left end;
the whole station receives the same 5 degree lean as the laptop.

The cassette has a moving carrier and a separate fixed chassis stop. A broad
keyed shim locates the cassette in the carrier. Its rear shoulder carries the
plug insertion reaction. One printed 8 mm coarse screw and a 5 mm keeper plate
clamp the stack. The removable cap uses a 6.5 mm printed transverse push pin.
The chassis stop uses a printed 10 mm adjustment screw and removable soft bumper.

## Assembly

1. Print the current 8 mm/10 mm screw-and-nut coupons and 6.5 mm cap-pin fit first.
   Select the clearance that works with the actual PETG profile.
2. Fit the keyed shim from above into the carrier's 24 x 20 mm window. Place the
   cassette against its rear and side abutments. Hold the keeper plate below
   the shelf and install the 8 mm hand screw upward through it.
3. Lay the original cable into the open holder from above, with its lead pointing
   out the back along -X. The rear overmold face meets the lower insertion
   shoulder; the cable drops into the open rounded trough and rear-wall notch.
   Neither connector needs to be threaded through a printed hole.
4. Lower the cap, place its rear tongue between the two housing ears, and push
   the 6.5 mm pin toward +Y. The pin head remains on the accessible -Y side.
   The cap completes the upper insertion shoulder and rounded cable clearance.
5. Calibrate height, depth and lateral position using a replaceable keyed shim.
   The parameters encode its thickness, abutment positions and screw-bore
   position. Reprint the corrected shim and holder where their dimensions
   depend on that correction. These are discrete fitted settings, not unlocked
   slots that locate the plug by clamp friction.
6. Screw the independent 10 mm stop into its fixed block and fit the soft tip.
   Set its contact against the actual chassis after correct USB engagement.
   The fixed stop carries seated docking load independently of the moving
   connector holder. Hand-fit with the laptop supported and no docking slam.

To service the cable, unload the laptop, pull the cap pin toward -Y and lift the
cap. The upper cassette geometry stays at Y<=11.5 mm around the pivot head; the
shim extends to Y=17.5 mm below it. The hinge/breakaway calibration is documented
separately by the main D7 assembly.

## Rear cable path and folding

The source model's cylindrical rear stub is 6.5 mm in diameter and leaves the
overmold along -X. The continuation diameter is not measured Dell cable data.
The printed holder now has an 8.5 mm round-bottom trough, open upward when the
cap is removed. Its rear-wall mouth flares to 12.5 mm over the outer 2 mm of
wall thickness. The cap's rounded underside closes above the lead without
requiring the lead to pass through a closed loop during assembly.

Reserve a loose loop outside the back of the moving carrier. The screening
example continues straight for 30 mm past the rear wall, then bends downward
at a provisional 30 mm centerline radius. The 8 mm clearance envelope is
larger than the modeled 6.5 mm continuation. Neither the assumed diameter nor
the bend radius establishes the real cable's flexibility or required slack.
At release the rear outlet rises and its outward tangent turns upward; the
first part of the lead must be free to follow that movement. Keep a fixed
clamp or rigid elbow away from the outlet and check actual cable resistance.

The isolated check transports this illustrative loop with the carrier through
0..45 degrees and checks it against the fixed local hardware. This is geometric
clearance for that loop, not a cable-tension model or a guarantee for a fixed
remote cable endpoint. Main-shell, fan and real cable checks remain separate.
The exported `rear_cable_clearance_keepout_NONPRINT.step` is a clearance volume,
not a printable component or a measured cable model.

The notch interrupts the carrier's rear torsion wall. At nominal height its
round-bottom opening leaves 21.75 mm of continuous lower wall; at the minimum
height setting this falls to 17.75 mm. The exterior flare interrupts the outer
2 mm of wall thickness a further 2 mm lower. Stiffness estimates made before
the notch require revision; removal volume alone does not establish stiffness.

## Printable interfaces

- Calibration lock: custom 8 x 2 mm trapezoidal thread, 6.7 mm solid core, 20 mm hand
  knob and 7.2 mm threaded base. Under-head length is 23.9 mm plus the selected
  height correction. Its tip remains 0.85 mm below the nominal overmold bottom.
- Keyed shim: 0.35 mm clearance per face; height 5.1 mm plus correction, which is
  1.1..10.1 mm over the requested height range. The downward key is 4.3 mm deep.
- Cap pin: 6.5 mm shaft, 6.8 mm bores, 14 x 4 mm head. Two rounded 6.9 mm retention
  lands create 0.05 mm nominal radial interference in the receiving housing.
- Stop: custom 10 x 2 mm thread, 8.7 mm solid core, 24 x 6 mm hand knob, 18 mm threaded
  length plus a 3 mm smooth 8 mm stem. The fixed threaded block engages 12 mm.
- Bumper: 12 mm outside diameter, 4 mm long, 8.2 mm socket over the 8 mm stem.
  Print in a flexible material or use an equivalent removable soft contact.
  Socket retention must be fitted on a coupon; the current clearance is a
  starting point and does not establish retention.

The custom screw pairs are generated with real helical profiles and are not
ISO metric threads. Default female clearance is 0.25 mm radial and 0.15 mm axial
per flank. Screw/nut phase follows the assembled datum, including fractional
pitch offsets. Do not replace the custom mates with off-the-shelf metric nuts.

The cap has a broad pressure land over the cable body. Its default 0.30 mm
squeeze allowance is provisional. It intentionally overlaps the nominal soft
overmold reference in CAD; it does not establish actual contact pressure.
Calibrate against the real cable. Rear shoulder contact supports insertion;
extraction retention depends on overmold friction and requires a measured pull
test before docking use. The USB shell and actual overmold references retain
their source dimensions.

## Printing and verification

Print hand screws with their knobs flat on the bed and thread axis upright;
print nuts with thread axis upright. Print the cap pin on its head. The cap,
keyed shim, keeper plate and holder need orientation/support review around the
rear clevis, upper pressure land and underside key. These features are not
claimed support-free. Keep material out of the bores and thread roots when
removing supports.

`printed_fasteners.py` exports six 8 mm/10 mm nut coupons at 0.20, 0.25 and
0.30 mm radial clearance, matching 8 mm/10 mm screws, and an optional 12 mm
example (nine STLs total). `cassette_fit_coupons.py` exports three 14 x 8 mm
receiver rings with 6.8, 6.9 and 7.0 mm bores. Use the actual exported cap pin
as their male sample. These rings screen diameter and friction; their short
round walls do not reproduce the complete housing's compliance or retention.
They also print their bores vertically, whereas the assembled cap's 6.8 mm
pin bore prints horizontally in the supplied cap pose. Confirm that bore on
the actual cap; a good upright-ring fit does not establish a horizontal fit.

The revised cap remains inverted on its rear clevis. The current mesh is
32.60 x 24.27 x 10.10 mm and its section 0.1 mm above the bed is 90.2 mm².
The broad cap face starts 2.5 mm above the bed and needs accessible support.
The new cable trough opens upward in this pose; it adds no enclosed cable
tunnel. Review the horizontal pin-hole roof and remove support from the
gripping faces before fit testing. `cassette-review/cap-print-pose-review.json`
records this mesh-only orientation check.

`cassette_isolated_check.py` exports the nominal local parts and records critical
mating intersections in `cassette-review/cassette-check.json`. Intentional
exceptions are the cap's overmold squeeze, the pin's small retention lands and
the fixed stop joining the fixed support. This is an isolated nominal check;
the translated upper cap and pin are also checked against the reinforced
carrier at the eight requested adjustment corners. This does not qualify
the regenerated shim/base, full laptop/duct sweep or all combined adjustment
extremes. The actual print must establish thread fit, pin pull force, overmold
retention, warm creep and the breakaway response before load-bearing use.

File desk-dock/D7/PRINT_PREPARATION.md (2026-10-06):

# D7 print preparation - P1S / PETG / 0.4 mm

Use the individual parts and poses in the regenerated [print manifest](print-manifest.json). Do not print the assembled STEP as one object. The current release has geometric preflight evidence only: **it is unsliced, no toolpaths are approved, and nothing has been sent to a printer**.

The initial structural review profile uses **0.20 mm layers, five walls, six top and bottom layers, 100% rectilinear infill and an 8 mm outer brim**. Dense printed material is required for the initial arm, carrier, cams, axle, spring and fastening checks. Deliberately hollow CAD ducts stay hollow. Sparse infill is not credited as solid material in the calculations. Use temperatures and flow limits appropriate to the actual PETG spool; the recorded profile is a starting point, not a qualified material process.

## Orientation and support review

- Print the spring cartridge in its **unloaded shape**, with its common flat outside face on the bed. Its leaf length and bending stress run in the bed plane. The assembled viewer shows preload deflection and is not the shape to print.
- Print hand screws, nuts and large pins with their intended head or hand face on the bed and their shaft or thread axis upright. Use the manifest pose, then inspect layer strength and support-free access to the actual mating faces.
- Print bottom panels and fan grilles broad-face down. Inspect recessed panel wells and the grille's upper return. Its bars share the front print plane.
- Print the left plenum with its center-seam end wall on the bed; its tall hinge support prevents using the fan rim as a common bed plane. The right shell retains the fan-pocket-face pose. Inspect the long retention lip, trunk shoulder, rail roots, threaded bosses and connector support. Open bottoms allow support access but do not prove that the shells are support-free. Recheck the current manifest and brim fit after any change in fan thickness.
- Inspect the carrier, cap, keyed shim and keeper around their shoulders, bores and overhangs. The inverted cap starts on its taller rear clevis, leaving a 2.5 mm ledge under the broad face. The keyed shim starts on its underside key with a 4.3 mm peripheral ledge. Keep support scars away from thread roots, cam seats, pin bores and cable-contact surfaces.

Every part needs a working slicer's deposited-path and support-removal review before printing. Keep scale at 100%; correct a fit parameter instead of scaling the complete dock.

## Fit and load samples first

Use the current [8 mm and 10 mm thread samples](printed-fastener-review/) to choose a printed fit. These have real custom helical profiles; they are not interchangeable with ISO metric nuts. Use the [cap-pin samples](cassette-review/) and the actual 6.5 mm pin to assess insertion and withdrawal. The [cassette guide](CASSETTE_ASSEMBLY.md) records their current geometry and limitations.

Check the actual fan in its pocket, tune the grille's small friction lands, and fit the bottom-panel tongue before printing the full set. Refer to the current [coupon manifest](print/coupon-manifest.json) for supplied interface samples. Short samples do not capture whole-part warping, long sliding friction or warm creep.

The spring and cam need detached bench testing with a dummy plug. Verify alignment at 20 N, calibrate the release in each relevant load direction, reset repeatedly and repeat after a representative warm dwell. Keep the real laptop out of this test. The [holder and breakaway guide](arm-study/HOLDER_AND_BREAKAWAY.md) defines the targets and preload limit; 100% infill does not establish that they have been met.

## Geometric preflight and current limits

The [mesh preflight summary](print-review/mesh-preflight-summary.json) records source hashes, mesh checks, print bounds and individual P1S placement with the complete brim clear of the excluded bed area. Use its current results rather than a remembered part count or earlier dimensions. Angle screening does not determine bridge anchoring, support removal or actual deposited paths.

OrcaSlicer is the repository default. It was not relaunched after its reported crash. The earlier Bambu Studio CLI discovery fallback also failed; no successful slice is claimed from either application. The current checks use meshes and recorded printer/profile geometry without launching a slicer or contacting a printer.

A no-launch check of an exported part can be reproduced with:

```text
python desk-dock/D7/print_check.py --preflight desk-dock/D7/print/<part>.stl
```

The isolated fan, cover, cable and printed-lock geometry check can be reproduced without rebuilding or exporting the full assembly:

```text
python desk-dock/D7/form_service_isolated_check.py
```

Current assembly parts and hashes are recorded in [geometry.json](geometry.json), [print-manifest.json](print-manifest.json) and [package-manifest.json](package-manifest.json). Their evidence remains a geometric review until toolpaths and a physical prototype have been checked.

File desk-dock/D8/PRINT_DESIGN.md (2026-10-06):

# Direct-contact revision print review

Laptop contacts are integral printed surfaces; there are no contact liners or
hinge seals. The continuous lower print perimeter and foot faces now lie at
Z=-5 mm, providing 1.5 mm cover-screw clearance without optional desk pads.
The 43 manufacturing meshes require a fresh shell slice in OrcaSlicer.
See [DIRECT_CONTACTS.md](DIRECT_CONTACTS.md). All earlier slicer/mass results
below are retained as historical evidence, not approval of the new shells.

# Bearing revision print-review status

The six new cross-slot bearings have 1 mm sliding chamfers. The 43 regenerated meshes pass geometric preflight; the revised shells have not been re-sliced. Inspect bridge supports and removal in OrcaSlicer. The deposited-path and material figures below are retained as the **pre-bearing baseline**, not current shell qualification. See [HINGE_BEARINGS.md](HINGE_BEARINGS.md).

# D8 print design — P1S, PETG, 0.4 mm nozzle

Design each part around its print pose and load path. These are the D8 orientation decisions; the regenerated per-part print manifest must implement them and identify any remaining support. A CAD export or bed-fit check alone does not qualify deposited paths or strength.

## Process basis

Use OrcaSlicer by default, as required by the repository's [project instructions](../../AGENTS.md). Start with 0.20 mm layers, five walls and six top/bottom layers. Keep the connector support, carrier, bearing seats, cams, printed pins, printed spring and loaded fasteners dense for initial qualification. Hollow CAD passages remain hollow. Lightweight covers and grilles need their modeled skins and ribs; they do not need the same bulk infill as loaded mechanisms.

Use the current P1S profile for the actual PETG formulation, with its appropriate temperature and calibrated flow limit. Preserve bridge-specific cooling. Increasing cooling everywhere can improve shape while weakening layer bonding; turning it off everywhere makes bridge and overhang quality harder to control. These tradeoffs follow [Bambu's cooling documentation](https://wiki.bambulab.com/en/software/bambu-studio/auto-cooling) and [Prusa's PETG guidance](https://help.prusa3d.com/article/petg_2059). Prusa's numerical temperature and fan settings are not P1S settings.

Five walls and dense critical sections are a qualification starting point, not evidence of adequate strength. The process must preserve continuous deposited material through the intended load path. [Prusa's perimeter guidance](https://help.prusa3d.com/article/layers-and-perimeters_1748) supports increasing perimeters when seeking stronger parts; it does not establish a strength value for this geometry.

## Geometry rules

The following rules are conservative engineering choices for D8. They are not measured P1S limits.

- Give each part a broad, intentional first-layer datum. Put locating ribs, bosses and keys above that datum instead of starting a broad plate on a small projecting key.
- Target unsupported underside ramps at least **45 degrees above the horizontal bed plane**. Use chamfers and rising gussets underneath; retain fillets where they do not create a low-angle underside. The longest low-wing ribs have an explicit approximately 44-degree exception so their lower ends clear the removable cover by at least 0.3 mm; review that actual ramp in the slicer.
- Use bridges only where deposited strands have a landing at both ends. Favor the shorter clear span and inspect the actual bridge direction in the slicer. A feature that merely projects from one wall is an overhang, even if it resembles a roof in CAD.
- Do not assign a universal allowable bridge length. Review the longest required clear span with the selected PETG and profile. The underside of a bridge must not establish plug position, cam seating, a sliding fit or another precision datum.
- Give horizontal holes a self-supporting roof where the fit allows it. Use an accessible local support or a deliberately removable bridge layer where a true round bore or counterbore requires one. Keep removal access visible in the assembled-part design.
- Put primary bending tension and flexure length in the print bed plane where practical. A vertical rib is not automatically weak: its stress direction matters. Compression down through a foot differs from bending that peels its root across layer interfaces.
- Carry laptop gravity from its bearing pads through shell webs into dedicated shell feet. Keep the service lid out of that load path. Blend foot roots into webs and perimeter walls in the selected shell print pose.
- Retain local solid material and continuous perimeter paths at arm roots, screw seats, bearings and locating interfaces. Increasing infill does not repair an unfavorable layer direction or a poorly anchored wall.
- Add entry chamfers to sliding interfaces and relief at bed-contact fit edges. Correct fit parameters; do not scale the complete assembly to fit a pin or fan.

[Prusa's design guide](https://help.prusa3d.com/article/modeling-with-3d-printing-in-mind_164135) supports choosing orientation for strength, splitting geometry to improve its print pose, short supported-at-both-ends bridges, underside chamfers and fit allowances. Its overhang examples and printer-specific accuracy figures are not performance claims for the P1S. [Bambu's overhang guide](https://wiki.bambulab.com/en/filament-acc/filament/print-quality/overhang) also treats cooling and material selection as part of overhang performance; geometry still determines whether each line has support.

## Chosen orientation families

The table follows the explicit part poses in [export_print.py](export_print.py). The export manifest must resolve every production part to a named face and transformation, including mirrored or repeated parts. No new part may silently inherit a generic pose from its name prefix. An optional 90-degree rotation about print Z can improve bed placement without changing the face on the bed or the layer direction.

| Part family | D8 print decision | Reason and remaining check |
|---|---|---|
| Both manifold shells | Upright assembly orientation: flat lower shell perimeter and corner feet on the bed. | A continuous lower perimeter connects the first-layer load paths while preserving the cover cable-removal notch. Vertical shell walls carry laptop gravity into the feet. Sparse underside ribs provide roof bridge landings; the projecting fan pocket still needs accessible local support. |
| Bottom service covers | Broad exterior skin on the bed; perimeter ribs and local fastening bosses upward. | Produces a continuous flat skin and upward ribs. Keep feet and laptop reactions in the shell. Do not reintroduce a nearly full-area second plate through the locating tongue. |
| Fan grille retainers | Broad grille front face on the bed; bars lie in the bed plane. | Bars begin on the plate. Shape rail engagement and returns as rising geometry; inspect any lip that begins above an opening. |
| Four fan top clips (`01/02_fan_top_clip_1/2`) | Unloaded broad fan-local YZ side on the bed; remove fan tilt and rotate about Y by -90 degrees. | Leaf length and bending stress lie in the bed plane. The exported free shape comes from the clip's manufacturing override. Review the hook and capture geometry; fan variation must not require large permanent flexure strain. |
| `connector_module_body` | Broad rear Y=50 support face on the bed; after removing laptop lean, rotate about X by -90 degrees. | Main arm/root XZ load path lies within layers; working cam grows upward. Two 45-degree internal haunches reduce the former 40 mm cavity roof span to an 8 mm bridge. The opening remains accessible at X=-40. Review that bridge, bearing and module-locating openings in the slicer. |
| `chassis_stop_bracket` | Broad rear support face on the bed; after removing laptop lean, rotate about X by -90 degrees. | Stop bending lies in the bed plane. The horizontal female thread requires a deposited-path review. |
| `breakaway_carrier` | Upright on its reinforced lower face and guide feet after removing laptop lean; no further face-changing rotation. | The docking X reaction lies in the bed plane. Vertical-web bending still depends on layer bonding and requires whole-holder qualification. This pose sharply reduces automatic support relative to laying the front return/web face down. Remaining local supports must clear the open carrier and avoid cam and bearing seats. |
| `cassette_Z_saddle` | Broad Y=17.5 outside face on the bed; after removing laptop lean, rotate about X by -90 degrees. | Saddle load path lies in XZ layers. Inspect the open gusset bridge and screw openings. The live Z slide replaces the old keyed shim pack. |
| `X_depth_overmold_clamp` | Broad cradle underside on the bed after removing laptop lean. | This cradle supplies the live Y slide; its shoulders retain X position. Its base and thrust shoulders lie along layers, with the cable cavity open upward. |
| `sliding_plug_cap` | Broad outside face on the bed; remove laptop lean and invert about X. | The broad outer face now reaches the clevis top, removing the former 2.5 mm suspended broad ledge. Gripping features grow upward; inspect the pin bore and cable-contact details. |
| `breakaway_spring_cartridge` | Export the unloaded spring; common flat outside face on the bed, rotated about X by -90 degrees. | The assembly's preloaded shape is not the manufacturing shape. Leaf length and bending stress lie in the bed plane. D8 currently retains this printed preload mechanism; the proposed steel-spring clutch is a subsequent mechanism change. |
| Two `breakaway_spring_spacer_*` parts | Flat spacer end on the bed; remove laptop lean and rotate about X by +90 degrees. | These separate clearance-bored spacers replace the integrated standoffs that obstructed the module's bed face. Compression acts along build Z through continuous perimeter walls. The original long screws engage the module's female-threaded land. |
| Loaded printed pivot and retaining pins | Shaft axis parallel to the bed. | Prioritize continuous material along the shaft. Use a designed flat/self-supporting underside only where bearing geometry permits; otherwise use removable, accessible local support and inspect the shaft surface. A purchased shoulder pivot eliminates the printed-shaft orientation compromise. |
| Printed hand screws, module locks, stop-bracket locks, cassette Y/Z locks and threaded stop | Broad head/hand face on the bed; thread axis upright. | The exporter lists each part's required transform. This leaves screw tension and head separation dependent on layer bonding; keep dense and verify the actual clamping/release load. Keys and thrust shoulders carry docking reactions where provided. |
| Printed nuts | Broad hand/seat face on the bed; thread axis upright. | Provides clean thread geometry and flat seating. Inspect thread roots and the first-layer fit edge. |
| Bridge keys | Broad plate face on the bed. | Keeps the plate load path within layers and preserves support-free locating faces. |
| Soft stop tip | Closed contact face on the bed; socket upward. | Use the actual flexible material when specified. A PETG stand-in needs a separate soft contact pad and a rechecked stop setting. |

The foot load path and module locating interface are structural decisions. A pleasing outer form does not substitute for checking the direction of stress at those roots. Likewise, a pin laid horizontally improves continuity along its length but can still fail at a notch, local bearing surface or insufficient section.

[body_print_geometry.py](body_print_geometry.py) adds 1.6 mm thick underside ribs at a nominal 10 mm pitch, leaving 8.4 mm between adjacent roof landings. Rear-wall brackets support the outlet lip; crosswise brackets grow from the end walls beneath the low wings. A full-width vertical mouth keepout removes any new rib material from the straight outlet path. These dimensions describe the current design, not a universal approved bridge span. Verify the slicer's strand direction and anchoring between each pair of ribs, especially at end bays and cut-back portions near the mouth.

The shell orientation changed after a bounded comparison of the earlier unribbed candidate. With the same generic Cura support settings, the right shell requested approximately 518 g of support on its fan rim, 509 g on its center-seam end, and 182 g upright. Those results identify the reason for the upright pose and underside ribs; they are not current D8 print totals. The final manifest and matching toolpath report govern the current geometry.

A bounded candidate comparison also blocked automatic supports only in the rib-supported roof bays and the upper hood. It reduced estimated support, but the deposited paths failed the intended bridge direction: both hood roofs contained approximately 93 mm skin roads along X where the short bridge should run 6.61 mm along Y. The [recorded path review](print-review/bridge-path-review.json) includes the source/toolpath hashes, endpoints and preceding-layer contact check. **That reduced-support scenario was rejected.** Retain the automatic-support material estimate until the actual P1S slicer deposits correctly anchored short bridges; a support blocker alone does not establish that behavior.

The current cassette has continuous Z travel from -4 to +5 mm and Y travel from -3 to +3 mm. The independent chassis stop supplies the remaining laptop-position adjustment. These are live adjustments in [cassette.py](cassette.py); they do not require a fitting jig or replacement height shim.

## Deposited-path review and evidence

For each exported part, record its face on the bed, dimensions including brim, material, local dense regions, bridge locations, support locations and access for removal. Check the first deposited layers and every change from supported material to a bridge or overhang. Inspect continuity at thin ribs, gusset roots and fastener seats. Keep supports away from connector-contact surfaces, cam seats, sliding datums and threads.

[print_check.py](print_check.py) performs a no-launch geometric preflight after the complete print manifest exists. It checks one edge-connected watertight component, winding, signed volume and manifest agreement. Its bed screen uses the 256 by 256 mm nominal bed, conservative 250 mm print height and 18 by 28 mm lower-left exclusion. It tries 8 mm and 5 mm brims, with an optional 90-degree print-Z rotation. The report distinguishes a conservative bounding footprint from the CAD mean area through the first 0.20 mm; neither establishes adhesion or deposited-path quality.

Use [OrcaSlicer's bridge controls](https://github.com/OrcaSlicer/OrcaSlicer/wiki/quality_settings_bridging) only after inspecting the geometry. Orca distinguishes bridges across open space from internal bridging over infill. Thick internal bridges, additional bridge layers and counterbore bridge options can help where appropriate; they do not remove the need for two-ended support or a sound load path. [Prusa's bridging guidance](https://help.prusa3d.com/article/poor-bridging_1802) likewise identifies span, speed and cooling as relevant to bridge quality.

The inherited [D7 preparation record](../D7/PRINT_PREPARATION.md) reports an Orca crash and no approved toolpaths. Its [CLI discovery record](../D7/print-review/cli-discovery.json) also records a failed Windows Bambu Studio help invocation. Those records do not constitute a successful slice of D8. If Orca remains unavailable in the current environment, an explained offline slicer fallback may screen deposited paths. Label such output by the actual slicer/profile used; do not present generic review G-code as a qualified P1S print file.

[slice_screen.py](slice_screen.py) uses that offline fallback and records separate deposited model, support and brim volumes. Every input retains its SHA-256 hash. Its optional `--reuse-summary` argument reuses a completed screen only when the STL hash, Cura binary, printer/extruder definitions, machine profile, every explicit slicing setting and material-density assumption match. The reused record retains its original toolpath hash and source-summary hash. A changed CAD export therefore triggers a new screen rather than inheriting an old part-name result. Keep the generic `.gcode.txt` outputs outside the repository and out of any print release.

The [current material screen](print-review/path-screen-summary.json) covers all 42 PETG parts in the regenerated 43-part manifest; the soft stop tip is excluded from PETG slicing. Eight changed parts were sliced again and 34 reused matching evidence. All 43 meshes pass the geometric preflight; all 42 screened PETG parts keep deposited paths within the recorded bed/exclusion envelope. Those passes do not certify bridge behavior, support removal or strength.

| Material allocation | Generic estimate |
|---|---:|
| Deposited PETG model | 1,255 g |
| Automatic supports | 380 g |
| Individual part brims | 25 g |
| Total deposited PETG | **1,659 g** |

The assumptions are 1.27 g/cm³ PETG, a 0.4 mm nozzle, 0.20 mm layers, five walls, six top/bottom layers, dense infill and normal automatic supports. The CAD solid volume alone corresponds to 1,243 g. Reserve roughly **1.8–2.0 kg** for an initial build with fit/strength samples and some reprints; this is a planning allowance, not a measured production requirement. Flexible pads/liners, the soft stop, purge/start waste and hardware are additional. The generic Cura time sum is about 89 hours under its conservative speed assumptions and must not be used as a P1S timing prediction.

After toolpath review, qualify the complete connector mechanism and its adjustments with a dummy plug, including sustained warm preload, reset/release and the intended loads. Check the fan and panel fits using the actual hardware. Record measured material use from the final slicer output; separate finished parts, supports, brims and qualification samples.

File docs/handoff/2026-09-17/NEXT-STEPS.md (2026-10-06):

# D9 P5 — 18 September 2026 (current model)

Lean 8°. Modular contact on the R7 frame: seat peg per machine, fence peg
per end (tall at the plug end), one horizontal fan pin with a 0.15-mm cam
offset, push-out holes; the 8° lid rail is the only fixed contact. Plenum
front wall 24 → 26.5 for the 8° lid. P4 fit corrections kept, except the T tongue,
which is back to 12.7 mm: the 0.6 mm “proud” reading was stuck support debris.
One pin type: every pin is round 7.9 mm with a bed flat (0.5 mm diametral in the 8.4 mm bores). Octagons rattled;
the 8.2 mm round trial would not enter the printed bores. 7.9 mm printed and confirmed to fit on 19 Sept, so it is the
production size; replace any 8.2 mm trial pins from plate 07.
Bonus fan-screw holes (optional): 4.5 mm through the guards, 3.5 mm × 6 mm blind pilots in
every flange on the 105 mm pattern, for M4 × 45 screws; pins stay primary. Drill the M1 cradle
and the two inner shells printed on 18 September using the guard as a jig.
Gussets (additive only): socket bosses and pin-tip tab ends are self-supporting at 34°; M1 inner and
M2 outer lose most of their support. Plate 04 is re-sliced in calibrated ASA with gussets and pilots.
Splice ring (19 Sept): four clips close a ring round the plenum section and lock the halves to each other.
The joint is one thickness all the way round: each tongue fills the whole 2.0 mm gap to full depth along its arc core and
halves only over the 18 mm shiplap at each junction, where the neighbour's opposite half makes it back up (measured fill
4,923 of 4,929 mm3, the voids being the four key clearances). Flanges alternate, back onto M1 and front plus floor onto M2;
the fan arc has none because the fan boss stands over 5 mm proud of the outline on both halves, so that clip is held by its
end keys and its shiplaps. The back clip carries the hinge foot, the fence holder and a desk foot 0.5 mm shy of the corner
feet; the exchangeable centre fence drops into the holder. All print flat with zero support, about 14.5 g for the set, on
plate 08, with three temporary opposite-hand alignment keys for glue-up on plate 10 (19 min, no support). Epoxied.
ASA plate 18 (`d9-p5-print-pass/asa/18-splice-ring`) carries the whole ring, the fence and the three keys:
13.24 g, 49 m 56 s, zero support segments.
[Kit](../../printables/d9-p5/Precision_5680_D9_P5_Print_Kit.zip) · [fit plate](../../printables/d9-p5/OPEN-ME.3mf) · [notes](../../printables/d9-p5/README.md) · [print log](../../prints/).

1. Plates 02, 03, 05, 06, 07 (674 g, 27 h 35 m) do not depend on contact geometry: start any time.
2. Fit plate 00 (40 g, 1 h 53 m) for the P4 clearances; pegs and splice ring plate 08 (45 g, 1 h 53 m); plate 09 cradle-end trial (136 g, 7 h 01 m) to feel the 8° seat and peg fit before the cradles.
   Plate 01 (M1 outer cradle) printed in calibrated PolyLite ASA on 18 September. Overnight: 02 + 03 with the pegs,
   insert pins and round frame-end pins on one plate (`desk-dock/D9-P5/asa-10-receipts`).
   Remaining plates, regrouped for one morning and one evening swap per day (calibrated ASA, slot 3,
   sliced and verified 18 September evening in `d9-p5-print-pass/asa/14..16`):
   - Sat morning: 15 = M1 fan guard + all four ties (7 h 59 m, 142 g).
   - Sat evening: 14 = M2 outer cradle + all 16 seam/fan/lap pins and keys, round 7.9 mm pins (12 h 38 m, 213 g), overnight.
   - Sun morning: 16 = M2 fan guard alone (2 h 00 m, 41 g). Dock complete about 10:00 Sunday;
     two purchased 120 mm fans mount on pins/keys or M4 x 45 screws. Plug mechanism still excluded.
3. Outer cradles 01 and 04 (446 g, 20 h 36 m) once the pegs are trusted.
4. Other machines: re-head the pegs (`R7/build_quick_fit.py --demo-thickness`), the frame stays.

---

# D9 P4 — 18 September 2026 (archived; P5 is current)

[P4 kit](../../printables/d9-p4/Precision_5680_D9_P4_Print_Kit.zip) · [fit plate](../../printables/d9-p4/OPEN-ME.3mf) · [notes](../../printables/d9-p4/README.md). Fit plate 40 g / 1 h 53 m; plates 01–07 1,105 g / 46 h 31 m. The underside rail is on the plug-end cradle only; the far end keeps R4 because the rear foot strip sweeps through it during docking (0.47 mm overlap in X). No further leg prints planned; the formal model is P4.

The R4-C pair holds the laptop but nothing stops it tipping toward the
underside side. R5 raises the short fence at the bracket ends into a 6-mm
underside rail 64 mm above the seat datum (2.25-mm clearance, lead-in at the
top); feet and vents lie between the brackets. D9 P4 = P3 with the R5-C
cradles plus fit corrections from the printed P2 fit plate: 8.4-mm pin bores,
key barbs 1 mm more total interference (1.8 mm), T tongue 0.6 mm lower (withdrawn in P5).

1. Print the P4 fit plate 00 first and check pin friction, key retention and the T joint flush.
2. Print an R5-C bracket pair to feel the underside rail.
3. Then P4 plates 01 and 04 (cradles), and the five contact-independent plates whenever convenient.

Design note for later: make the seat, fence lower profile and hinge relief a
keyed insert per laptop so the two walls and brace stay common; try an 8-degree
lean on a bracket pair before changing the dock pose.

---

# D9 P3 kit — 17 September 2026 (late)

P3 = P2 with the outer cradles on the R4-C contact profile (V5 C seat, lid
rail +3.5 mm, thicker rail/fence, 4-mm base) and a printable edge treatment on
shells, guards and ties (fillets on print-axis corners, chamfered tie tops,
bed edges and all mating zones untouched). Pins, keys and fit plate are
identical to P2. Enclosure audits pass with zero air-volume change; all seven
plates verified in Orca. [Kit]( ../../printables/d9-p3/Precision_5680_D9_P3_Print_Kit.zip) · [notes](../../printables/d9-p3/README.md).

1. After the R4-C pair carries the laptop, print P3 plates 01 and 04 (430 g, 19 h 45 m).
2. Plates 02, 03, 05, 06, 07 (668 g, 26 h 34 m) do not depend on the contact result and can start any time.
3. Nothing was sent to the printer for P3.

---

# R4-C bracket pair — 17 September 2026 (night)

V5 coupon **C seated** (R2 seat + 1-mm relief, lid rail 3.5 mm outward). The
R4 quick-fit bracket pair carries that geometry with thicker rail, fence,
base and brace (outward/downward only), and was sent to the P1S on one plate
with the ten D9 P2 fastener fit parts: about 7 h 05 m, 217 g, dark-grey PETG.

1. [R4-C plate](../../printables/r4-fit-pair/Precision_5680_R4C_Bracket_Pair_plus_P2_Fit.3mf) · [kit]( ../../printables/r4-fit-pair/Precision_5680_R4C_Bracket_Pair_plus_P2_Fit_Kit.zip) · [notes](../../printables/r4-fit-pair/README.md).
2. Test the pair loaded: seat engagement, rocking, lid-to-rail contact, nudge stability, docking travel. Trial the P2 pins, keys, sockets and T joint.
3. If the pair passes, apply the rail move and C seat to the D9 P2 outer cradles (plates 01 and 04) and re-slice them before printing the kit.

---

# V5 fit coupons — 17 September 2026 (evening)

The printed V4 A/B/C plate was handled against the laptop: all three coupons
were wrong in the same way and C (three openings) was still not enough. The
tall lid-side rail sits too close to the seat / hinge-bearing surface and the
short fence.

V5 keeps every V4 feature and moves the entire rail side 3.5 mm further away,
normal to the rail face; the deck between seat and rail grows by 3.5 mm. Seat,
fence, C relief and identifiers are unchanged. The plate was submitted to the
P1S through the bridge (PETG, AMS slot 1). V4 prints are superseded; keep them
apart from V5 (the deck between seat and rail is 3.5 mm longer on V5).

1. [Compare the V5 coupons](../../printables/fit-v5/Precision_5680_V5_Rail_Plus_3p5mm_Fit_Coupons.3mf) on the real laptop, same protocol as before. [Complete V5 kit with instructions](../../printables/fit-v5/Precision_5680_V5_Rail_Plus_3p5mm_Fit_Kit.zip).
2. If the lid still reaches the rail first, measure the remaining gap; do not guess another increment.
3. The P2 steps below still apply once the contact geometry is settled.

---

# D9 P2 no-metal update — 17 September 2026

P2 supersedes P1 for the current cradle, plenum, fan-guard and brace print kit.
No added metal hardware: 20 printed pins and 20 keys join ten major parts.

1. [Print the P2 fastener fit plate](../../printables/d9-p2/OPEN-ME.3mf). Check insertion, retention and deliberate removal. About 40 g / 1 h 52 m.
2. [Print the V4 laptop-contact coupons](../../printables/fit-v4/Precision_5680_V4_Full_Rail_Fit_Coupons.3mf). Resolve the reported seating issue before committing to large cradles; R2 contact geometry is retained.
3. [Download the complete P2 kit](../../printables/d9-p2/Precision_5680_D9_P2_Print_Kit.zip) and [read assembly instructions](../../printables/d9-p2/README.md). Plates 01–07 make one assembly; about 1,099 g / 44 h 54 m.
4. Dry-assemble braces on the bench and install internal plenum keys before fans. Test seating with the laptop independently supported, then qualify loading, retention durability, creep, cooling and noise.

The older diagnostic next steps below are historical. Instructions to finish the D9 CAD/enclosure are superseded by P2; physical fit and performance checks remain open.

---

# D9 P1 update — 17 September 2026

[Download the complete D9 P1 print kit](../../printables/d9-p1/Precision_5680_D9_P1_Print_Kit.zip). [Six native Orca plates and assembly instructions](../../handoff-2026-09-17.html#d9-printables).

Ten new parts have completed CAD, nominal enclosure and Orca path verification. Plug mechanism excluded. Physical contact and load qualification remain open; the fit trial below still applies. Earlier instructions to finish or repair the proposed D9 enclosure are superseded by this package.

# Precision 5680 — next steps after the 17 September handoff

Work is paused at this checkpoint. V4 means the full-height A/B/C **fit
coupons** below. The separate D9 duct's proposed V4 is only a construction
plan; it is not the printable V4 fit kit.

1. **Print the V4 fit coupons.** Download the [native Orca 3MF](https://thereprocase.github.io/5680-dock/printables/fit-v4/Precision_5680_V4_Full_Rail_Fit_Coupons.3mf) or [complete fit-kit ZIP with G-code and instructions](https://thereprocase.github.io/5680-dock/printables/fit-v4/Precision_5680_V4_Full_Rail_Fit_Kit.zip). Open the 3MF in OrcaSlicer. The
   frozen plate is one each of A, B and C, P1S / 0.4 mm / Generic PETG /
   textured PEI, 47.02 g and 1 h 56 m 58 s estimated. Check that this matches
   the actual printer and material. Keep the supplied orientations. No print
   has been sent. Use the complete kit for matching G-code, profiles and CAD.
2. **Compare first contact on the real laptop.** Independently support the
   laptop; gently present each coupon at the same section and pose. Record
   variant, first-contact surface (curved seat, short fence or tall rail),
   whether the seat catches, and any remaining rock/gap. Do not load the
   coupons or flex the rails to force a fit. The original four photos are
   already retained. No need to resend them.
3. **Resolve the contact profile before a full stand print.** Use the A/B/C
   observations and, where needed, direct local measurements to select the
   seat/capture geometry. A is original R1; B retains the actual R2 changes;
   C adds a local 1-mm relief to B. Improvement with B does not identify which
   of its changes helped; C does not measure lid thickness. Do not apply a
   blanket 4-mm change from the published overall thickness. Then check full
   rail engagement, loaded stability, docking alignment and connector stops.
4. **Reassess the D9 duct and complete its supporting frame.** Supports are
   welcome on hidden/internal surfaces with removal access. Protect outward
   finished surfaces exposed to users; prefer gentler overhangs and short
   bridges anchored at both ends over cantilevers. Nonzero downward-facing
   area alone is not a failure. Classify the existing tray/lid/coupler by
   visibility, support access, fit and load path before choosing a repair or
   panel split. Repair the independently observed enclosure leak and verify
   both named ports, sections, fan clearance, joints and service access.
   Structural frame and cross-ties carry laptop/docking loads. V3/R1 remain
   unqualified diagnostic references; D9 V4 has no CAD release.
5. **Verify manufacturing after geometric design.** Once that assembly passes
   geometric review, use Orca to verify the chosen orientations, supports,
   support removal, actual bridge direction/anchoring, visible surface finish,
   small features and bed clearance. Correct specific demonstrated
   defects. Start with the relevant joint/contact specimen and inspect physical
   assembly and leakage before a complete dock print. Do not search for a
   workable design by repeated slicing.
6. **Run the bounded duct-resistance screen when ready.** The selected future
   test is one module-1 10-CFM prescribed-flow load case, after released void,
   patch/diagnostic-plane, BC and mesh checks. The recorded limit is 15 minutes,
   4 CPU workers and 8 GiB. Report computed total-pressure loss and separate
   forward/reverse flow. This is not an 800-RPM operating-point prediction.
   ARCTIC's pressure test convention remains unresolved for such a claim.
7. **Test the assembled dock at two fixed 800-RPM fans.** Establish loaded
   retention, connector protection and service access, then check normal and
   displaced seating, useful airflow versus bypass, temperatures, noise and
   rattle. Compare fan-mount compliance with fan position, speed, grille,
   sealing and microphone position held fixed. Record repeatability. No
   measured cooling or acoustic improvement is established by this handoff.

If the earlier R3 scalloped retainer is reused, inspect the saved top_cut /
face_cut crest-overlap lead before promoting that surface. It was not resolved
or tested as an installed airflow path.

The 20-N docking and 50-N release values in earlier proposals are design/test
targets, not measured performance. The complete D8 CAD remains a reference;
the reported real seating problem is still open.

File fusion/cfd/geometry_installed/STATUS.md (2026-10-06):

# Installed ambient domain: geometry checkpoint

The exported CAD fluid is a valid, closed, single connected solid of 0.28534812883859545 m³. Its bounds are X ±400 mm, Y 0–450 mm, Z −300–500 mm. The laptop cavity probe (0,45,100) mm lies in this connected ambient component. Twelve disconnected closed pockets were excluded and are individually recorded in `geometry_manifest.json`.

The fluid subtracts the 14 printed assembly solids, vented laptop shell, and two simplified Noctua housing rings. It does not subtract actuator or grille markers. All four fan-zone volumes and the grille-marker volume are inside the selected fluid (each directional outside-fluid Boolean volume is zero).

The laptop internal layout is an explicitly unmeasured surrogate. Only its shell was included in the native helper STEP export. Hidden Dell actuator and grille markers were reconstructed from the exact native helper recipe and exported parameter metadata; provenance is recorded in the manifest. No fan pressure-flow curves or resistance values were invented.

## Failed surface gate

The five named ASCII STL patches use metres and partition every surface triangle exactly once. Their union has 24,428 triangles, 12,354 vertices, **672 open edges**, zero nonmanifold edges, and zero self-intersections detected by FreeCAD. It is **not watertight and is not ready for CFD meshing**. Removing the original BRep's triangulation cache did not resolve the open edges. Coordinate rounding from 1e-12 through 1e-6 metres did not merge these seams, so this is not merely a tiny duplicate-coordinate issue.

A diagnostic STEP export/reimport produced a mesh with zero open edges. However, equivalence is unproven: coincident Boolean comparison returned near-whole-domain residual volumes of 285,463,059.11833507 and 285,348,316.5141635 mm³, despite a raw volume difference of only 0.01776677370071411 mm³. That result was rejected. The delivered patches are from the original BRep, with their failed seam check preserved; no displacement, hole filling, or silent tolerance relaxation was applied.

Next geometry work should diagnose the original BRep's shared-edge tessellation or establish independent, sufficiently strong surface equivalence for the STEP roundtrip. An OpenFOAM surfaceCheck and subsequent volume-mesh quality check are still required. The earlier sealed baseline separately has two reported OpenFOAM self-intersection locations; it remains an initial baseline, not a substitute for this installed model.

No production solver case or flow/thermal result was produced. Dell blower pressure-flow curves/RPM, grille and fin resistance, and geometric dimensions remain unresolved physical inputs. `geometry_ready` and `solver_case_ready` are both false.

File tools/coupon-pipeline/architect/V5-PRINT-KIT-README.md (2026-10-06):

# Precision 5680: V5 contact coupons, lid rail moved 3.5 mm outward

Open **OPEN-ME.3mf** in OrcaSlicer. The named, locked plate contains one of
each coupon in its verified print pose. The matching standalone G-code is
for the frozen **P1S, 0.4-mm nozzle, Generic PETG, textured PEI** profile.
Estimated whole plate: **1 hour 52 minutes model time (1 h 59 m with
start-up), 48.18 g.**

## What changed from V4

The printed V4 plate was handled against the real laptop: all three coupons
were wrong in the same way, and C (three openings) was still not enough. The
tall lid-side rail (the lid stop) sat too close to the seat / hinge-bearing
surface and the short fence.

V5 is V4 with the **entire rail side moved 3.5 mm further away**, measured
normal to the rail face. The flat deck between the seat and the rail is
3.5 mm longer, so each coupon grows by 3.5 mm in that direction. Nothing on
the seat/fence side moved: the short fence, the curved seat, the C relief band
and the identifier openings keep their V4 coordinates.

| Coupon | Identification | What it is |
| --- | --- | --- |
| A | One 2-mm square through-hole | V4 A (original R1 contact geometry, full rail) with the rail side moved 3.5 mm out |
| B | Two 2-mm square through-holes | V4 B (R2 capture changes and extended seat curve) with the rail side moved 3.5 mm out |
| C | Three 2-mm square through-holes | V4 C (B plus the 1-mm local seat relief) with the rail side moved 3.5 mm out |

Fence inner face to rail inner face: A 22.42 mm in V4, 25.92 mm in V5;
B and C 24.42 mm in V4, 27.92 mm in V5.

**V5 prints look like V4 prints.** Tell them apart by the flat deck between
the seat and the tall rail, which is 3.5 mm longer on V5. Label or discard
the V4 prints before comparing.

## Contact check

Support the laptop independently and present one coupon gently at the same
local section where the original leg engages. Keep fingers clear of the
contact gap. Observe which surface touches first: the intended curved seat,
the short backup fence, or the tall lid-side rail. Do not bend the rail to
make it fit or use the coupon to carry the laptop's weight.

Compare A, B and C at the same section and orientation. Record the variant,
first-contact location and whether the curved seat actually engages. If the
seat now engages with the rail clear of the lid, 3.5 mm is enough for this
local check; if the lid still reaches the rail first, the remaining gap is
the next measurement to take. A successful handheld contact check does not
establish loaded stability, retention, full-dock alignment or connector
protection.

## Manufacturing evidence

The broad profile is the designed bed face. Original X becomes print Z, and
the source geometry, the deck filler and all cuts have a constant section
through that axis. Orca 2.4.2 verified the selected orientation: automatic
supports enabled, **zero emitted support paths and zero external bridges**.
Internal infill closure occurs near the top skin at print Z=23.2 mm.

The prepared objects keep their orientations and 16-mm minimum spacing.
Model and brim paths stay inside the P1S bed and away from its front-left
excluded area. The native project's embedded G-code matches the standalone
file byte for byte. All six identifiers retain a 1-mm road-clear core and
surrounding walls on all 120 layers, checked in the frozen (0,+2)-mm nozzle
offset frame. An independent comparison rebuilt each V5 solid from the frozen
V4 STEP with explicit boxes and found zero symmetric difference.

The frozen process uses 0.20-mm layers, four walls, five top/bottom layers,
20% gyroid infill and a 5-mm outer brim. It is a diagnostic-coupon process,
not a structural qualification profile for the major dock revision.

## Contents and reproducibility

`fallback-CAD/` holds individual print-oriented STLs and original-frame STEPs.
`frozen-profiles/` contains the exact printer/process/filament snapshots.
`verification/` and `previews/` preserve the checks and visible evidence.
`source/` includes the editable builders and their local STEP/JSON inputs.
With compatible CadQuery, trimesh and Pillow installed, the source can be
rebuilt by running `source/profile-v5/build_full_rail_coupon_v5.py` with
`--d8 source/D8 --out <new-output-directory>` from this package directory;
it imports the V4 and V2 builders beside it.

The 3.5 mm is the requested trial increment from handling the printed V4
plate, not a measured lid thickness or curvature. R1/R2 contact data came
from a visualization reference, not manufacturing metrology.

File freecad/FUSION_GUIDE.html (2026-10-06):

# Your FreeCAD workspace

The top tabs switch native workbenches; the command strip underneath follows the selected workspace.

Fusion habit | Here
Pan / orbit / zoom | Middle-drag / Shift+middle-drag / mouse wheel (Revit navigation)
Design solid | SOLID → CREATE: create a Body, then sketches and Pad/Pocket features.
Sketch workspace | SKETCH: sketch geometry and dimensional constraints. Finish sketch returns control to feature modeling.
Extrude / combine separate solids | SOLID: Extrude, Union and Cut. Most of this mount uses this native feature family.
Browser / feature history | Model tree at left. Expand a feature to find its sketch and dependencies. FreeCAD does not provide Fusion's bottom timeline.
Feature dialog | Tasks panel at right. Select a feature in the tree and use its Data properties or double-click to edit where supported.
Change parameters | MODIFY → Change parameters opens the model's organized spreadsheet. Blue cells are inputs; gray/reference cells explain derived or frozen values.
Assembly | SOLID → ASSEMBLE exposes native links and joints. The installed assembly is separate from source construction groups.
Inspect | SOLID → INSPECT provides Measure, Fit and standard views.
Visibility / multiselect | Space toggles selected objects. Ctrl adds to selection.

## Printing constraint

Both gray cradles/arms are frozen because printing has started. Do not change shared arm dimensions. Teal outlet-rail refinements must fit the frozen arm baseline in frozen_print_arms/.

## Appearance and recovery

Matte teal, graphite and gold with dark outlines; solid background #9EA6AD. The local workspace module reapplies the theme and ribbon at startup. Preferences and layout backups live beside the model. Keep app error reporting available through View → Panels → Report view; logs are captured by the model's local runner.

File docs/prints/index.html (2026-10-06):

# 5680 dock print log

Every job sent to the P1S, newest first, with the exact geometry printed (source-STL SHA-256 per part), profiles, estimate, outcome and lessons. Source of truth: print-log.json.

Id | When | What | Status | Job | Slot | Estimate | Commit
P-0015 | 2026-09-20 07:34 | D9 P5 plate 16: M2 fan guard (calibrated PolyLite ASA), last plate for a complete dock | printed | 0ce41b8d | 3 | 1h 54m 17s / 41.28 g | 830be64
P-0014 | 2026-09-20 06:33 | D9 P5 plate 18: splice ring (four clips), centre fence and three glue-up alignment keys (calibrated PolyLite ASA) | printed | 01a7a8be | 3 | | 4af3e3b
P-0013 | 2026-09-19 16:08 | D9 P5 plate 14: M2 outer cradle + all 16 seam/fan/lap pins and keys, round 7.9 mm (calibrated PolyLite ASA) | printed | 954998f5 | 3 | 12h 37m 47s / 212.6 g | 302606f
P-0012 | 2026-09-19 13:25 | D9 P5 plate 17 (second restart): splice plate, centre contact, gap trim, four 7.9 mm frame-end pins, three alignment keys | printed | 339d6f44 | 3 | 2h 40m 17s / 43.88 g | 302606f
P-0011 | 2026-09-19 13:20 | D9 P5 plate 17 (restart): splice plate, centre contact, gap trim, four 7.9 mm frame-end pins, three alignment keys | failed | 3b5c27d0 | 3 | 2h 40m 17s / 43.88 g | 302606f
P-0010 | 2026-09-19 13:12 | D9 P5 plate 17: splice plate, centre contact, gap trim, four 7.9 mm frame-end pins, three alignment keys (calibrated PolyLite ASA) | failed | 61d8ebc2 | 3 | 2h 40m 17s / 43.88 g | 302606f
P-0009 | 2026-09-19 06:41 | D9 P5 plate 15: M1 fan guard + front/rear ties L/R (calibrated PolyLite ASA) | printed | 1556c722 | 3 | 7h 52m 29s / 141.52 g | 9a8410f
P-0008 | 2026-09-18 16:58 | D9 P5 overnight plate: M1 + M2 inner plenums, 4 contact pegs, 2 insert pins, 4 round-shaft frame-end pins + keys (calibrated PolyLite ASA) | printed | 1cb99fd5 | 3 | 14h 33m 48s / 326.58 g | 6cc690c
P-0007 | 2026-09-18 08:08 | D9 P5 plate 01, M1 outer cradle (calibrated PolyLite ASA) | printed | 059ef858 | 3 | 9h 36m 19s / 170.35 g | 4834be6
P-0006 | 2026-09-18 07:50 | D9 P5 plate 01, M1 outer cradle (calibrated PolyLite ASA), first attempt | failed | 405f9ec4 | 3 | 9h 36m 19s / 170.35 g | 4834be6
P-0005 | 2026-09-18 07:22 | D9 P5 plate 02, M1 inner plenum (PETG grey) | not-started | ede6ad47 | 2 | 6h 35m 37s / 188.94 g | 4834be6
P-0004 | 2026-09-17 22:11 | R4-C bracket pair + D9 P2 fastener fit parts (PETG grey, 8 h plate) | printed | 9c88a11e | 2 | 6h 59m 10s / 217.3 g | 30998a6
P-0003 | 2026-09-17 20:06 | V5 rail +3.5 mm fit coupons A/B/C (PETG grey) | printed | 0eec266d | 2 | 1h 52m 33s / 48.18 g | f442cc2
P-0002 | 2026-09-17 18:41 | V4 full-rail fit coupons A/B/C (PETG grey) | printed | 0d353e74 | 2 | 1h 50m 46s / 47.02 g | 3e8792b
P-0001 | 2026-09-16 18:44 | D8 quick-fit bracket pair, pre-R4 revision (PETG) | printed | b8c11d5e | | | 502a85e

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

- When 2026-09-20 07:34; status printed; job 0ce41b8d13914295bb573a572e7ca243; file n/a; AMS physical slot 3; repo commit 830be64.
- Profiles: Repro - ASA - Polymaker PolyLite - Calibrated; process Repro Normal - 0.4 nozzle; Polymaker PolyLite ASA, calibrated (flow 0.93, shrink 99.46 %, PA 0.034), AMS slot 3
- Process: layer_height 0.2, wall_loops 5, top_shell_layers 6, sparse_infill_density 40%, sparse_infill_pattern gyroid, support_type normal(auto), support_style snug, support_on_build_plate_only 0, support_object_xy_distance 0.35, brim_width 5
- Filament: filament_flow_ratio 0.93, filament_shrink 99.46%, pressure_advance 0.034, nozzle_temperature 260, hot_plate_temp 100
- Estimate: 1h 54m 17s; 41.28 g; 58 layers; 11.6 mm tall; toolpath audit passed.
- Parts: M2-fan-guard (4fcbd471da01)
- Lessons: M2 fan guard, last plate of the D9 P5 dock. All 64 printed parts now exist in ASA.

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

- When 2026-09-20 06:33; status printed; job 01a7a8be885c4102894b3cb979b4f579; file n/a; AMS physical slot 3; repo commit 4af3e3b.
- Profiles: Repro - ASA - Polymaker PolyLite - Calibrated; process Repro Normal - 0.4 nozzle; Polymaker PolyLite ASA, calibrated (flow 0.93, shrink 99.46 %, PA 0.034), AMS slot 3
- Process: layer_height 0.2, wall_loops 5, top_shell_layers 6, sparse_infill_density 40%, sparse_infill_pattern gyroid, support_type normal(auto), support_style snug, support_on_build_plate_only 0, support_object_xy_distance 0.35, brim_width 5
- Filament: filament_flow_ratio 0.93, filament_shrink 99.46%, pressure_advance 0.034, nozzle_temperature 260, hot_plate_temp 100
- Parts: splice-clip-back (000fe166a2c4), splice-clip-fan (f58c36cc50a4), splice-clip-front (7987baa8c60f), splice-clip-floor (da7f6fdbf4c7), centre-fence (7d44088b1e52), align-aid-front (63200440c7ea), align-aid-top (550617199a98), align-aid-fan (83ea687b0b0e)
- Lessons: Splice ring, centre fence and three glue-up keys in ASA, zero support as sliced. 40 layers, ran clean.

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

- When 2026-09-19 16:08; status printed; job 954998f5e56547f0a389ad0a2a0a04a5; file D9-P5-14-M2-cradle-fasteners-ASA.gcode.3mf; AMS physical slot 3; repo commit 302606f.
- Profiles: Repro - ASA - Polymaker PolyLite - Calibrated; process Repro Normal - 0.4 nozzle; Polymaker PolyLite ASA, calibrated (flow 0.93, shrink 99.46 %, PA 0.034), AMS slot 3
- Process: layer_height 0.2, wall_loops 5, top_shell_layers 6, sparse_infill_density 40%, sparse_infill_pattern gyroid, support_type normal(auto), support_style snug, support_on_build_plate_only 0, support_object_xy_distance 0.35, brim_width 5
- Filament: filament_flow_ratio 0.93, filament_shrink 99.46%, pressure_advance 0.034, nozzle_temperature 260, hot_plate_temp 100
- Estimate: 12h 37m 47s; 212.6 g; 538 layers; 78.0 mm tall; toolpath audit passed.
- Parts: M2-outer-cradle-shell (16a1ed436d3a), M1-fan-1-pin (62b079d87560), M1-fan-2-pin (62b079d87560), M1-fan-3-pin (62b079d87560), M1-fan-4-pin (62b079d87560), M2-fan-1-pin (62b079d87560), M2-fan-2-pin (62b079d87560), M2-fan-3-pin (62b079d87560), M2-fan-4-pin (62b079d87560), M1-seam-1-pin (2d8b004b160d), M1-seam-2-pin (2d8b004b160d), M1-seam-3-pin (2d8b004b160d), M2-seam-1-pin (2d8b004b160d), M2-seam-2-pin (2d8b004b160d), M2-seam-3-pin (2d8b004b160d), front-lap-pin (5e2050446ce0), rear-lap-pin (5e2050446ce0), M1-fan-1-key (0b621d0e7579), M1-fan-2-key (3905db7246ec), M1-fan-3-key (3905db7246ec), M1-fan-4-key (3905db7246ec), M2-fan-1-key (3905db7246ec), M2-fan-2-key (3905db7246ec), M2-fan-3-key (0b621d0e7579), M2-fan-4-key (3905db7246ec), M1-seam-1-key (3905db7246ec), M1-seam-2-key (3905db7246ec), M1-seam-3-key (3905db7246ec), M2-seam-1-key (3905db7246ec), M2-seam-2-key (3905db7246ec), M2-seam-3-key (3905db7246ec), front-lap-key (0b621d0e7579), rear-lap-key (0b621d0e7579)
- Notes: Overnight. Bed clear confirmed by the user. Carries the first production set of round 7.9 mm pins after the fit was confirmed on plate 17. Identical ASA in slots 3 and 4.
- Lessons: Ran clean overnight, 538 layers. Completes the M2 outer cradle and all 16 seam/fan/lap pins and keys in ASA.

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

- When 2026-09-19 13:25; status printed; job 339d6f44684c431a9be1e180f212cd72; file D9-P5-17-splice-plate-contact-ASA.gcode.3mf; AMS physical slot 3; repo commit 302606f.
- Profiles: Repro - ASA - Polymaker PolyLite - Calibrated; process Repro Normal - 0.4 nozzle; Polymaker PolyLite ASA, calibrated (flow 0.93, shrink 99.46 %, PA 0.034), AMS slot 3
- Process: layer_height 0.2, wall_loops 5, top_shell_layers 6, sparse_infill_density 40%, sparse_infill_pattern gyroid, support_type normal(auto), support_style snug, support_on_build_plate_only 0, support_object_xy_distance 0.35, brim_width 5
- Filament: filament_flow_ratio 0.93, filament_shrink 99.46%, pressure_advance 0.034, nozzle_temperature 260, hot_plate_temp 100
- Estimate: 2h 40m 17s; 43.88 g; 504 layers; 76.4 mm tall; toolpath audit passed.
- Parts: splice-plate (4b78d2bde9d6), center-contact (dab7afcac663), gap-trim (fa7e352fa99a), front-frame-L-pin (fc529f9df46d), front-frame-R-pin (fc529f9df46d), rear-frame-L-pin (fc529f9df46d), rear-frame-R-pin (fc529f9df46d), align-aid-front (f4d05babd297), align-aid-top (f99404108ae4), align-aid-fan (8cf8430e70b6)
- Notes: Restarted after a silicone sock change. Printer was IDLE with the bed still at 87 C, so the start was quick. Same file and slot.
- Lessons: CONFIRMED 19 Sept: the round 7.9 mm pins (0.5 mm diametral in the 8.4 mm bores) fit the printed plenum bores. The 8.2 mm round trial would not enter and the P2 octagons rattled, so 7.9 mm round is the production size; no further pin change needed. First articles of the splice plate, centre contact, gap trim and glue-up keys also came off this plate.
- Follow-up: The splice plate on this plate printed badly: it was oriented standing on its end, which the slicer filled with 16931 support segments. Reverted to flat (profile on the bed) on 19 September: 5332 segments, plate 08 down from 3 h 22 m to 2 h 36 m. Reprint the splice plate from the corrected plate 08 or ASA plate 17.
- Follow-up: Root cause of the bad splice plate: the part straddled the gap, so its 2 mm tongue floated mid-height and the slicer supported the tongue's mating face. Fixed by making the plate one-sided (wholly on the M2 side, 9 mm wide) so the tongue's mating face is the bed face. Support: 16931 standing, 5332 flat straddling, 1113 flat one-sided, and now only in the bottom 3.5 mm on outboard faces.

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

- When 2026-09-19 13:20; status failed; job 3b5c27d0dd9c413a8bc929d68ea198fd; file D9-P5-17-splice-plate-contact-ASA.gcode.3mf; AMS physical slot 3; repo commit 302606f.
- Profiles: Repro - ASA - Polymaker PolyLite - Calibrated; process Repro Normal - 0.4 nozzle; Polymaker PolyLite ASA, calibrated (flow 0.93, shrink 99.46 %, PA 0.034), AMS slot 3
- Process: layer_height 0.2, wall_loops 5, top_shell_layers 6, sparse_infill_density 40%, sparse_infill_pattern gyroid, support_type normal(auto), support_style snug, support_on_build_plate_only 0, support_object_xy_distance 0.35, brim_width 5
- Filament: filament_flow_ratio 0.93, filament_shrink 99.46%, pressure_advance 0.034, nozzle_temperature 260, hot_plate_temp 100
- Estimate: 2h 40m 17s; 43.88 g; 504 layers; 76.4 mm tall; toolpath audit passed.
- Parts: splice-plate (4b78d2bde9d6), center-contact (dab7afcac663), gap-trim (fa7e352fa99a), front-frame-L-pin (fc529f9df46d), front-frame-R-pin (fc529f9df46d), rear-frame-L-pin (fc529f9df46d), rear-frame-R-pin (fc529f9df46d), align-aid-front (f4d05babd297), align-aid-top (f99404108ae4), align-aid-fan (8cf8430e70b6)
- Notes: Restart after the user cancelled the first attempt at layer 1. Same file and slot. Stopped by the user at the start to change a silicone sock. Resubmitted as P-0012.

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

- When 2026-09-19 13:12; status failed; job 61d8ebc286b44a16a6eb10a40b109111; file D9-P5-17-splice-plate-contact-ASA.gcode.3mf; AMS physical slot 3; repo commit 302606f.
- Profiles: Repro - ASA - Polymaker PolyLite - Calibrated; process Repro Normal - 0.4 nozzle; Polymaker PolyLite ASA, calibrated (flow 0.93, shrink 99.46 %, PA 0.034), AMS slot 3
- Process: layer_height 0.2, wall_loops 5, top_shell_layers 6, sparse_infill_density 40%, sparse_infill_pattern gyroid, support_type normal(auto), support_style snug, support_on_build_plate_only 0, support_object_xy_distance 0.35, brim_width 5
- Filament: filament_flow_ratio 0.93, filament_shrink 99.46%, pressure_advance 0.034, nozzle_temperature 260, hot_plate_temp 100
- Estimate: 2h 40m 17s; 43.88 g; 504 layers; 76.4 mm tall; toolpath audit passed.
- Parts: splice-plate (4b78d2bde9d6), center-contact (dab7afcac663), gap-trim (fa7e352fa99a), front-frame-L-pin (fc529f9df46d), front-frame-R-pin (fc529f9df46d), rear-frame-L-pin (fc529f9df46d), rear-frame-R-pin (fc529f9df46d), align-aid-front (f4d05babd297), align-aid-top (f99404108ae4), align-aid-fan (8cf8430e70b6)
- Notes: Submitted into FINISH after plate 15. First articles of the splice plate (standing print, rear tongue), the merged seat-and-fence contact, the L trim and the glue-up keys; the four frame-end pins replace the too-tight 8.2 mm trial. Bed clear confirmed by the user. Cancelled by the user at layer 1; the bridge recorded printer_error. Resubmitted as P-0011.

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

- When 2026-09-19 06:41; status printed; job 1556c722df0b44de8289231317fcfa9a; file D9-P5-15-M1-guard-ties-ASA.gcode.3mf; AMS physical slot 3; repo commit 9a8410f.
- Profiles: Repro - ASA - Polymaker PolyLite - Calibrated; process Repro Normal - 0.4 nozzle; Polymaker PolyLite ASA, calibrated (flow 0.93, shrink 99.46 %, PA 0.034), AMS slot 3
- Process: layer_height 0.2, wall_loops 5, top_shell_layers 6, sparse_infill_density 40%, sparse_infill_pattern gyroid, support_type normal(auto), support_style snug, support_on_build_plate_only 0, support_object_xy_distance 0.35, brim_width 5
- Filament: filament_flow_ratio 0.93, filament_shrink 99.46%, pressure_advance 0.034, nozzle_temperature 260, hot_plate_temp 100
- Estimate: 7h 52m 29s; 141.52 g; 100 layers; 16.0 mm tall; toolpath audit passed.
- Parts: M1-fan-guard (6ac137d69478), front-tie-L (8ff49336782f), front-tie-R (460a16da9593), rear-tie-L (5f493fbd40b8), rear-tie-R (d3c141ca15fd)
- Notes: Submitted into FINISH after the overnight plate; identical ASA in slots 3 and 4 for auto-refill. Ties carry the 12.7 mm tongue; guard has the bonus M4 holes.
- Lessons: Finished about 13:10 on 19 September (7 h 52 m estimate). Guard has the M4 pilots; ties carry the 12.7 mm tongue. Inspect: tongue nests flush, key windows, guard standoffs.

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

- When 2026-09-18 16:58; status printed; job 1cb99fd5; file D9-P5-10-inner-pair-pegs-ASA.gcode.3mf; AMS physical slot 3; repo commit 6cc690c.
- Profiles: Repro - ASA - Polymaker PolyLite - Calibrated; process Repro Normal - 0.4 nozzle; Polymaker PolyLite ASA, calibrated (flow 0.93, shrink 99.46 %, PA 0.034), AMS slot 3
- Process: layer_height 0.2, wall_loops 5, top_shell_layers 6, sparse_infill_density 40%, sparse_infill_pattern gyroid, support_type normal(auto), support_style snug, support_on_build_plate_only 0, support_object_xy_distance 0.35, brim_width 5
- Filament: filament_flow_ratio 0.93, filament_shrink 99.46%, pressure_advance 0.034, nozzle_temperature 260, hot_plate_temp 100
- Estimate: 14h 33m 48s; 326.58 g; 990 layers; 91.8 mm tall; toolpath audit passed.
- Parts: M1-fence-peg (bdc102d6c48c), M2-fence-peg (5cd84efe43b1), M1-seat-peg (0aed55942890), M2-seat-peg (8d2c053555c7), M1-insert-pin (fc300ddeb418), M2-insert-pin (fc300ddeb418), front-frame-L-pin (e515c5742f37), front-frame-R-pin (e515c5742f37), rear-frame-L-pin (e515c5742f37), rear-frame-R-pin (e515c5742f37), front-frame-L-key (3905db7246ec), front-frame-R-key (3905db7246ec), rear-frame-L-key (3905db7246ec), rear-frame-R-key (3905db7246ec), M1-inner-shell (34fdd0866440), M2-inner-shell (0583ada73437)
- Notes: Submitted straight into FINISH; printer went IDLE then RUNNING within 30 s. Pegs, pins and keys at the plate's 40 % gyroid rather than 100 %. Round-shaft trial on the four frame-end pins. Predates the fan-screw pilots and the gussets.
- Lessons: Finished about 06:40 on 19 September, an hour under the estimate. Inspect: seat/fence peg fit in the M1 cradle, round-shaft frame pins in their 8.4 mm bores, key retention. Fit check 19 Sept: the round 8.2 mm frame-end pins (the trial) would not enter the printed 8.4 mm bores in the plenum; the octagonal pins were the loose ones on P2. Decision: one pin type, round 7.9 mm (0.5 mm diametral); reprint pins from plate 07.

## P-0007 · D9 P5 plate 01, M1 outer cradle (calibrated PolyLite ASA)

- When 2026-09-18 08:08; status printed; job 059ef858; file D9-P5-01-M1-outer-cradle-ASA.gcode.3mf; AMS physical slot 3; repo commit 4834be6.
- Profiles: Repro - ASA - Polymaker PolyLite - Calibrated; process Repro Normal - 0.4 nozzle; Polymaker PolyLite ASA, calibrated (flow 0.93, shrink 99.46 %, PA 0.034), AMS slot 3
- Process: layer_height 0.2, wall_loops 5, top_shell_layers 6, sparse_infill_density 40%, sparse_infill_pattern gyroid, support_type normal(auto), support_style snug, support_on_build_plate_only 0, support_object_xy_distance 0.35, brim_width 5
- Filament: filament_flow_ratio 0.93, filament_shrink 99.46%, pressure_advance 0.034, nozzle_temperature 260, hot_plate_temp 100
- Estimate: 9h 36m 19s; 170.35 g; 548 layers; 74.4 mm tall; toolpath audit passed.
- Parts: M1-outer-cradle-shell (1d11da52c6cd)
- Notes: Resubmitted after the watchdog fix. Finished about 16:20. Snug normal supports, 5 walls, 40 % gyroid. The bridge job row still reads "preparing": its JobRun died in the watchdog-fix restart and was re-attached as started_at.recovered; the printer completed the part.
- Lessons: Part came out nice; supports were acceptable to remove. Predates the fan-screw pilots (drill by hand with the guard as jig) and the socket-boss gussets.

## P-0006 · D9 P5 plate 01, M1 outer cradle (calibrated PolyLite ASA), first attempt

- When 2026-09-18 07:50; status failed; job 405f9ec4; file D9-P5-01-M1-outer-cradle-ASA.gcode.3mf; AMS physical slot 3; repo commit 4834be6.
- Profiles: Repro - ASA - Polymaker PolyLite - Calibrated; process Repro Normal - 0.4 nozzle; Polymaker PolyLite ASA, calibrated (flow 0.93, shrink 99.46 %, PA 0.034), AMS slot 3
- Process: layer_height 0.2, wall_loops 5, top_shell_layers 6, sparse_infill_density 40%, sparse_infill_pattern gyroid, support_type normal(auto), support_style snug, support_on_build_plate_only 0, support_object_xy_distance 0.35, brim_width 5
- Filament: filament_flow_ratio 0.93, filament_shrink 99.46%, pressure_advance 0.034, nozzle_temperature 260, hot_plate_temp 100
- Estimate: 9h 36m 19s; 170.35 g; 548 layers; 74.4 mm tall; toolpath audit passed.
- Parts: M1-outer-cradle-shell (1d11da52c6cd)
- Notes: Killed by the bridge watchdog (FED_NO_PROGRESS, 600 s) during the 100 C bed preheat before any layer printed.
- Lessons: Bridge feed deadline raised to 1800 s (BRIDGE_FEED_DEADLINE_S), PR #28, deployed on pve the same morning.

## P-0005 · D9 P5 plate 02, M1 inner plenum (PETG grey)

- When 2026-09-18 07:22; status not-started; job ede6ad47; file D9-P5-02-M1-inner-plenum.gcode.3mf; AMS physical slot 2; repo commit 4834be6.
- Profiles: Repro Generic PETG - 0.4 nozzle - Starter; process Repro Normal - 0.4 nozzle
- Process: layer_height 0.2, wall_loops 5, top_shell_layers 6, sparse_infill_density 40%, sparse_infill_pattern gyroid, support_type normal(auto), support_style snug, support_on_build_plate_only 0, support_object_xy_distance 0.35, brim_width 5
- Filament: filament_flow_ratio 0.95, filament_shrink 100%, nozzle_temperature 255, hot_plate_temp 70
- Estimate: 6h 35m 37s; 188.94 g; 725 layers; 91.8 mm tall; toolpath audit passed.
- Parts: M1-inner-shell (34fdd0866440)
- Notes: Bridge accepted the job but the printer refused the start with BBSTART_NOT_IDLE while showing FINISH from the R4-C plate. Dismissed on screen; plate 02 was not printed in PETG.
- Lessons: Consecutive jobs normally submit straight into FINISH; this refusal was a one-off. If it recurs, dismiss on the screen and resubmit.

## P-0004 · R4-C bracket pair + D9 P2 fastener fit parts (PETG grey, 8 h plate)

- When 2026-09-17 22:11; status printed; job 9c88a11e; file OPEN-ME.gcode.3mf; AMS physical slot 2; repo commit 30998a6.
- Profiles: Repro Generic PETG - 0.4 nozzle - Starter; process Repro Normal 15 grid - 0.4 nozzle
- Process: layer_height 0.2, wall_loops 4, top_shell_layers 5, sparse_infill_density 15%, sparse_infill_pattern grid, support_type normal(auto), support_style tree_slim, support_on_build_plate_only 0, support_object_xy_distance 0.35, brim_width 5
- Filament: filament_flow_ratio 0.95, filament_shrink 100%, nozzle_temperature 255, hot_plate_temp 70
- Estimate: 6h 59m 10s; 217.3 g; 298 layers; 38.0 mm tall; toolpath audit passed.
- Parts: D8-R4-C-quick-fit-bracket-print-TWO (76cd2acca0a5), D8-R4-C-quick-fit-bracket-print-TWO-2 (76cd2acca0a5), fan-socket-fit-fixture (8ff048783540), side-socket-fit-fixture (5bb130ef78d6), T-joint-fit-L (561c060bed9f), T-joint-fit-R (ac9eaaeb9872), M1-fan-1-pin (fc300ddeb418), M1-fan-3-pin (fc300ddeb418), front-lap-pin (42d48155efdb), M1-fan-1-key (82f5a4d12c23), M1-fan-3-key (7a9efd6c3943), front-lap-key (82f5a4d12c23)
- Notes: Two beefed-up R4-C brackets plus the P2 fit fixtures, three pins and keys.
- Lessons: Brackets seat the laptop well (cradle is great). Octagonal pins rattle in the 8.8 mm bores (0.6 mm diametral at corners): bores to 8.4 mm. Key barbs need 1 mm more total interference (0.8 to 1.8 mm). T tongue looked 0.6 mm proud but it was stuck support debris; the cleaned pair nests flush.

## P-0003 · V5 rail +3.5 mm fit coupons A/B/C (PETG grey)

- When 2026-09-17 20:06; status printed; job 0eec266d; file Precision_5680_V5_Rail_Plus_3p5mm_Fit_Coupons.gcode.3mf; AMS physical slot 2; repo commit f442cc2.
- Profiles: Repro Generic PETG - 0.4 nozzle - Starter; process Repro Normal - 0.4 nozzle
- Process: layer_height 0.2, wall_loops 4, top_shell_layers 5, sparse_infill_density 20%, sparse_infill_pattern gyroid, support_type normal(auto), support_style tree_slim, support_on_build_plate_only 0, support_object_xy_distance 0.35, brim_width 5
- Filament: filament_flow_ratio 0.95, filament_shrink 100%, nozzle_temperature 255, hot_plate_temp 70
- Estimate: 1h 52m 33s; 48.18 g; 120 layers; 24.0 mm tall; toolpath audit passed.
- Parts: A_R1_full_rail_plus_3p5mm_X_to_print_Z (c3fbe9c04abd), B_R2_full_rail_plus_3p5mm_X_to_print_Z (dad7d63de9b7), C_R2_full_rail_plus_3p5mm_plus_1mm_seat_relief_X_to_print_Z (0e5512bfb011)
- Notes: Lid rail moved 3.5 mm away from seat and fence after the V4 trio all bound.
- Lessons: C (R2 seat + 1 mm relief) seated best: 3 dots wins. Rail offset confirmed at 3.5 mm.

## P-0002 · V4 full-rail fit coupons A/B/C (PETG grey)

- When 2026-09-17 18:41; status printed; job 0d353e7416234f1498326c701b233e2a; file Precision_5680_V4_Full_Rail_Fit_Coupons_V4 FULL RAIL A B C FIT COUPONS - ONE EACH; AMS physical slot 2; repo commit 3e8792b.
- Profiles: Repro Generic PETG - 0.4 nozzle - Starter; process Repro Normal - 0.4 nozzle
- Process: layer_height 0.2, wall_loops 4, top_shell_layers 5, sparse_infill_density 20%, sparse_infill_pattern gyroid, support_type normal(auto), support_style tree_slim, support_on_build_plate_only 0, support_object_xy_distance 0.35, brim_width 5
- Filament: filament_flow_ratio 0.95, filament_shrink 100%, nozzle_temperature 255, hot_plate_temp 70
- Estimate: 1h 50m 46s; 47.02 g; 120 layers; 24.0 mm tall; toolpath audit passed.
- Actual duration: 0 h 57 min.
- Parts: A_R1_full_native_rail_X_to_print_Z (11bb78ab79a1), B_R2_full_native_rail_X_to_print_Z (a2ec03ec6196), C_R2_full_rail_plus_1mm_seat_relief_X_to_print_Z (eb23e9dbe01a)
- Notes: Recovered from the bridge job list (57 min actual).
- Lessons: All three V4 sizers bound: the tall lid-stop wall sat too close to the seat and fence. Fixed by moving the rail 3.5 mm outward in V5 (P-0003, the V5 coupons).

## P-0001 · D8 quick-fit bracket pair, pre-R4 revision (PETG)

- When 2026-09-16 18:44; status printed; job b8c11d5e2216487ba26385df0b79d6fa; file D8-quick-fit-bracket-print-TWO_plate_1; AMS physical slot ?; repo commit 502a85e.
- Actual duration: 2 h 36 min.
- Notes: Pre-session print recovered from the bridge job list (2 h 36 m actual). Exact bracket revision not recorded; the D8 quick-fit R1/R2 sources are in desk-dock/D8/quick-fit.
- Lessons: Seat and fence needed the V-series coupons to converge; superseded by the R4-C pair (P-0004, the R4-C plate).

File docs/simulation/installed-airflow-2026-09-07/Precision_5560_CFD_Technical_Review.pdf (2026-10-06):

PRECISION 5560 / WALL-MOUNT COOLING

# Installed airflow / system overview

Parallel-projection flow views | Actual reconstructed solution | Four idealized fan actuators

SIMULATION TECHNICAL REVIEW

REV A | 07 SEP 2026 | A3 LANDSCAPE

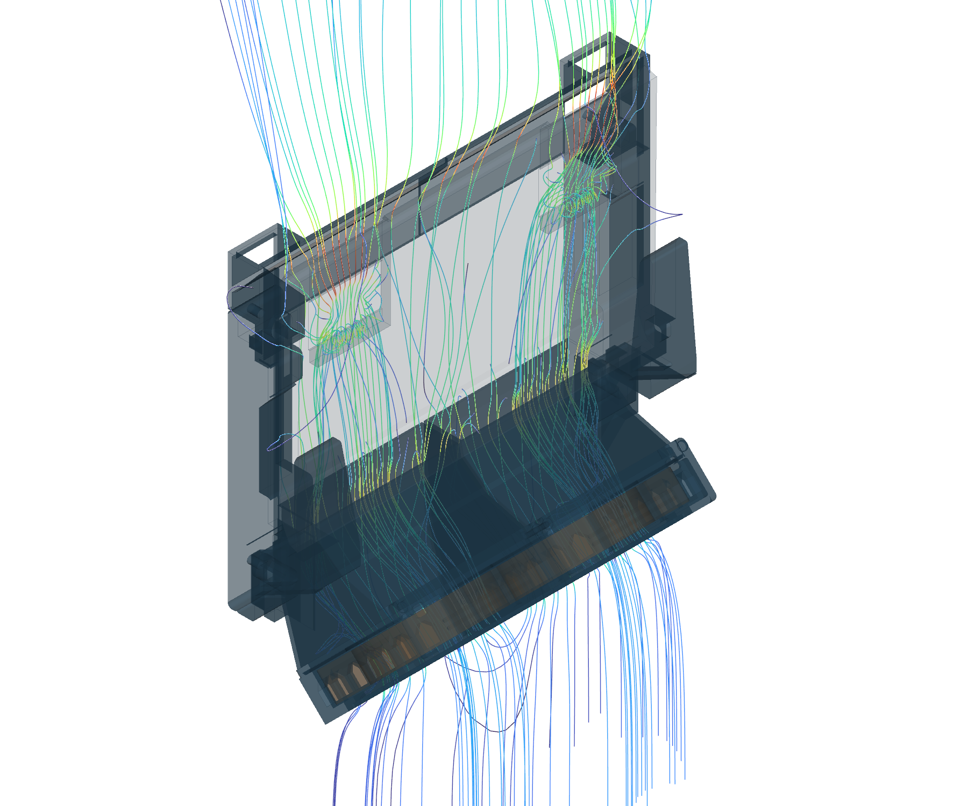
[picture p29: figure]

D5560-CFD-001

CASE: installed_pressure10_v3

EXPLORATORY / NOT CONVERGED

Airflow only. Assumed fan forcing. Not a manufacturing release.

UNITS: mm, m/s, Pa | VIEWS: NTS
Saved solution: iteration 1200 | 836,278 cells

01 / 07

0 | Speed [m/s] | 5

### 01 / MODEL SCOPE

### Native mount assembly, traced laptop envelope, twin intake windows, internal surrogate ducts and two

external fan housings.

### 02 / OPERATING ASSUMPTION

### Four constant-force actuators, each based on nominal 10 Pa pressure rise. No manufacturer fan

curve or measured grille / fin resistance.

3.52 / 3.55

Left / right sampled intake flow [CFM]
4.93

Maximum cell speed [m/s]

### 03 / REVIEW STATUS

### The run reached its 1200-iteration limit. Integral intake flows changed less than 0.7% from iteration

400; residual convergence was not achieved.

Streamlines show selected seeded paths, not total airflow allocation. Paths are clipped by the view frame.

# Geometry / orthographic reference

A | VIEW FROM +Y / LOOKING -Y | B | VIEW FROM +X / LOOKING -X

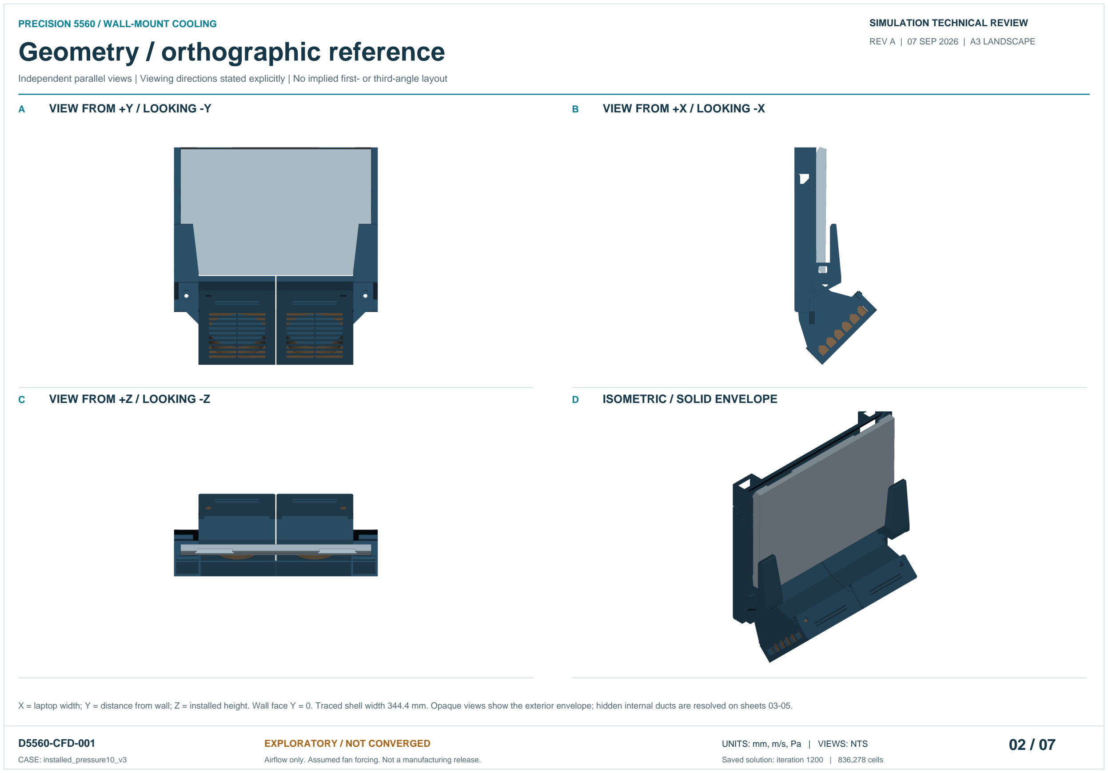
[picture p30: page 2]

Independent parallel views | Viewing directions stated explicitly | No implied first- or third-angle layout

02 / 07

C | VIEW FROM +Z / LOOKING -Z | D | ISOMETRIC / SOLID ENVELOPE

X = laptop width; Y = distance from wall; Z = installed height. Wall face Y = 0. Traced shell width 344.4 mm. Opaque views show the exterior envelope; hidden internal ducts are resolved on sheets 03-05.

# Longitudinal sections / fan-to-laptop path

A-A: X = -111.017 mm | B-B: X = +111.264 mm | Scalar: speed | Equal axis scaling

03 / 07

A-A LEFT FAN / DUCT CENTRE | B-B RIGHT FAN / DUCT CENTRE

### SECTION REGISTER

A

A

B

B

344.4 mm

X-Z locator / schematic, +X to right

### READING THE SECTIONS

The external fans sit below the laptop. The narrow cavity within the shell connects the active intake window to the hinge outlet. White areas indicate solid geometry or invalid samples.

### GEOMETRY CONFIDENCE

Envelope traced from the project reference: approximately +/-2 mm. Intake locations: approximately +/-4 mm. Internal ducts and fan placement are engineering surrogates.

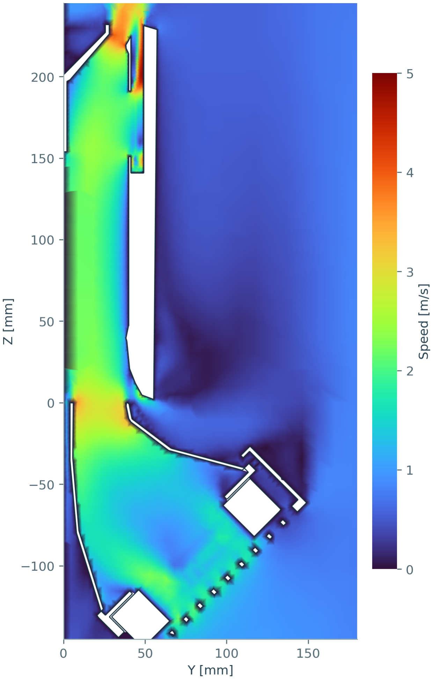
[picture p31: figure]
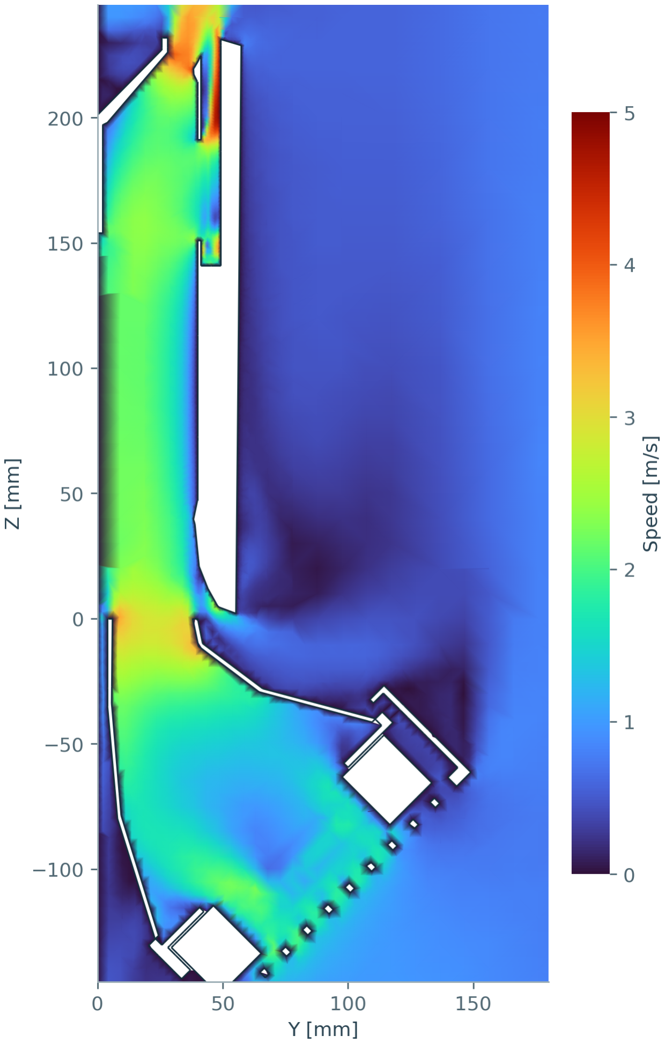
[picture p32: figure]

Dark lines: intersection of CAD-derived surfaces with the section plane. Color field: interpolated velocity on cut cells; 0-5 m/s on all speed sheets.

# Internal duct plane / velocity and pressure

C-C: Y = 45.000 mm | Plane passes through both simulated internal fan regions

04 / 07

### 01 SPEED MAGNITUDE

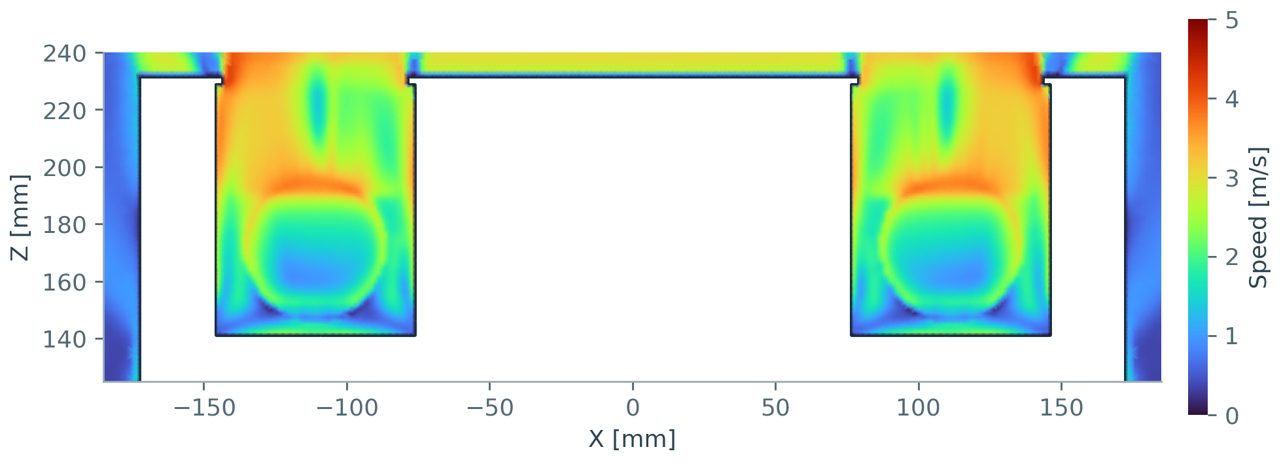
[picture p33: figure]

### 02 GAUGE PRESSURE

### PLANE LOCATION

### Y is measured outward from the wall. The assumed duct spans Y = 41.2 to 49.2 mm; this section lies inside its 8

mm depth.

### PRESSURE CONVENTION

### OpenFOAM stores kinematic pressure. The plotted

gauge pressure is p multiplied by rho = 1.2 kg/m3, referenced to the zero-pressure ambient boundary.

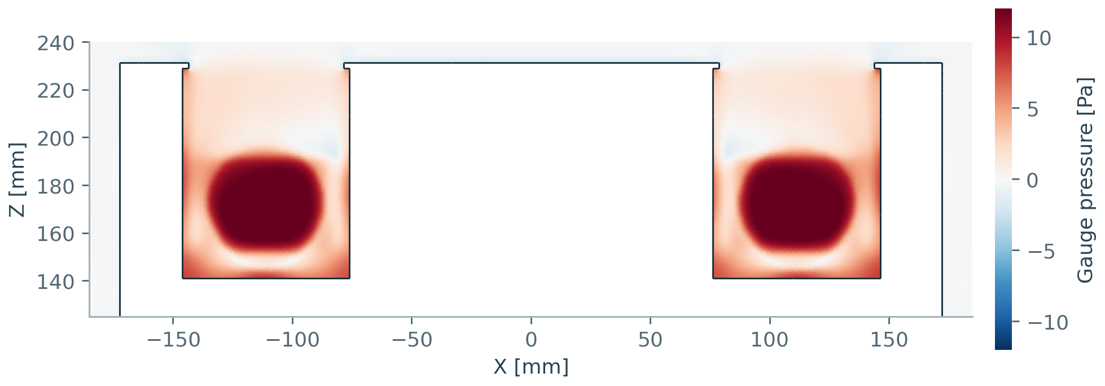
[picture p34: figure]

### INTERPRETATION

### The two isolated colored passages are the modeled internal ducts. The white central region is solid laptop

surrogate. The color maps are not temperature fields.

### DISPLAY LIMITS

Speed: 0 to 5 m/s. Pressure: -12 to +12 Pa, with saturation outside this range. Cells VTK cannot contour are omitted; gaps are not filled.

# Transverse intake section / reverse perspective

D-D: Z = 171.119 mm | Intake-centre section with rear-side streamline context

05 / 07

### D-D HORIZONTAL SECTION THROUGH ACTIVE INTAKES

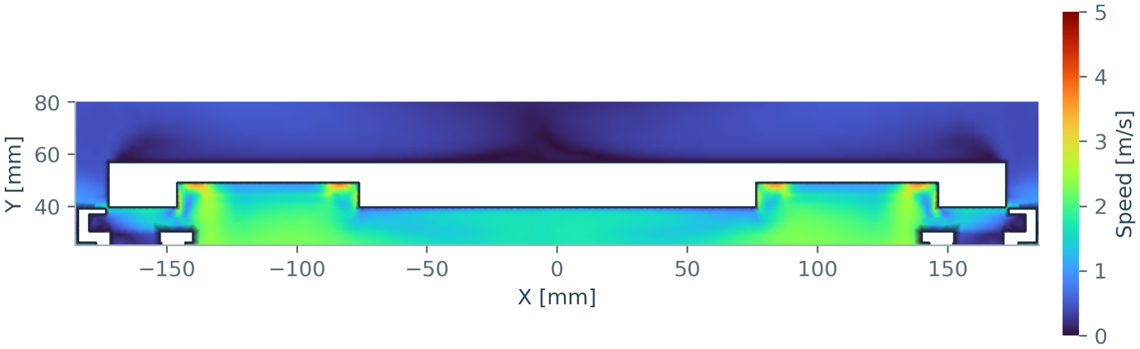
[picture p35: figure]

### 01 REVERSE OBLIQUE / FLOW CONTEXT FLOW SAMPLES AT THE INTAKES

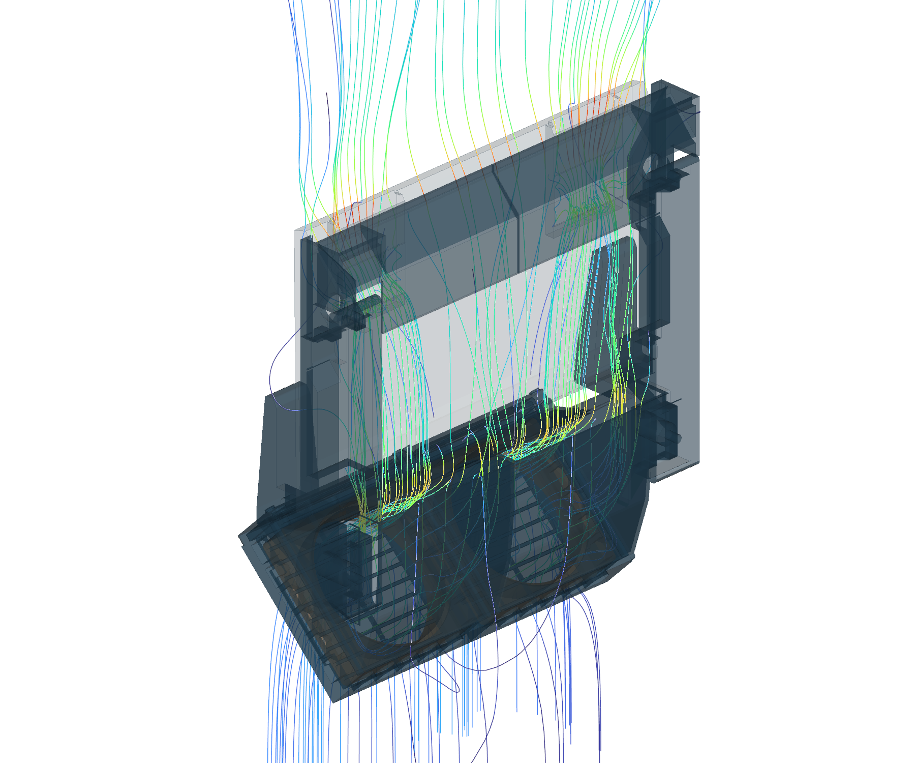
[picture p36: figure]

Rectangle quadrature at Y = 40.5 mm, with positive flow into the laptop. All quadrature points were valid at both intakes.

Location | Iteration 400 | Iteration 1200
Left intake | 3.498 CFM | 3.520 CFM
Right intake | 3.522 CFM | 3.546 CFM

Less than 0.7% change in these integral quantities. This is local stability evidence; it does not establish complete field convergence or real fan performance.

# Mesh resolution / local section details

Actual cut mesh over the speed field | Display triangulation includes diagonals added for rendering

06 / 07

01 | EXTERNAL FAN / DUCT REGION | 02 | INTERNAL DUCT / INTAKE DETAIL

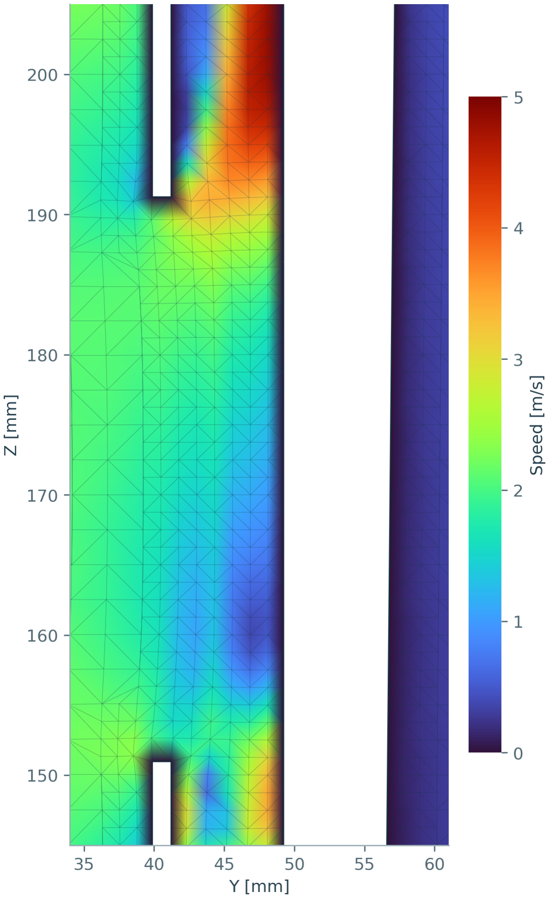
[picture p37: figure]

### MESH INVENTORY

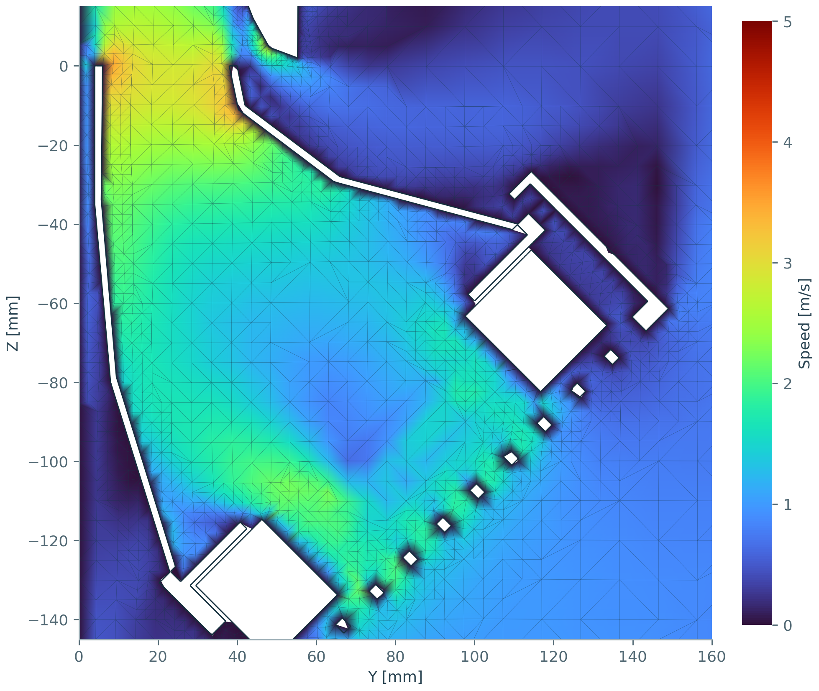
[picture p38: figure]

Cells
836,278

Fluid regions
1

Maximum skewness
2.496

Max non-orthogonality

## 64.69 deg

Minimum determinant
0.000683

### QUALITY DISPOSITION

Standard checkMesh: Mesh OK. Expanded diagnostics flag one low-determinant cell plus concave cells and warped faces. The surface is closed and passed the self-intersection check.

No prism layers; mesh independence and wall resolution are unverified. Cell faces in the fluid mesh are polyhedral; shown triangles are section-rendering subdivisions.

Numerical fan thickness: the external actuator zones were broadened from 2 to 10 mm while preserving total force, selecting 2033 / 2032 cells. Internal Dell zones contain 2438 / 2443 cells. Marker bodies are not obstacles. This is a coarse exploratory mesh, not a released validation mesh.

# Convergence / evidence and assumptions

First initial residual per field and SIMPLE iteration | Saved result: 1200 | Elapsed solver time: 1166 s

07 / 07

### FINAL INITIAL RESIDUALS

Ux | 4.797e-05
Uy | 6.977e-05
Uz | 6.449e-05
p | 2.955e-05
k | 1.974e-04
omega | 5.490e-06

Iteration limit reached.
The 1e-5 residual target was not met.

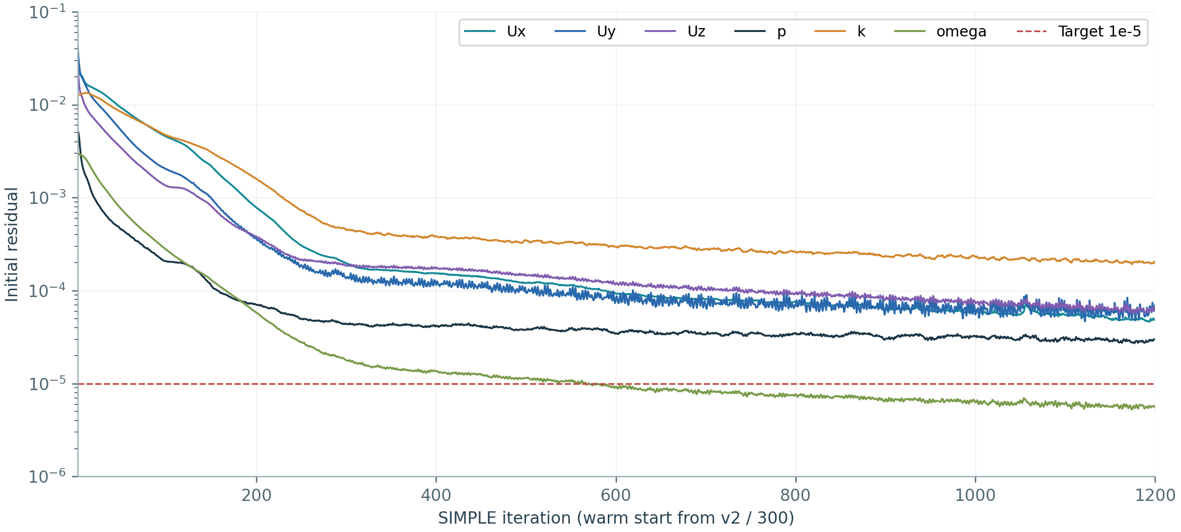
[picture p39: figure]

### METHOD / PHYSICS

Steady incompressible SIMPLE; k-omega SST; first-order bounded-upwind momentum. Density 1.2 kg/m3; kinematic viscosity 1.5e-5 m2/s. No-slip walls and zero-gauge-pressure ambient openings.

No thermal transport, CPU heat load, fan P/Q curves, grille porosity or fin-stack resistance. Intake values are uncalibrated model outputs.

### MODEL / PROVENANCE

BARAM bundled OpenFOAM v2412, build 6467f461-20260821; Microsoft MPI, eight workers. Warm start from v2 iteration 300.

Source geometry: native mount assembly and traced CFD helper. Profile and intake reconstruction: project profile_reconstruction.json. Final field reconstruction completed normally.

### SOURCE FILES / REPRODUCTION

Case: installed_pressure10_v3
Fields: 1200/ and constant/polyMesh/
Log: log.simpleFoam_windows
Samples: results/iteration_1200/flow_samples.json Views: drawing_assets.py
Layout: build_drawing_package.py

The companion manifest records source hashes, cut planes, units and the PDF digest.

Prepared for engineering review. Figures are rendered simulation views, not certified fabrication drawings.

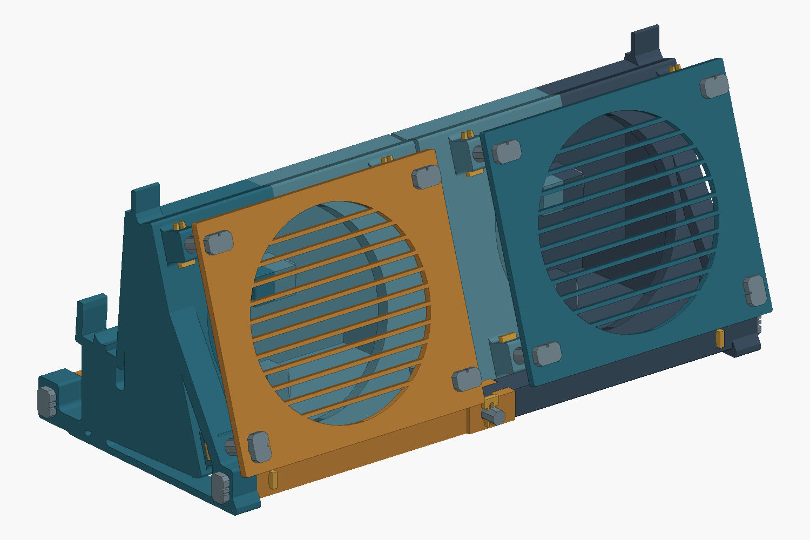
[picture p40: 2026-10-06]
docs/printables/d9-p3/D9-P3-assembly.png

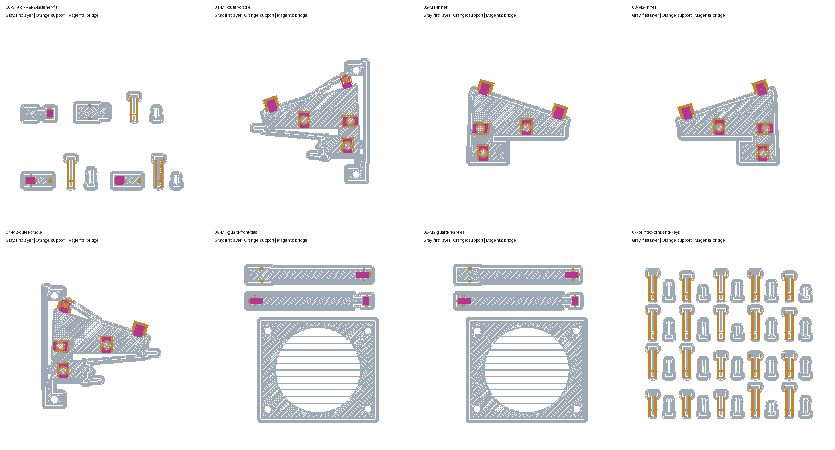
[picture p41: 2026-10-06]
docs/printables/d9-p2/D9-actual-toolpath-review.png

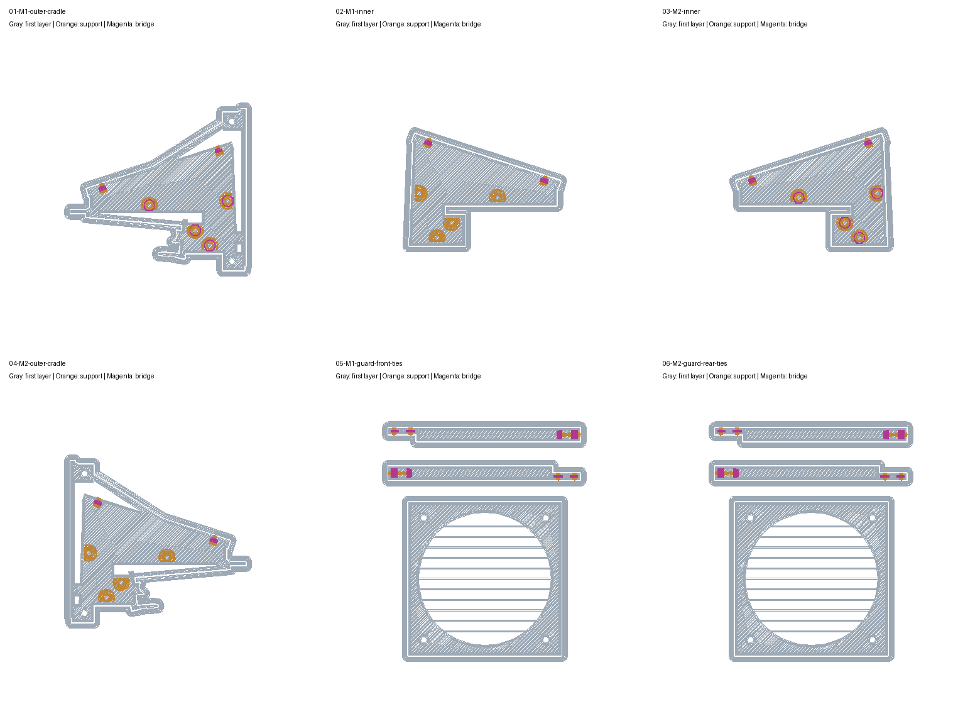
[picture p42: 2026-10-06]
docs/printables/d9-p1/D9-actual-toolpath-review.png

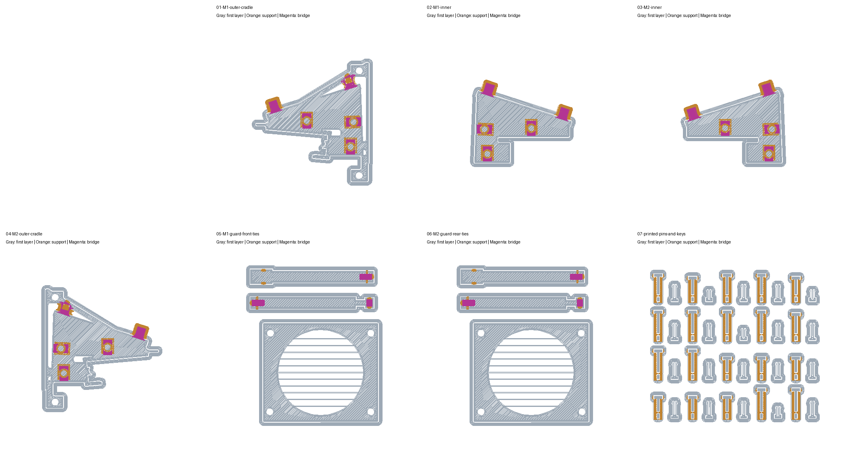
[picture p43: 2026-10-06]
docs/printables/d9-p3/D9-actual-toolpath-review.png

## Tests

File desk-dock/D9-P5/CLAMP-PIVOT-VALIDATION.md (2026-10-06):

# Large-shaft clamp pivot — CAD validation, 21 September 2026 (compact revision + carrier bearing land)

Branch `feat/carrier-bearing-land`, on top of the compact revision merged in PR #17. Everything below is CAD, slicer and mesh
evidence. Nothing was printed; no fit, torque, backlash or stiffness was measured.

## What was found before anything was changed

The polar plug positioner on `main` could not reach the laptop's USB-C port. The
port datum every earlier revision (D1–D7) uses, `rear_case_seat_z +
port_from_rear_case` at `port_y`, carried through the builder's own −8° lean,
puts port 1 at (y 11.39, z 119.03) — 59.4 mm from the old pivot at (45, 70) — and
port 2 at 72.2 mm. The tip pivot ran 108–148 mm from that pivot, the rotor pad
sat at x ≈ −60 for a 25-mm plug at x ≤ 0, and the first Ø100 draft's skirt cone
passed straight through the port-1 axis. None of the five validation scripts
referenced the port datum. `audit/port-reach.png` and `audit/plug-end-views.png`
are the renders that exposed it.

## What is on the branch

| item | value |
| --- | --- |
| pivot axis | (y 70, z 70), 25 mm lidward of the socket centre |
| shaft | Ø50 hollow (Ø30 bore); smooth journal x −63..−40 (23 mm) |
| thread | 47 × 3 mm, D8 trapezoidal, core 44.7, depth 1.15, crest 0.45; 0.35 radial / 0.15 axial clearance; x −75.5..−63 |
| stack (outboard is −X) | shoulder face −40 (plate 10 mm, Ø70) · arm disc −50..−40 (Ø70, bore 50.5) · cam spatula −60..−50 (10 mm) · keyed washer −62.5..−60 (Ø75) · knurled nut −71.5..−62.5 (Ø72, 16 flutes, 3 turns engaged, 4 mm spare thread) |
| nut lands | 0.5 mm inboard of the thread start; journal 0.5 mm longer than the clamped stack; nut face 71.5 mm outboard of the shoulder-side cradle face (was 101) |
| shoulder | socket stem + 6.5-mm bridge, 3-mm skirt Ø70→Ø80 with twelve 50° ribs, Ø80 backing ring on the cradle face; plate, skirt, ring and ribs cut clear of the bonded receiver; 144 cm³, 80 × 83 × 85 (was 274 cm³, 130 × 130 × 97) |
| arm | Ø70 × 10 disc; tongue 10 mm at the root, 20 mm deep from r 37.5; 25.6-mm sleeve, two length clamps 15 mm apart; tip 103.5–125.5 mm (22 mm travel); Ø12 hollow tip screw in a Ø28 clevis with 3-mm cheeks, r 13 eye |
| carrier | 18-mm eye/bar/plate; carrier block built in the plug frame (faces square to the plug, pre-rolled to the mean working angle plus the lean) from the cam face (x −49.9) to x −5; 14 × 13 mm window; walls 12 mm (thin, pivot side), 10 mm (screw side), 5 mm above and an **18-mm bearing land below** the window, so the back face bears on the lobe over 375 mm² at port 1 and 404 mm² at port 2 (5-mm walls gave 46 / 75 mm²); long edges rounded r 3.5, front face chamfered 1.5, window mouth flared 1.5 mm at 45°, back (bed, bearing) face square; the overmold is clamped **on its 6.5-mm flats** over x −17.5..−5 between the thin wall and a loose flat 7 × 11.5 mm bearing shim; M8 × 3 pinch screw (16-mm shank, flat tip seated in a Ø8.6 recess on the shim) through the 10-mm wall into a captured scalloped nut; r 4.7 relief behind the clamp zone for boots to Ø9. Clamped overmold axis (0.25 mm off the thin wall) is the reach target; window centre offset 3.5 mm |
| cam spatula | 10 mm; hub r 15–35; leaf lobe ≈ 50° of arc: radial near edge at 3°, spiral r = 58·e^(1.2θ) to 24° (r 96), spline tip and back edge; edge set 0.5 mm inside the window's nearest corner, lobe runs past the carrier |
| port 1 pose | arm 22.5°, tip r 107.6 (3.1 / 18.9 mm to the travel limits), rotor trim −1.9°, cam +44.4°, edge r 69.6 |
| port 2 pose | arm 18.7°, tip r 121.8 (17.3 / 4.7 mm), rotor trim +2.0°, cam +28.2°, edge r 78.7 |
| loosened sweep | −120° … +39° clear (3° steps), arm, carrier, pinch hardware and spatula moving together, against dock, laptop and desk |
| printed parts | 50 (48 on main − clevis/screw/nut/2 washers + shoulder, nut, keyed washer, spatula, pinch screw, pinch nut, shim) |
| plates | 12: 00 fit/alternates (4 h 40 m), 01–09 as before (08 socket + arms + carrier 6 h 37 m / 157 g (was 5 h 28 m / 142 g before the bearing land), 09 rings + hardware 3 h 27 m / 67 g), 10 shoulder 6 h 17 m / 144 g, 11 spatula + tip washers + shim 1 h 37 m / 35 g; all Orca toolpath audits pass |
| viewer | 53 entries (50 printed + laptop + two fans), 651,576 bytes, revision `D9-P5-CARRIER-BEARING-LAND`, cache key `clamp-20260921c`; offsets, index ranges and coverage validated by `validate_viewer_bundle.py` |

## Checks that run every build

- Port reach: solves the arm angle and reach that put the clamped plug axis on each
  port with the rotor trimmed so the window is square to the port (the trim rotates
  the window about the tip, so it is part of the solve); the window pre-roll is
  iterated to the mean working angle. Fails the build if either port is outside the
  travel. Both ports sit 3–4 mm from a travel limit — usable, but the slot could
  gain a few mm each way.
- Lobe bearing area: at each solved pose the cam is pushed 0.3 mm into the carrier and the
  overlap volume / 0.3 is reported as `lobe_bearing_area_mm2` (375 / 404 mm²). Reported, not
  asserted.
- Port-pose clearance: swings the arm and rotates the cam to each solved pose and
  intersects every moving part with every fixed part, the laptop and the desk, and
  with each other; passes a plug + boot + cable envelope through the port and the
  cam plate's band, and now against every moving part as well (this is what caught the
  shim sitting on the boot before the clamped-boot datum was introduced). Both poses:
  zero conflicts.
- Static interference (zero), insertion motion (zero), laptop and fan overlap
  (zero), watertight single-solid meshes, tessellation and bed size.
- First-order plug-axis compliance under 20 N, reported (not asserted), now including
  the shoulder plate + bridge as a cantilever over the 25-mm pivot offset in both
  directions: docking push (−X), through the cam lobe and shoulder: 0.25° at E 2000 MPa,
  0.33° at 1500; withdrawal pull (+X), through the arm and shoulder: 0.39° at 2000,
  0.52° at 1500. Not included:
  socket cartridge clearance (0.3 mm per side over 39 mm, up to 0.88° unless the M12
  bolt preloads it), clamp-face slip, layer anisotropy.

## Slicing notes

- Shoulder (plate 10): 6 h 17 m, 144 g; 39.3 k support segments inside the skirt
  (ribs and the bridge/stem lip). Open through the Ø56 ring bore. Inspect support
  access in the Orca GUI before printing.
- Carrier (plate 08): 3.2 k support segments, in the nut pocket, pinch hole and boot
  relief (all horizontal), window vertical.
- Outer arm: 6.5 k, under the inboard clevis cheek across the rotor slot.
- Spatula plate 11 (1 h 37 m, 35 g): spatula no support; shim 129 segments in its recess.
- Fit coupons (plate 00): shaft stub 21.8 k, nut 4.3 k, as before under the thread crests.
- Inner arm and pressure washer: no support.

## Gate status

`verify_and_package.py` passes the manifest, insertion-motion and plate gates and
stops at the legacy enclosure audit, which fails for M1 and M2 exactly as on the
base and recovered rebuilds (see RECOVERY-VALIDATION.md). It was not altered. No
production ZIP was generated.

## Not established

Thread fit and drag (print the two full-diameter fit coupons first), clamp holding
torque, backlash after tightening, plug-axis tilt at 20 N in both directions (dial
indicator on the boot), the cam set-up by hand, lobe face contact once printed,
the socket cartridge's clearance under the 45-mm offset moment, rear-frame-L pin
extraction past the Ø100 ring, support removal inside the shoulder, and the real
cable boot against the 14 × 16 mm window.

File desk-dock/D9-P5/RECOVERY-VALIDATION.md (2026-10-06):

# Salvage verification - 20 September 2026

The supplied `5680-dock-codex-splice-fixes-salvage.zip` was recovered against
base `562aeb326c1f24a4886cca85b368fced76bc955f`. Its SHA-256 is
`6c8f1308c7a32ba4290469ed1dc1eb466ae008dacd3a096654ece5456c6a3449`.

The preferred mail patch was applied as commit
`b90d7e7206b07ca2359356338fc0e4191b615ec1`, retaining the supplied author,
author date and title. The commit ID differs from the reconstructed handoff
commit because it has a new committer timestamp. Independently applying the
binary fallback patch to the base index produced exactly the same tree:
`60fe3210691bc29638b73977fad137973ee442d1`. Later pipeline/documentation
corrections are a separate commit so the recovery itself remains inspectable.

## Rebuild results

Windows Python 3.12, CadQuery 2.8.0 and trimesh 5.1.0 completed the full build.
All 48 installed printed parts exported as valid single solids and watertight
STLs. Part interference, sampled insertion conflicts, laptop overlap and fan
interference were empty/zero. Both fan-seat gap audits were 0.0 mm3.

| Arc | Shell | Positive engagement (mm3) |
| --- | --- | ---: |
| Back | M1 | 2872.4 |
| Front | M2 | 265.2 |
| Fan | M1 | 297.6 |
| Floor | M2 | 181.3 |

Joint fill was 4923.1 of 4929.1 mm3, leaving 5.9 mm3 in the intentional key
clearances. Nominal air volumes were M1 770257.4017438883 mm3 and M2
786384.4889101831 mm3, unchanged from the base rebuild within floating-point
precision; the M1 last-digit difference from the handoff is below 1e-9 mm3.

## Viewer recovery

The published assets remain the recovered 582312-byte binary, revision
`D9-P5-CODEX-SPLICE-LAP-AND-PRINT-POSE`, with cache key `cleanup-20260920f`.
The 51 entries comprise 48 printed bodies, the laptop and two fan references.
All offsets, lengths, index ranges and binary coverage were checked.

A separate local re-export produced 581256 bytes. Its entries and bounds
match, but three parts have different coarse tessellation counts (M2 outer
cradle, accessory socket, accessory clamp bolt); some other entries differ in
vertex ordering. Both binary layouts validate. Byte-for-byte local export
reproducibility is **not claimed**. The re-export was retained separately and
did not overwrite the supplied asset or its provenance.

## Orca review candidates

Native Orca successfully sliced one optional fit/alternate plate and nine
assembly plates from the rebuilt STLs. The 48 installed parts appear exactly
once across plates 01-09. All ten actual-G-code audits passed placement,
orientation, build height, usable bed/exclusion-zone and embedded-G-code checks.
Per-object support and bridge counts are in `plates-verification.json`.
Plate 06 and 09 toolpath previews were visually inspected; this is not a
complete physical support-access or native-GUI review.

Follow-up source fixes remove obsolete plate labels/counts, use the verifier
shipped in this repository, reject any failed plate audit, reserve 12-mm
inter-part spacing and the front-left exclusion zone, and stop packaging
before creating a release directory when required gates fail.

The frozen profile is Generic PETG Starter. The soft-tip geometry included on
plate 09 requires a separate flexible-material slice for use as a soft bumper.
These slices are review candidates, not a released production print kit.

## Enclosure gate and remaining qualification

`verify_enclosure.py` fails for M1 and M2 on **both** the base rebuild and the
recovered rebuild. With both named ports capped, the test still finds the
target air connected to the exterior. Target-overlap values match between the
two revisions; this is not a newly introduced failure from the splice patch.
The legacy test evaluates two bare shell solids and no cured epoxy. It does
not establish that the bonded assembly seals, and no replacement sealing
audit or physical airtightness test has been completed.

The package verifier was run and correctly stopped at this enclosure gate.
No verified production ZIP was generated or published. Resolve and re-audit
the bonded-seam sealing model before releasing a production kit.

Physical thread fit/durability, clamp loads, socket capacity, epoxy procedure,
loaded laptop support, fan screw retention, cooling, support removal and
docking/plug alignment remain unqualified. No printer was operated.

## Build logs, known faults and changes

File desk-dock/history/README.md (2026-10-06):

# Design history and reference material

This folder preserves the recovered project discussion, the user's intended physical arrangement and simplification markups, the earlier wider D6 geometry, and two D7 snapshots before later changes. These are historical artifacts, not current print recommendations. Use `../D7/` for the current design.

The reference photo establishes a closed Precision 5680, hinge down and lid toward the user. Dell reference assets in `reference-assets` retain their original authorship; their sources and dimensional use are documented in the D6 port study. Historical scripts and snapshots may contain machine-specific paths or superseded assumptions.

`conversation.md` is the recovered project conversation, not a current specification. Current decisions and remaining verification are collected in the root `PROJECT_CONTEXT.md`.

The original 5560 wall-mount project and its Git history remain in this repository; its original README is preserved in `docs/history/5560-README.md` and its former homepage is `docs/5560-archive.html`.

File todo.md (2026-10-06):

# TODO

- [x] Redesign the plug-positioner base pivot as a large face clamp (implemented on
  `feat/large-shaft-clamp-pivot`, `desk-dock/D9-P5/build_d9.py`).
  - Shaft: hollow **Ø50 mm** (Ø30 bore), smooth journal, outboard flat-crested 47 × 3 mm
    trapezoidal thread (depth 1.15, crest 0.45, 0.35 radial / 0.15 axial clearance, 3 turns
    engaged, 4 mm spare). The brief said approximately Ø100; the Ø100 draft could not reach
    the port, Ø75 (PR #16) could, and the compact Ø50 revision is what face-friction torque,
    three thread turns and finger room actually need.
  - Arm base disc Ø70 × 10 with a Ø50.5 bore on the journal; keyed Ø75 pressure washer in
    two journal keyways; knurled Ø72 nut with sixteen flutes; nut face 71.5 mm outboard of
    the shoulder-side cradle face. Nut lands 0.5 mm inboard
    of the thread start; journal is 3 mm longer than the disc.
  - Shoulder: bridge from the socket stem, 3-mm skirt narrowing from a Ø80 backing
    ring on the cradle face to a Ø70 × 10 shoulder plate, twelve 50-degree internal ribs so
    the plate prints without support, cut clear of the bonded receiver and of the
    rear-frame-L pin's extraction path.
  - The pivot axis is offset 25 mm lidward of the socket centre, to (y 70, z 70).
  - Full-diameter fit coupons: `clamp-shaft-fit-coupon` (47-mm thread stub with both
    keyways) and `clamp-nut-fit-coupon` (the real nut), on plate 00.
- [x] **Port reach.** The polar arm on `main` could not reach either USB-C port: the
  D1–D7 port datum (`rear_case_seat_z + port_from_rear_case`, `port_y`) puts port 1
  59.4 mm from the old pivot while the tip ran 108–148 mm, and the rotor pad sat at
  x ≈ −60 for a 25-mm plug. The builder now solves the arm angle and reach for both
  ports, swings the arm there, passes a plug-and-boot envelope through the port and
  fails on any contact (`generated/port-reach.json`). Port 1: arm 22.5°, tip r 107.6 mm
  (3.1 / 18.9 mm travel margin); port 2: 18.7°, 121.8 mm (17.3 / 4.7 mm). Loosened
  sweep clear from −120° to +39° (3° steps) against dock, laptop and desk.
- [x] Plug carrier cranked to put its 14 × 13 mm window 34 mm lateral and 41 mm inboard
  of the tip; the block is built in the plug frame (rolled −28.6°, faces square to the plug),
  spans the cam face (x −49.9) to x −5, and carries a 16-mm M8 × 3 pinch screw into a
  captured scalloped nut. Walls: 12 mm thin (pivot) side, 10 mm screw side, 5 mm above the
  window and an 18-mm bearing land below it, so the back face bears on the leaf lobe over
  375 / 404 mm² at the two ports instead of the 46 / 75 mm² sliver 5-mm walls gave. Long
  edges rounded r 3.5, front face chamfered, window mouth flared; back face left square. The plug is clamped on its overmold flats between the thin wall and
  a loose flat 7 × 11.5 bearing shim (screw tip in a recess on the shim), so it cannot roll;
  the window is relieved behind for Ø9 boots. The clamped overmold axis is the reach target
  and the rotor trim is part of the reach solve.
- [x] Plates 08–11 rebuilt (12 plates, all toolpath audits pass), viewer regenerated (53
  entries, 651,576 bytes, revision `D9-P5-CARRIER-BEARING-LAND`, cache key
  `clamp-20260921c`), arm toggle still defaults off including after Reset. 50 printed parts.

- [x] **Plug-axis stiffness target: ≤ 0.5° tilt at 20 N along the plug axis** (user,
  2026-09-20). Rather than a deeper arm, a separate 10-mm leaf-lobe spatula (50° of arc, spiral
  r 58→96 to 24°, spline tip) rides the journal outboard of the arm disc, pinched by
  the same nut; it is turned until its edge runs up to the plug boot, and the carrier's back face bears on the lobe, so
  the docking push loads a clamped plate. Arm: 10-mm tongue root, 20 mm deep from r 37.5, 25.6-mm sleeve.
  Beam estimate (manifest `accessory_socket.reach.plug_axis_compliance_estimate`):
  docking push through the lobe and shoulder 0.25–0.33°, withdrawal pull through the arm
  and shoulder 0.39–0.52°; not asserted, not a measurement.

## Not yet qualified (physical)

- [ ] Print and hand-turn the shaft/nut fit coupon pair before printing the shoulder:
  thread fit, drag, whether 0.35 / 0.15 mm clearance is right for the P1S PETG profile.
- [ ] Clamp holding torque: how much nut torque the arm needs to stay put under plug
  insertion and cable pull; whether the keyed washer stops the arm creeping.
- [ ] **Plug-axis tilt at 20 N, dial indicator on the plug boot**: the acceptance test for
  the 0.5° target. The estimate excludes the socket cartridge's 0.3 mm/side clearance
  (worth up to 0.88° of rocking unless the M12 bolt preloads the stem against one face),
  clamp-face slip and layer anisotropy.
- [ ] Backlash and play at the port after tightening (journal 0.5 mm diametral, thread
  clearances). The large diameter does not remove it by itself.
- [ ] Shoulder stiffness under the plug load, and whether the Ø112 ring / socket clamp
  bolt hold the 45-mm offset without rocking.
- [ ] Rear-frame-L pin extraction past the Ø100 ring with fingers/pliers.
- [ ] Cam lobe: set-up procedure by hand (loosen, set arm, turn lobe to the boot, tighten); does the
  lobe edge actually touch the boot without pinching the cable; lobe face contact area once printed.
- [ ] Carrier clamp on a real cable: the 6.5-mm flat is the spec maximum; a thinner overmold just
  takes more screw travel. Check the boot (relief to Ø9) and that the pinch does not crush anything.
- [ ] Both ports sit 3–4 mm from a travel limit; lengthen the tongue slot a few mm each way if the
  bench setup wants more. Rotor roll trim is ~9° toward the sleeve,
  free away from it.
- [ ] Support removal inside the shoulder (through the Ø78 ring opening), in the
  rotor's pocket window and under the outer arm's inboard cheek.
- [ ] Legacy enclosure gate still fails (pre-existing, both modules); no verified
  production ZIP until the bonded-seam sealing model is replaced.

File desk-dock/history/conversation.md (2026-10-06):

# Create Desk Dock — recovered conversation

Source: https://chatgpt.com/c/6aa01f3c-ad4c-83ea-a851-1f4e3b597d39

Historical discussion for context. Linked artifacts are recovered in the repository. Unresolved ChatGPT content-reference placeholders are retained as received.

## User

go to [https://github.com/thereprocase/dell-5560-wall-mount](https://github.com/thereprocase/dell-5560-wall-mount)

ok, wildly different ask. another fork. I have a Dell 5680 I use on my desk. can you create a slide-in desk bearing dock that lets us securely mount a Dell SD25TB5 plug in the slidey laptop holder, and plop my laptop into the trough and slide it up against the TB plug and have it precisely insert into one of the two USB C side ports.

## Assistant

Created a [separate desk-dock branch with the first CAD concept](https://github.com/thereprocase/5680-dock/tree/main/desk-dock).

The design assumes **closed laptop, hinge up: lower into the trough, then slide sideways to connect.**

- Padded supports carry and align the laptop.
- An adjustable split cassette captures the original Dell plug.
- A separate chassis stop limits insertion.
- Planned compliance accommodates small alignment errors; a lift keeper prevents lifting while connected.

The branch includes a CAD preview, STEP model, editable parameters, and measurement checklist. **Itâ€™s a concept, not yet a printable precision-fit dock.**

Can you send straight-on photos of the laptopâ€™s left-side ports and the SD25TB5 plug beside a ruler? We need their actual geometry before finalizing the clamp and alignment.

## User

that is super ugly. find the images / engineering data you need online. assume hinge down. add 2x 120mm fans strategically to create suction below the hinge such that the laptop natural ventilation works and air is drawn through the chassis. keep is low profile, just tall enough to align and engage the laptop up to the height of the plug.

## User

fans can be on the desk side (lid side, opposite vents) of the whole thing, sucking air out of a ducted space that curves below the machine

## User

need provision for fine tuning port location in space after this is built. either cap and shims, threaded clamps, something...

## Assistant

Added the adjustable cassette to the [revised D1 design](https://github.com/thereprocase/5680-dock/tree/main/desk-dock/D1).

| Adjustment | Provision |
|---|---|
| Height | Â±5 mm screw jack, separate locks |
| Across laptop thickness | Â±3 mm slide, separate locks |
| Insertion depth | Â±5 mm slide, separate chassis stop |
| Plug replacement | Removable cap preserves alignment |

The redesign places **both fans on the lid side**, drawing through a curved duct beneath the hinge. The main deck is about **50 mm high**; only the plug support rises higher.

!:chatgpt-content-reference{index="0"}

I extracted the port and plug geometry from Dellâ€™s 3D assets. The adjustment parts clear at 27 sampled positions. **Hardware detailing and physical fit/cooling tests remain before a print release.**

## User

fans should be near vertical. create an animation showing the laptop going in and out of the thing

## Assistant

Fans now sit **10Â° from vertical**, with curved ducts beneath the hinge and the adjustable plug holder retained.

!:chatgpt-content-reference{index="0"}

:chatgpt-content-reference{index="1"} Â· [Updated CAD on GitHub](https://github.com/thereprocase/5680-dock/tree/main/desk-dock/D2)

Sampled docking clearances pass. Physical fit and cooling remain untested.

## User

You have some kind of misunderstanding of the laptop geometry. It sits left of me, hinge down, lid towards me, dock plug on the left of the keyboard)(far side)

[User attached 1 image; image contents were not included]

## User

tilt the fans the other way, so they point upwards at 15 degrees above the desk. make sure the plenum is large enough to remove air efficiently from the hinge and the openings are the right size and shape to avoid whistling.

## Assistant

Doneâ€”the fans now exhaust **15Â° upward**, with the plug at the corrected far end.

I enlarged the plenum to **2.76 L**, rounded the hinge openings, and added spaced wire guards. At an assumed **30 CFM total**, opening velocities stay around **2.3â€“2.6 m/s**. These changes address turbulence and noise mechanisms described by [Fantech](https://www.fantech.com.au/Content.aspx?ContentID=L5&category=dos-and-donts); confirming whistle-free operation requires a prototype.

!:chatgpt-content-reference{index="0"}

:chatgpt-content-reference{index="1"} Â· [CAD and sizing report](https://github.com/thereprocase/5680-dock/tree/main/desk-dock/D4)

## User

seems a little awkward, can you give this some aesthetic polish and make everything self aligning in terms of sliding the laptop down and then over?

## User

I don't mind sliding the laptop against fixed cheeks. it'll live. just don't touch the rubber feet.

## User

a tiny lean to the right (from my perspective opposite the plugs) means you can engage against the bitter end of the machine by the hinge and against the lid? if you study the side profile images and create carefully scaled complex profiles.

## User

underside vent can just have some logical ribs that the case rides along, with like 80% void net free ventilation area and supporting ribs to hold the gravity load of the machine. ribs can align with places away from where the fan vents outlet.

## User

that's dell's exhaust right? at the hinge? the intake are the bottom pan grilles.

## Assistant

Yes. **The bottom-pan grilles are the intake; the hinge area is the exhaust.**

The intended path is:

**Room air â†’ bottom-pan grilles â†’ Dellâ€™s internal fans and heat sinks â†’ hinge exhaust â†’ our plenum â†’ auxiliary fans.**

The open ribs sit outside the intake grilles. The sealed plenum collects exhaust below the hinge.

## User

show me the latest and greatest? can I get an exploded viewer like the other thigns in teh dell github?

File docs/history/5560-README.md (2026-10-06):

# Laptop wall mount — Minimalist M1 and ducted Rev H

**New independent design:** [Precision 5680 hinge-down desk dock](desk-dock/README.md)
uses two lid-side 120 mm extraction fans, a curved under-hinge duct and an
SD25TB5 plug cassette with height, lateral and depth adjustment. D5 adds profiled fixed guides, a 2° lidward lean, rubber-foot
clearance and a 90% open rib structure, with rounded fan bezels and an adjustment
cover. The current package includes CAD, a docking animation and contact evidence.
Physical fit, print details and cooling remain to be qualified.

Two independent prototypes: **Minimalist M1** uses lighter open arms and fan
cradles with an optional indexed airflow dam; **Rev H** preserves the ducted
prototype and its already-printed arms. Future ducted revisions can change the
arms, size range and airflow adjustment too.

[Explore both designs](https://thereprocase.github.io/dell-5560-wall-mount/) ·
[Print and assembly guide](https://thereprocase.github.io/dell-5560-wall-mount/minimalist-guide.html)

## Minimalist M1.1

[5560 native + print package](docs/downloads/Minimalist_M1_5560.zip) ·
[Fit coupon package](docs/downloads/Minimalist_M1_Fit_Coupons.zip) ·
[Editable nominal FreeCAD](minimalist/Laptop_Wall_Mount_Minimalist.FCStd) ·
[Six native size presets](minimalist/presets/) ·
[Construction and validation](minimalist/README.md)

The nominal complete set is **400.55 g / 15 h 42 m 30 s** in OrcaSlicer 2.4.2,
using P1S / ASA / 0.4 mm / 0.20 mm / 6 walls / 100% fill / 8 mm brim. That is
66.2% less estimated filament than the full Rev H set under the same process.
Times include each layout's plate overhead. These are slicer estimates, not
measured printing or cooling results.

Print one each of **01–08 plus 21_all_hardware**: nine plates. The twelve
individual files 09–20 are alternatives for replacement hardware, already
included on plate 21. STEP, STL and geometry-only 3MF are alternative formats.
The assembled STEP is for inspection. Keep the supplied print orientations.

All six dimensioned width/depth/thickness examples were recomputed at all nine
dam indices. Native geometry, intended 0.30 mm gaps, saved/reopened models,
STEP roundtrips, closed meshes and bed/brim/cutter clearance passed. Nominal
Orca paths have no disconnected floating components. The expanded screen
finds up to 8.99 mm of overhang-wall path without prior-layer support; the
bridge-tagged maximum is 3.02 mm. The coupon includes the fan-hanger and dam
slot interfaces in their full-part build directions. Physical fit, printed
retention, long-term ASA creep, anchors and cooling remain to be qualified.

### M1.1: carry the wall pad into the arm

Printing an arm on its side puts much of its load path within the layers, but
its wall pads extend beyond the arm’s 12 mm thickness. The original transition
left a small section just above that layer. The reinforcement grows each pad
from 24 to 32 mm tall and adds a pair of 6 mm webs, tapering 16 mm forward from
the pad face. Their roots run through the full arm thickness, including the
nearby window, so they begin at the bed instead of bridging onto a late layer.

| Original junction | Reinforced junction |
|---|---|
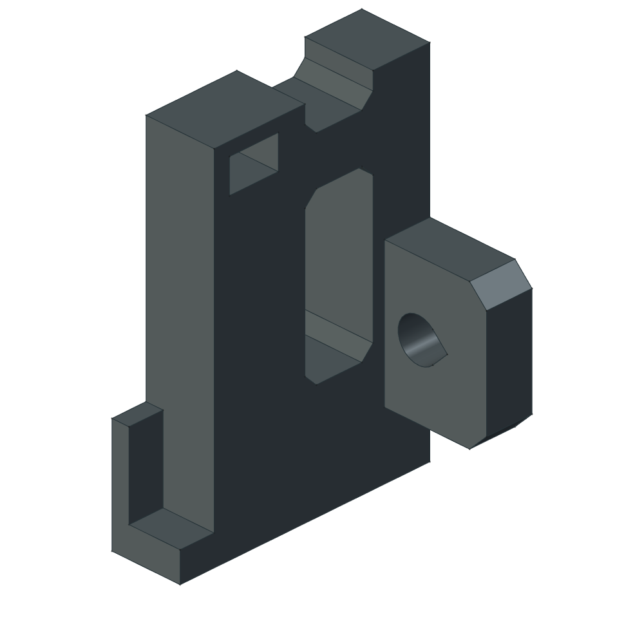
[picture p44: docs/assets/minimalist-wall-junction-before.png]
Original Minimalist wall pad and arm junction
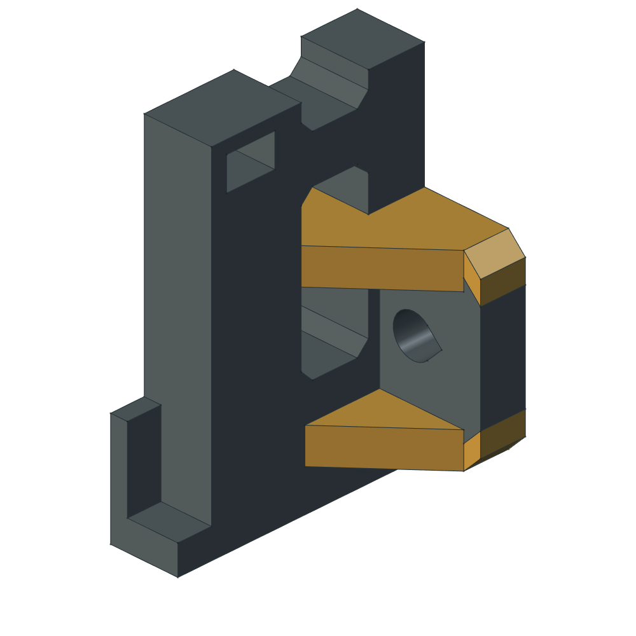
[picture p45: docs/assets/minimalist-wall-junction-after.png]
Reinforced junction with added material highlighted in gold
|  |  |

Gold shows added material in the native CAD comparison; the arm prints as one
fused part. Bolt centers and bores stay at their existing locations. The upper
dam has a matching tapered clearance notch so it can still traverse all nine
ladder positions. **Upgrade arms 01 and 02, plus dams 07 and 08 if using the dam**; the other sixteen
parts retain their geometry.

At a section just beyond the original 12 mm arm thickness, the material area
in each wall junction increases from **192 to approximately 416 mm²**. The
nominal arm pair adds **13.54 g of solid CAD** at 1.05 g/cm³. This is an area
comparison, not a claim of doubled tested strength: warm ASA, layer bonding,
fasteners and wall anchors still need physical qualification.

The revised complete set adds **12.50 g and 17 m 36 s** in Orca compared with
M1.0; the dam relief offsets a little of the extra arm material.

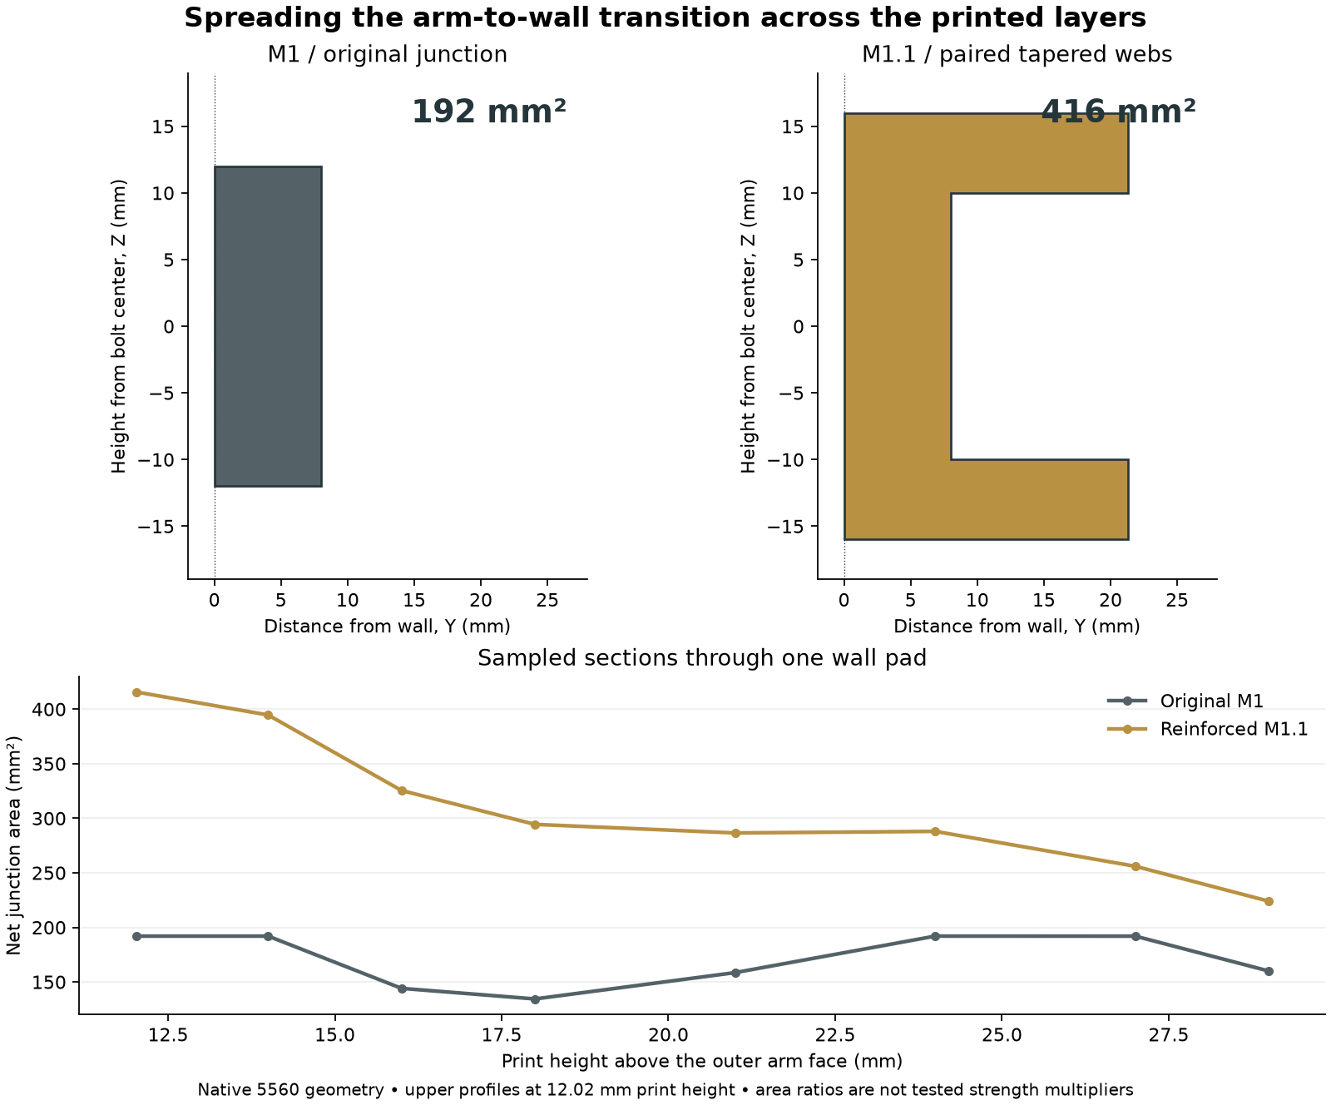
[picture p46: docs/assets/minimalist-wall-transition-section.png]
Actual print-layer sections before and after reinforcement


[Section data and assumptions](minimalist/reports/wall-transition-review.json) ·
[Native section calculation](minimalist/wall_transition_review.py)

## Ducted Rev H prototype

[All 14 print-oriented STEP files + corrected Orca previews](docs/downloads/Precision_5560_RevH_Prototype_STEP.zip) ·
[Orca bridge instructions](print_release_step/ORCA_BRIDGE_REVIEW.txt) ·
[STL/3MF print set](print_release/) ·
[Native FreeCAD](freecad/Precision_5560_Native.FCStd) ·
[Assembled STEP](freecad/Precision_5560_Native.step)

For ducts 03 and 04, keep the baked inlet-down orientation and set both
**Bridge direction and Internal bridge direction to 180°**, with Relative
bridge angle and Align infill direction to model off. Automatic direction
runs lengthwise along the slots. The corrected paths cross them, with a
maximum unsupported span of 5.19 mm and no disconnected floating components.
This is a toolpath screen, not an ASA bridge test. Re-slice for your spool.

The original `print_ready/`, root STEP, CadQuery source and Fusion/Onshape
ports remain **Revision F history/baselines**. Rev H's arm geometry is preserved
as prototype history; it is not a permanent constraint on later designs.

## How the shape was developed

The design story and its working images belong here alongside the finished
files. These stages describe the **original Revision F ducted prototype**:
its dimensions, fixed joints and historical simulation results are recorded
as they were developed. Minimalist M1 uses its own arms, shorter front tines
and removable ladder keys; use the current guide above for printing it.

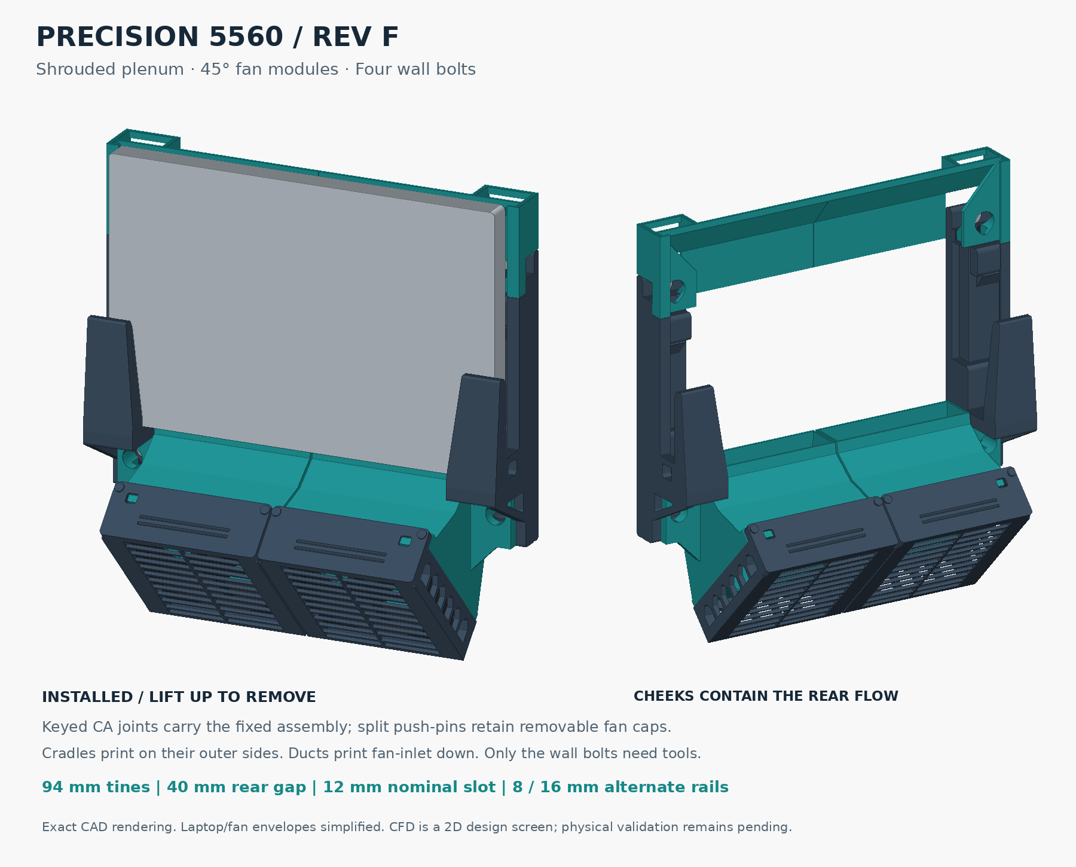
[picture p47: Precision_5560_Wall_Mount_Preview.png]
Original Revision F installed and empty assembly, rendered from CAD


### 1. Define fit and access

> “The hinge will go up so that the hot air escapes up and the fans can go on the bottom…”

The laptop sits vertically, underside toward the wall, with a 40 mm rear gap. A 344.4 × 230.3 × 20 mm envelope controls fit. The 26 mm bare slot allows for contact pads.

> “…make the tines on the front a little bit taller…”

The front tines are 94 mm tall. Four Ø7 mm wall holes face the room through clear Ø16 mm tool paths. We checked bolt access and laptop removal with the assembly in place. The laptop needs a 105 mm lift before moving forward; allow 110 mm overhead.

### 2. Support the laptop's intake

> “…doesn't have to seal, just has to be high pressure at vent high velocity beyond.”

The airflow goal became a plenum with a controlled outlet. Side cheeks limit leakage. A separate upper rail contracts the gap above the intake band, keeping the laptop vertical and the outlet width interchangeable.

Restricting the outlet can raise upstream pressure while reducing flow. The useful question was how much pressure each slot retained at the intake, and what exit velocity remained.

### 3. Locate the active vents

> “…download and scale images and cross sections of the machine to estimate its profile geometry?”

We scaled Dell side views and an inside-base-cover image against the published width and depth. The inside view revealed a covered center behind the broad exterior grille, leaving two estimated 70 × 40 mm intake regions near X = ±111 mm.

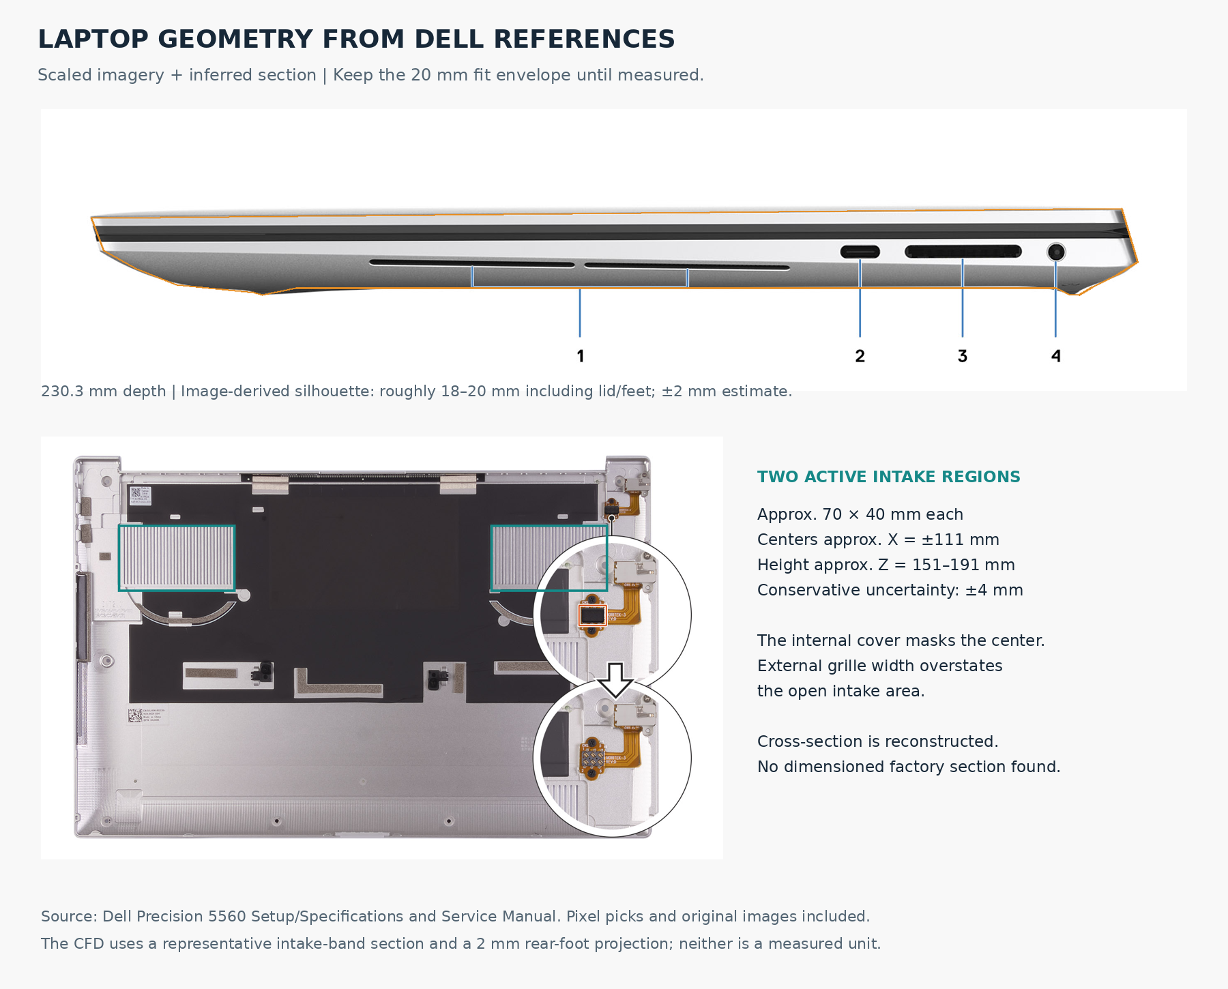
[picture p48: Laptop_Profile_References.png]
Scaled Dell references and estimated profile


The estimated intake band ends near Z = 191 mm, with ±4 mm location uncertainty. The contraction starts at 198 mm, reaches its throat at 226 mm and exits at 232 mm, near the hinge. No dimensioned factory section was found; the reconstructed profile has an estimated ±2 mm uncertainty. Check the actual machine before assembly.

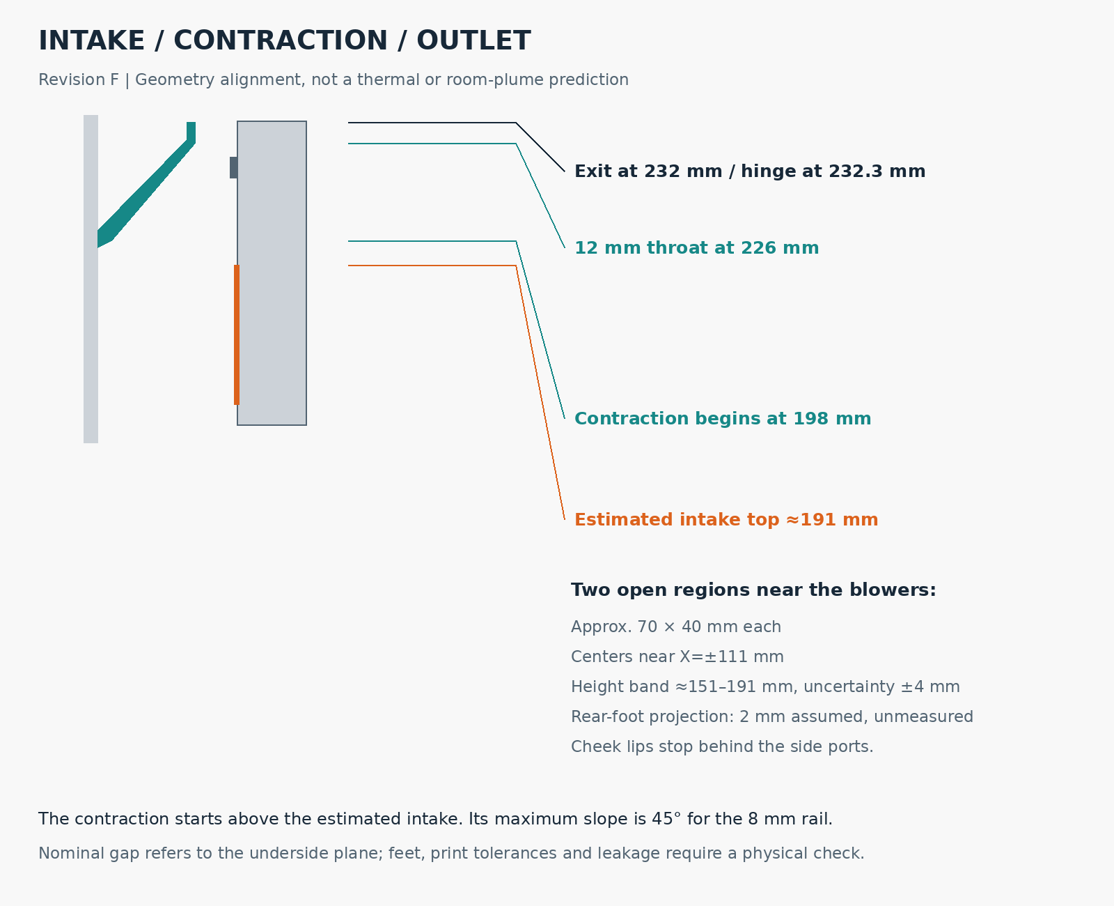
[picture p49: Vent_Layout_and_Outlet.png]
Image-derived intake band and original contraction/outlet stations


The [profile reconstruction data](profile_reconstruction.json) retain the pixel picks, scale factors, source hashes and uncertainty. The [estimated-profile STEP](REFERENCE_Estimated_Laptop_Profile.step) is the resulting reference shape, not manufacturer CAD.

### 4. Design for the print orientation

> “I would like to print the brackets on their side for strength, and not on their back.”

> “Also bridges are just fine, they're usually printable. Unsupported overhangs are bad.”

The brackets print on their outer sides. Ducts print inlet down; outlet rails print lip down. Sloped roofs support the next layer, while short bridges close box sections and dovetail grooves.

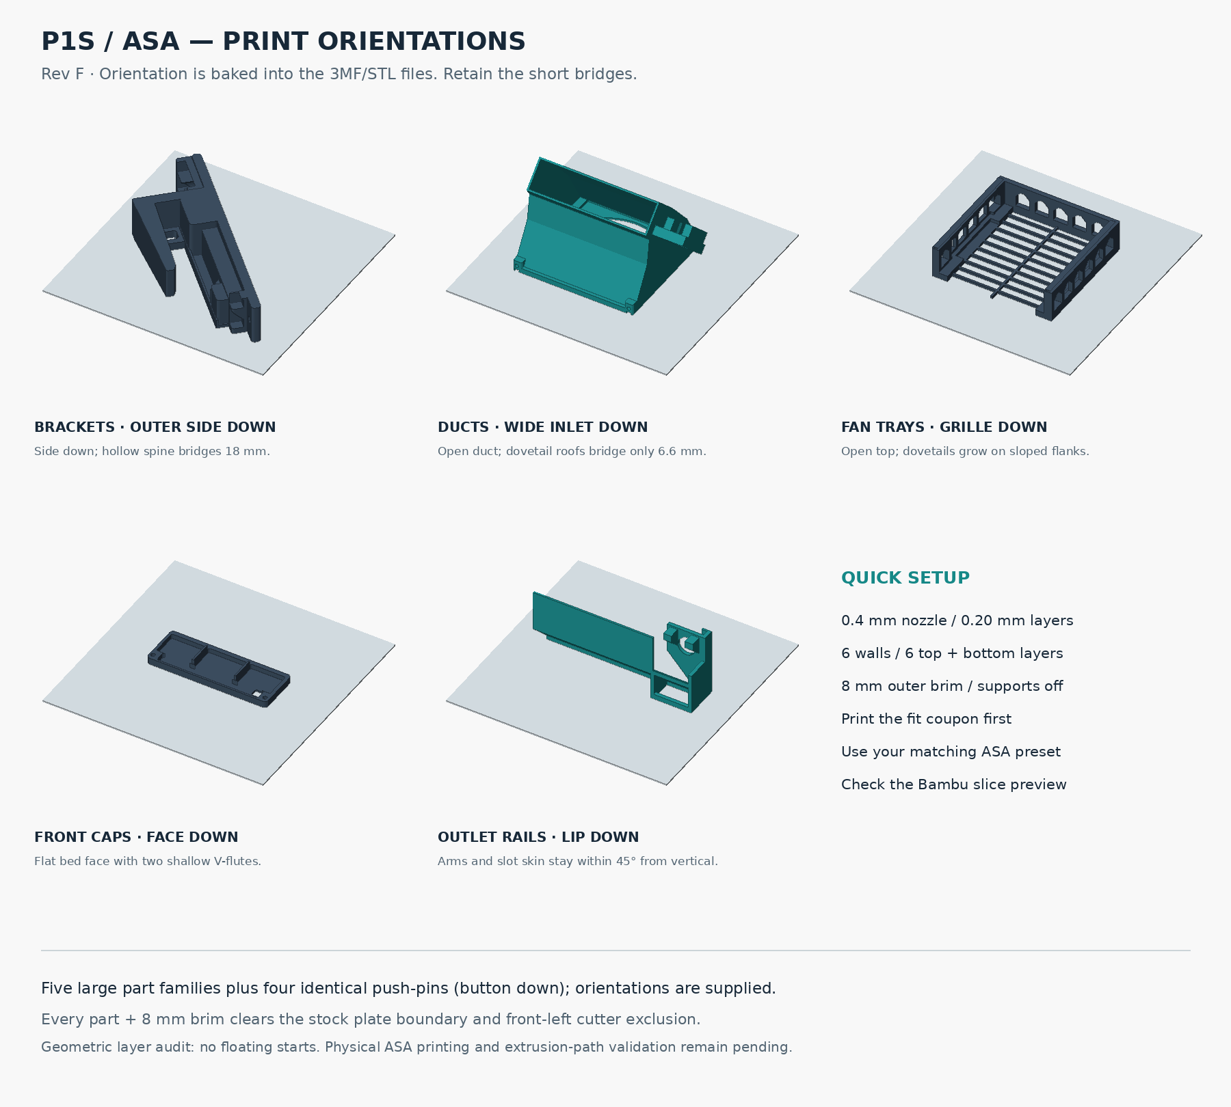
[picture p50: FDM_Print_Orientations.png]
Supplied print orientations


At the Revision F checkpoint, the 0.20 mm geometric layer audit found no floating starts and an 18 mm longest intentional bridge. Each part and its 8 mm brim fit the P1S bed and avoided the cutter exclusion. That was a geometry screen, before an actual slicer review. The later Rev H Orca review above caught a lengthwise bridge across a long slot and corrected its direction; physical ASA bridge quality still needs a print check.

### 5. Reduce material along the load path

> “I feel like we could get really creative and save a ton of plastic here.”

We hollowed the brackets, thinned the duct skins and pocketed the trays and caps. Material remains at bearing shoulders, bracket roots and wall holes. This used explicit geometry and section calculations; no topology or generative solver was run.

We extracted net section properties every 0.5 mm, including voids and unsymmetric bending. The structural screen uses a 2.5 kg laptop, 6 kg installation, 3g acceleration and a 50 N outward hinge pull. The minimum ratio of assumed stress limit to calculated stress is 1.19. This is a screening result; bonds, anchors and warm ASA creep remain unqualified.

Revision F uses **1,177.3 cm³ of solid CAD, 35.0% less than Revision D** at equal fill policy. The latest containment and assembly changes add 13.1 cm³ to the lightweight Revision E.

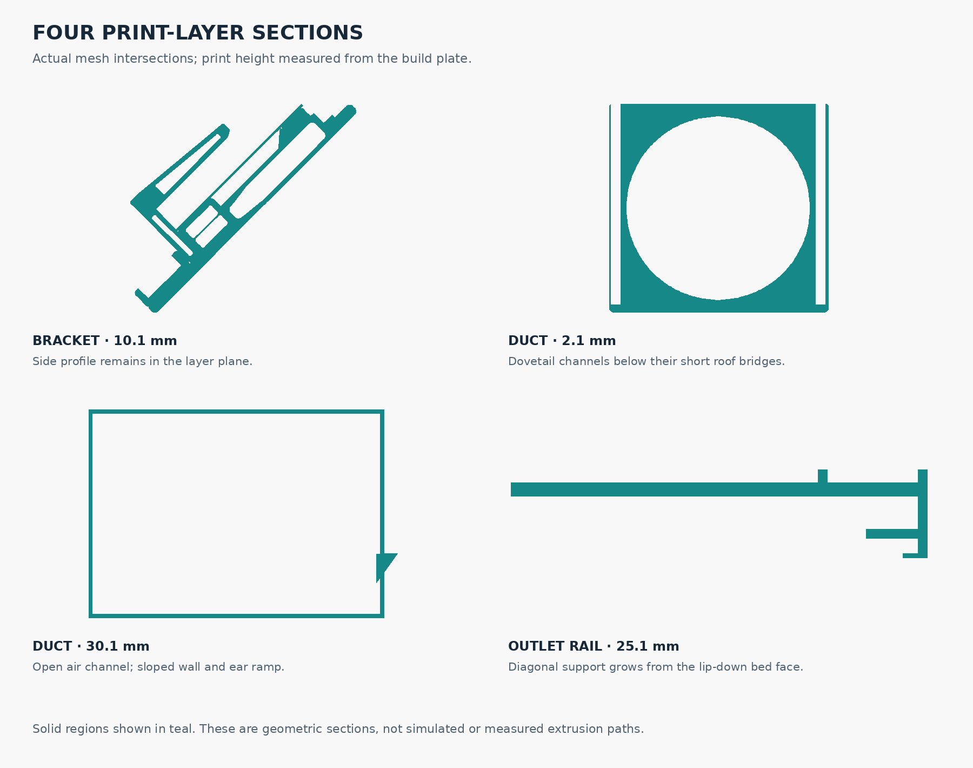
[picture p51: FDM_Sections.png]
Sections through the actual Revision F print geometry


### 6. Keep service parts removable

> “Can we also make it tool free / ca glue assembly, except for the four wall bolts?”

Keyed lap joints connect the fixed ducts and outlet rails. Their shoulders carry vertical load; CA resists withdrawal. Fan trays slide in dry, and two split pins retain each cap.

> “…have the fans angle down so they're blowing at a 45 to the gap instead of straight in?”

The fan intakes face down and outward. Air flows upward and wallward at 45°. Cheeks contain the rear flow while leaving side ports accessible.

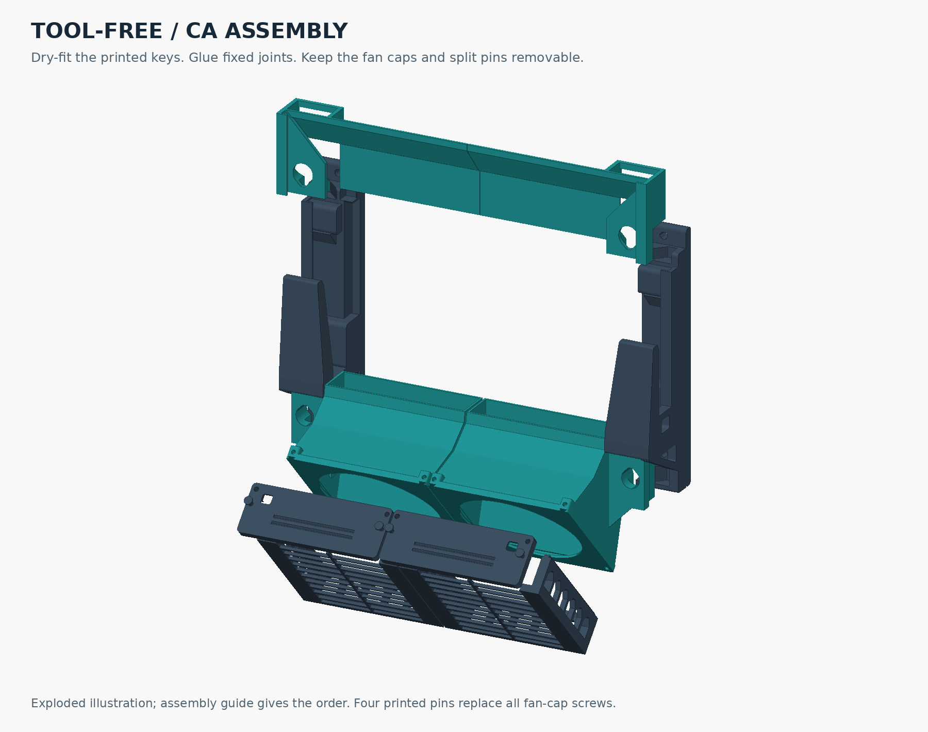
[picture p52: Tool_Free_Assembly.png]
Fixed joints and removable fan assemblies


The screened loads require 47.8 N of outward retention per duct and 7.4 N per pin. Adhesive and pin tests must establish that retention before service.

### 7. Compare the outlet slots

> “And do some cfd to design the plenum and slot?”

Eight OpenFOAM v1912 cases compare slot width, lower-turn geometry, mesh size, supply pressure and intake demand. The model uses steady incompressible RANS with k–omega SST in a sealed 2D section.

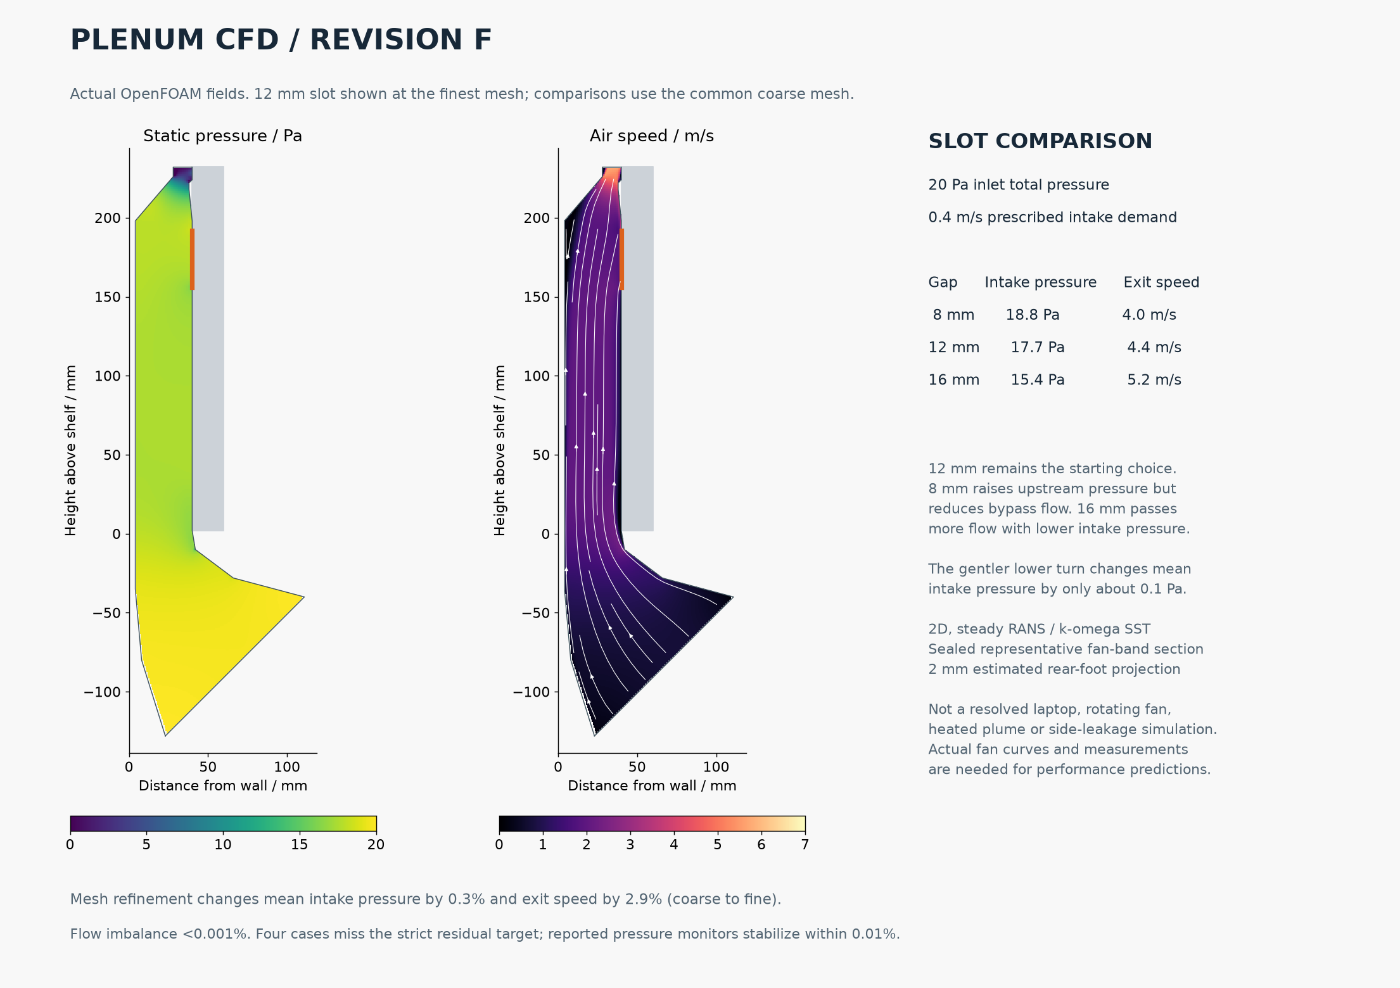
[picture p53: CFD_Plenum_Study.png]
Calculated pressure and velocity fields


At an assumed 20 Pa inlet total pressure and prescribed 0.4 m/s intake demand:

| Outlet | Mean intake pressure | Mean exit speed |
|---|---:|---:|
| 8 mm | 18.80 Pa | 4.01 m/s |
| **12 mm** | **17.67 Pa** | **4.42 m/s** |
| 16 mm | 15.43 Pa | 5.16 m/s |

The narrow slot retained more pressure; the wide slot produced a faster exit. We kept **12 mm** as the starting compromise. The curved lower turn improved intake pressure by only 0.11 Pa on the common mesh, giving little reason to refine the bend further before testing.

All meshes passed `checkMesh`. Flow imbalance stayed below 0.001%; mesh refinement changed mean intake pressure by about 0.3% and exit speed by 2.9%. Four cases missed the strict residual target despite stable mean-pressure monitors.

The model prescribes laptop intake flow and assumes fan pressure. It omits real fan curves, internal laptop resistance, side leakage, heat transfer and the room plume. The results compare slot behavior; actual cooling, total CFM and exhaust carry distance require measurements.

### 8. Specify the fits

> “what tolerances did you assume for slide to fit parts?”

The dovetail has 0.30 mm horizontal allowance per side, 0.30 mm crown clearance and 0.20 mm root clearance. Clearance normal to the sloping flank is smaller. Fixed-key pockets use 0.30 mm nominal offsets plus roof relief. Pins use a Ø4.0 mm shaft, Ø4.1 mm socket and Ø4.2 mm split crown.

No global ASA shrink correction is applied. Print the coupons, inspect elephant foot and adjust individual interfaces as needed. Full-length tray engagement also needs a warping check. See [TOLERANCES.md](TOLERANCES.md).

### 9. Reproduce and test

The workflow followed the interfaces: establish fit, reconstruct the vents, build the solids, check loads and service motions, audit print support, then compare airflow variants. [DIALOGUE.md](DIALOGUE.md) preserves the available prompts in order.

| Software | Use |
|---|---|
| Python 3.12; CadQuery 2.8.0 / Open CASCADE | Parametric solids, sections, STEP export and interference checks |
| NumPy; trimesh 5.1.0; Shapely 2.1.2; rtree; NetworkX | Mesh, layer support and connectivity checks |
| Pillow | CAD renders and reference-image annotations |
| Matplotlib; SciPy; VTK | CFD postprocessing and field plots |
| OpenFOAM v1912 | Meshing, mesh checks, flow solution and field export |
| Bambu Studio 2.8.2.61 profile sources | Historical Revision F starting settings; current preparation uses OrcaSlicer |
| Git / GitHub | Source, design files and analysis records |

[PROCESS.md](PROCESS.md) gives the commands; [requirements.txt](requirements.txt) records the Python dependencies. The [engineering report](ENGINEERING_REPORT.md) covers dimensions, assumptions, loads and verification.

Next: measure the laptop, print the coupons, test joint retention and warm structural behavior, then measure intake pressure and workload temperatures with the selected fans and outlet rails. Use those results to decide whether a coupled 3D or thermal model would change the design.

**Printing:** follow the [P1S ASA guide](P1S_ASA_Print_Guide.md), retain the supplied orientations and inspect the slice. Files are standard 3MF/STL models. Print the individual parts; reference STEP assemblies are for fit inspection.

## Rev H engineering history

Revision H adds three R12 internal tangent blends per duct and two R14 exterior
support blends. Inlet/outlet profiles, printed arms, and 0.30 mm interfaces
remain unchanged. The other twelve parts retain the prior release geometry.
See [flow validation](freecad/flow_validation.json) for sampled wall thickness
and inlet-down overhang checks. Cooling performance has not been measured.

- Closed rail roofs and end windows while retaining the exhaust slot and open back.
- Contoured the rail shoulder with 0.30 mm clearance to the frozen printed arm.
- Rounded exposed tips, matched cover outlines, and used print-aware corner bevels.
- Set the cap/duct/tray interfaces to measured 0.30 mm gaps on both sides.
- Corrected dovetail clearance normal to the sloping flank.
- Added separate editable native loft-skin patches to close the unintended duct-wall notches.
- Preserved pin retention, fixed mounting shoulders, screw access and service motions.

Final CAD checks: **14 valid solids, 176 fully constrained sketches**, zero
additional wall loss, unchanged frozen arms, and passing sampled service paths.
All 14 print meshes are closed and their oriented bounds plus brims fit the P1S.
Physical fit, retention and ASA bridging remain to be checked. Both duct
toolpaths have now been screened with the corrected Orca bridge direction.

[Fit-and-finish review](freecad/ADJACENT_FIT_REVIEW.md) ·
[Native model guide](freecad/README.md) ·
[Final acceptance JSON](freecad/complete_fit_review.json) ·
[Print manifest](print_release/manifest.json)

## Airflow research and technical drawings

Two 120 mm fans feed the rear plenum; the upper contraction directs bypass flow
past the hinge exhaust. The project includes the original 2D slot study and a
later exploratory 3D installed-flow case with traced laptop intake assumptions.

[Seven-sheet A3 technical review](docs/simulation/installed-airflow-2026-09-07/Precision_5560_CFD_Technical_Review.pdf) ·
[Drawing package](docs/simulation/installed-airflow-2026-09-07/) ·
[3D CFD run notes](fusion/cfd/TRACED_RUN_NOTES.md) ·
[2D CFD report](CFD_Design_Report.md)

The gallery is Revision F exploratory evidence. The [Revision H transient commissioning report](https://thereprocase.github.io/dell-5560-wall-mount/simulation/revh-transient/) includes an 18.2 million-cell mesh with 0.25 mm edge targets, raw samples, plots and a four-frame startup animation. Expanded mesh checks fail; the diagnostic restart completed only 0.0203084 ms of the planned 2 ms. Shedding, Bernoulli suction and validation are not established. The 3D
case uses uncalibrated constant-force fan assumptions, no thermal solution,
and did not meet its strict convergence target. It is not a measured hardware
performance claim.

## Project history

- [Minimalist workflow and reproduction](minimalist/README.md)
- [Original design narrative](docs/REVISION_F_DESIGN_STORY.md)
- [FreeCAD workflow notebook](freecad/RESEARCH_NOTES.md)
- [Fusion native port and CFD work](fusion/README.md)
- [Onshape pilot and API research](onshape/README.md)
- [Engineering report](ENGINEERING_REPORT.md) and [source attribution](SOURCES.md)

MIT licensed project. Dell reference images are attributed separately in
[SOURCES.md](SOURCES.md). Third-party viewer code retains its own MIT notice.
This project is independent of Dell, Bambu Lab and Autodesk.

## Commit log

2026-10-06 Publish privacy-reviewed laptop hardware snapshot
    [00-START-HERE-fastener-fit.3mf, 00_FIT_COUPONS.3mf, 00_FIT_COUPONS.stl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]
2026-10-25 Point cross-links at the current dock and wall-mount pages and redirect the outdated copies
